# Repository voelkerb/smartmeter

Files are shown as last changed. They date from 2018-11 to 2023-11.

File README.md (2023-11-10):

# SmartMeter

The SmartMeter is a WiFi and Ethernet equipped electricity meter that to be installed in a home's fuse box. 
The development started with hardware [Version 1.0](/Schematic/Version_1). It consists of an ESP32 microcontroller and a dedicated electricity monitoring chip. As the main idea behind this project was to record voltage and current waveforms at higher frequencies, several drawbacks for this use case were fixed with Hardware [Version 2.0](/Schematic/Version_2). It features the same Microcontroller but with 8MB internal storage for data buffering, an RTC for precise time keeping while sampling, a faster USB serial connection with up to 12Mbaud and a 100Mbit ethernet interface.

If you are just interested in the consumption of a single appliance, see the [PowerMeter](https://github.com/voelkerb/powermeter) instead.

## Why to use?
It's open source, easy to use, easy to build and offers lots of flexibility. 

The hardware is...
* tested to work reliable with 230V.
* rather cheap (all components sum up to around 70€).

The firmware supports...
* existing 2.4GHz WPA2 networks or can create its own network.
* to receive commands via USB, TCP or MQTT.
* to store the configuration in the internal non volatile memory.
* to provide data at sampling rates from 1/5Hz all the way up to 32kHz.
* to calibrate the measurements.
* integration into most existing smart home systems e.g. HomeKit (via homebridge and MQTT).
* FFMpeg streaming. This allows to store high frequency data directly into files (e.g. MKV).

## How to build one?
You want to build your own SmartMeter? As the PCBs are provided in this repo, you can simply make your own.

Depending on your requirements, you might either build [Version 1.0](/Schematic/Version_1) or [Version 2.0](/Schematic/Version_2). 
* [Version 1.0](/Schematic/Version_1)
    * Benefits: 
        * The parts are cheaper (around 50€).
    * Drawbacks:
        * Cannot stream data of more than 8kHz.
        * No ethernet interface.
* [Version 2.0](/Schematic/Version_2)
    * Benefits: 
        * 8MB of internal storage allows to buffer data. If you stream high frequency data at e.g. 2kHz, this can hold up to 200s of data on network dropouts.
        * An RTC keeps track of time allowing you to synchronize sampling rates during high frequency sampling.
    * Drawbacks:
        * A little bit more expensive (parts around 70€).

Steps to build your own SmartMeter:
1. Make the PCB ([Version 1.0](/Schematic/Version_1) or [Version 2.0](/Schematic/Version_2)) with [SampleBoard](/Schematic/SampleBoard)). I recommend to use [JLC](https://jlcpcb.com) as it is super cheap and the quality is still decent.
2. Buy the parts listed under [BOM](/BOM).
3. Solder everything together. We used a small reflow oven, but it could also be done using a fine soldering iron. 
4. Buy a matching housing. We highly recommend to use [this one](https://www.voelkner.de/products/694730/Weltron-MR9-C-FA-RAL7035-ABS-Hutschienen-Gehaeuse-157.5-x-90-x-68-ABS-Lichtgrau-RAL-7035-1St..html) as the PCB was specially designed for it, the mounting holes match, and it is safe to use with 230V. It further can be installed inside fuse boxes at regular DIN rails. Also see the CAM milling files to generate cutouts for USB and ethernet and mounting plates for the sampler board (see [Housing](/Hosuing)). 
5. Install the SmartMeter at the DIN rail inside fuse box (that should be done by an electrician).

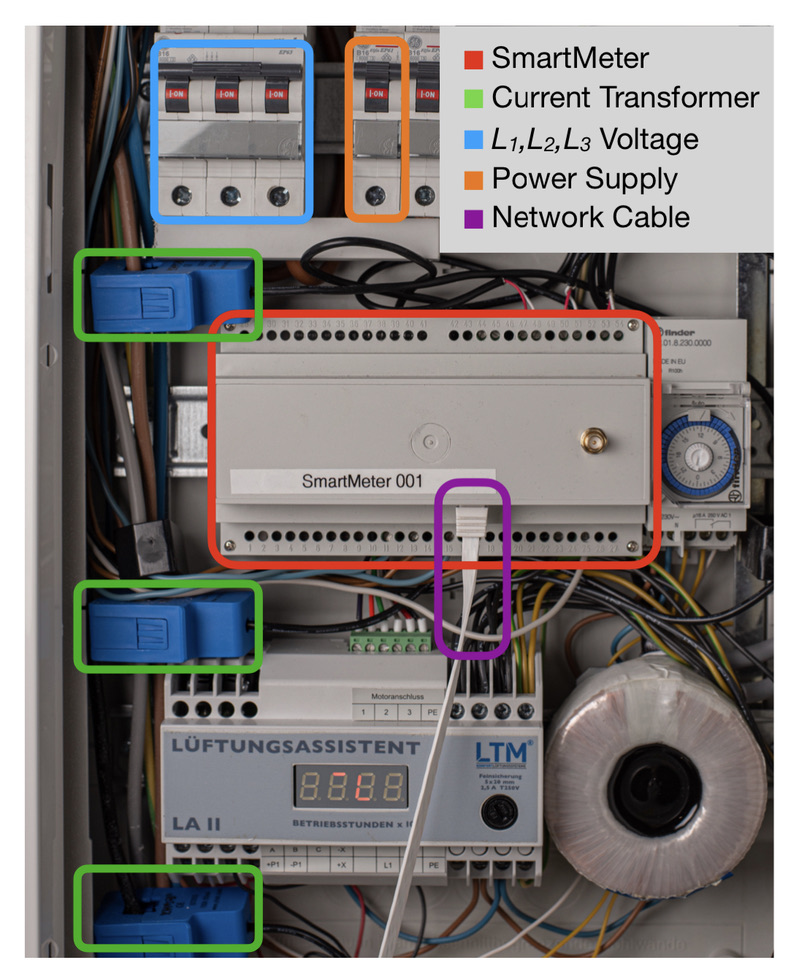
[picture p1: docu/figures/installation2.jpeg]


6. Wire the SmartMeter using the following diagram. 

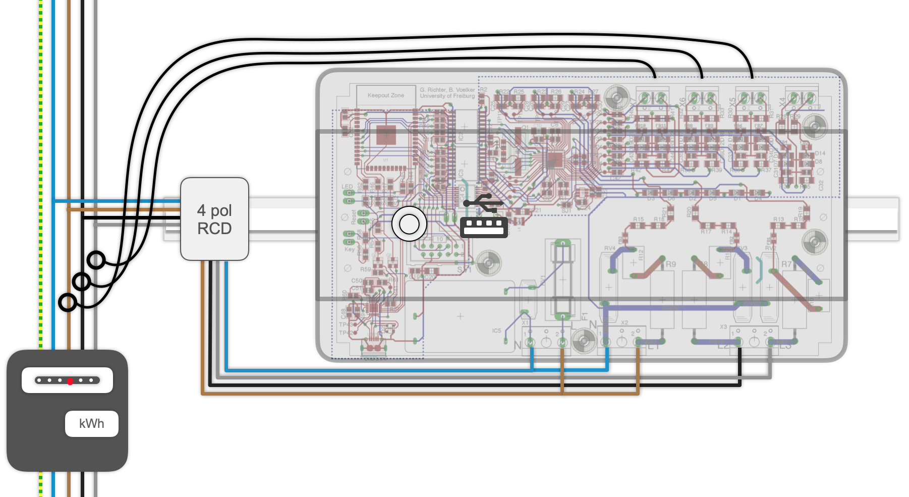
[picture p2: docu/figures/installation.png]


7. Upload the [firmware](/Firmware) according to the instructions for your version. 
8. Interface with the SmartMeter accordingly as stated [here](/docu/README_Firmware_Cmds.md) 

# Use cases
## Smart homes
There are plenty of use cases for a smart plug inside a smart home.
* Get the power consumption of your home using a voice assistant or your smartphone
* Include it in home automation software to switch appliances based on an automation. There are lots of possibilities here, e.g.: 
    * Trigger an alert if the consumption exceeds a limit.
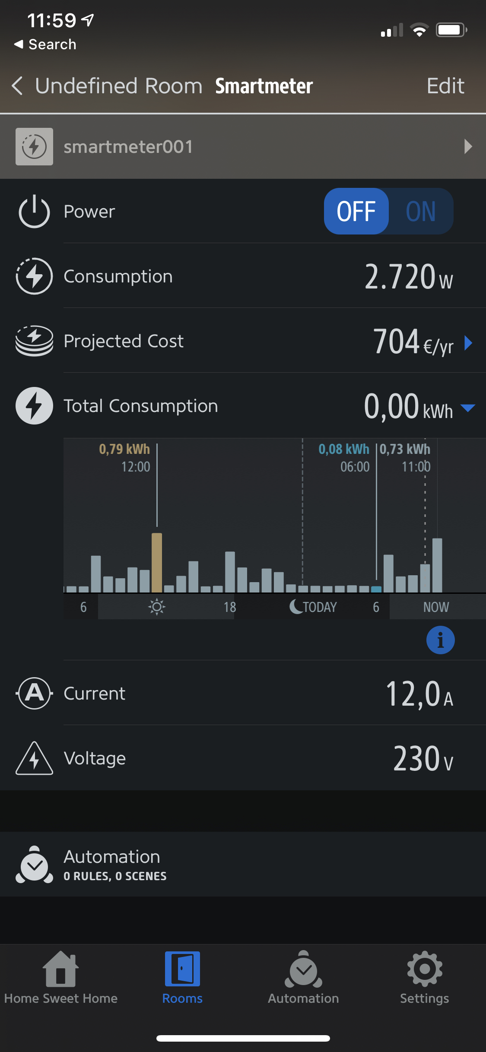
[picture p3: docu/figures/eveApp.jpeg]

* Implement your own Non-Intrusive Load Monitoring System to get the individual appliance power consumption without adding smart plugs to each and every appliance.
* Monitor the power consumption of your home over day.
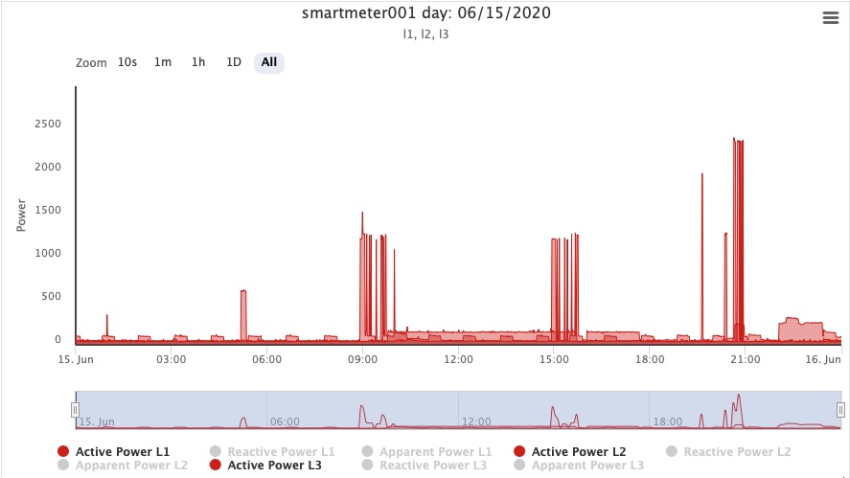
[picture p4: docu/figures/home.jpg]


## For research purpose
* Analyze high frequency voltage and current waveforms.
* Record high frequency electricity datasets (see e.g. the [FIRED](https://github.com/voelkerb/FIRED_dataset_helper) dataset which can be used for Non-Intrusive Load Monitoring).

# License:
## Firmware:
Copyright (c) 2019 Benjamin Völker. All rights reserved.
This work is licensed under the terms of the [CC 4.0 licence](https://creativecommons.org/licenses/by/4.0/).

## Hardware:
Copyright (c) 2019 Benjamin Völker. All rights reserved.
This work is licensed under the terms of the [TAPR Open Hardware License](https://web.tapr.org/TAPR_Open_Hardware_License_v1.0.txt).

# Reference

Please cite our publications if you compare to or use this system:
* Benjamin Völker, Philipp M. Scholl, and Bernd Becker. 2019. Semi-Automatic Generation and Labeling of Training Data for Non-intrusive Load Monitoring. In Proceedings of the Tenth ACM International Conference on Future Energy Systems (e-Energy '19). Association for Computing Machinery, New York, NY, USA, 17–23. DOI:https://doi.org/10.1145/3307772.3328295
 
* Benjamin Völker, Marc Pfeifer, Philipp M. Scholl, and Bernd Becker. 2020. FIRED: A Fully-labeled hIgh-fRequency Electricity Disaggregation Dataset. In Proceedings of the 7th ACM International Conference on Systems for Energy-Efficient Buildings, Cities, and Transportation (BuildSys '20). Association for Computing Machinery, New York, NY, USA, 294–297. DOI:https://doi.org/10.1145/3408308.3427623

* Völker, B.; Pfeifer, M.; Scholl, P.M.; Becker, B. A Framework to Generate and Label Datasets for Non-Intrusive Load Monitoring. Energies 2021, 14, 75. https://doi.org/10.3390/en14010075

Kudos also go to Gregor Richter for developing the first draft schematics prior to [Version 1.0](/Schematic/Version_1).

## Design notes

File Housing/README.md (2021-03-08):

[smartmeter]: (https://github.com/voelkerb/smartmeter)

# Rough PCB Model
You can use the [circuit board](housing/SmartMeter.SLDASM) design file to design custom enclosures for the PCBs.

We encourage you to use the off-the-shelf case which can be found at [here](https://www.voelkner.de/products/694730/Weltron-MR9-C-FA-RAL7035-ABS-Hutschienen-Gehaeuse-157.5-x-90-x-68-ABS-Lichtgrau-RAL-7035-1St..html) as you are working with 230V.
The PCBs were specially designed for this case and perfectly match into its mounting holes. The case offers a secure encapsulation, provides enough room and is rather inexpensive.

As the PCBs are designed in Eagle, the corresponding 3D models can also be imported directly in Fusion360.

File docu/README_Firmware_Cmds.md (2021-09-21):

[SmartMeter]: (https://github.com/voelkerb/SmartMeter)

# How to interface with a SmartMeter

## The Basics
The [SmartMeter] has to be connected to power. \
At first boot, the [SmartMeter] will open a WiFi-Network called "smartmeterX".\
It is not password protected, so you can simply connect to it. 
Open a TCP connection to IP ```smartmeterX.local``` (or ```192.168.4.1```) at port ```54321```.
This will show you basic information of the [SmartMeter] as a JSON encoded messages.
```bash
Info:{"cmd":"info","type":"SmartMeter","version":"2.2","compiled":"Mar_2_2021_09:57:58","sys_time":"03/02/2021 10:37:07.662","name":"smartmeterX","ip":"192.168.4.1","mqtt_server":"-","stream_server":"-","time_server":"time.google.com","sampling_rate":4000,"buffer_size":3670016,"psram":true,"rtc":false,"calV":1,"calI":1,"state":"idle","relay":1,"calibration":[1,1],"ssids":"[energywifi]","ssid":"-","rssi":-71,"bssid":"-"}
```
You will further notice that a lifeness log messages is sent each second.
We will further see how to use commands to interface with a SmartMeter.

**Each command sent to the [SmartMeter] over USB or a TCP channel requires JSON encoding and is answered by a JSON encoded answer message preceded by a the text "Info:". If an error occurred while processing the commmand, the error key is set true in the returned JSON.**

**Each command sent to the [PowerMeter] over USB or a TCP channel requires JSON encoding as ```{"cmd":<cmdName>,[optional]}``` and is answered by a JSON encoded answer message preceded by a the text "Info:". If an error occurred while processing the commmand, the error key is set true in the returned JSON.**

## Overview
| CMD | Description 
| --- |---|
| ["info"](#info) | Get basic information |
| ["getPower"](#getting-energy-data) | Get active, reactive and apparent power |
| ["getVoltage"](#getting-energy-data) | Get current RMS voltage level |
| ["getCurrent"](#getting-energy-data) | Get RMS current |
| ["getEnergy"](#getting-energy-data) | Get energy in Wh and time period |
| ["getPeriod"](#getting-energy-data) | Get current net frequency |
| ["getPhaseAngle"](#getting-energy-data) | Get phase angle between voltage and current  |
| ["mdns"](#name) | Set new mDNS and general [PowerMeter] name |
| ["addWifi"](#wifi) | Add WiFi AP |
| ["delWifi"](#wifi) | Remove WiFi AP |
| ["calibration"](#calibration) | Set calibration parameter |
| ["restart"](#restart) | Restart [PowerMeter] |
| ["dailyRestart"](#restart) | Schedule reset every day |
| ["factoryReset"](#reset) | Reset to standard values |
| ["basicReset"](#reset) | Reset everything but the name |
| ["resetEnergy"](#reset-energy) | Reset accumulated energy |
| ["sample"](#using-a-sampling-command) | Start receiving high frequency data |
| ["reqSamples"](#using-a-sampling-command) | Get certain amount of high frequency samples |
| ["cts"](#pause-streaming) | Allow/forbid to stream samples |
| ["stop"](#stop-streaming) | Stop receiving data |
| ["log"](#log-level) | Change log level |
| ["clearLog"](#log) | Clear logs |
| ["getLog"](#log) | Returns all warning and error log messages |
| ["mqttServer"](#mqtt) | Set MQTT server |
| ["streamServer"](#using-a-stream-server) | Set stream server |
| ["ntp"](#time-synchronization) | Trigger NTP sync |
| ["timeServer"](#time-synchronization) | Set time server for NTP |

## Info
```{"cmd":"info"}```\
The info command will print information about the [SmartMeter]. As this is the most often required command, it is automatically sent to each new connected TCP client. 

## Log Level
```{"cmd":"log","level":<logLevel>}```\
Choose between the following log levels: ```all, debug, info, warning, error```\
Each new connection is initialized with log level ```info```.
```bash
Info:{"error":false,"msg":"Log Level set to: warning"}
```

## Name
```{"cmd":"mdns","payload":{"name":"<newName>"}}```\
This command should be used to give the [SmartMeter] a new unique name.
It will be used to announce presence over MDNS and if no known network is found, an AP is opened using this name.

```bash
Info:[I]03/02 10:42:24: MDNS Name: smartmeterX
Info:{"error":false,"msg":"Set MDNS name to: smartmeterX","mdns_name":"smartmeterX"}
```

## Restart
```{"cmd":"restart"}```\
Restarts the [SmartMeter]. The TCP connection will be lost.

## Reset
```{"cmd":"factoryReset"}```\
Resets everything to defaults. The default values are:
- name: _smartmeterX_
- wifi aps: _energywifi_ -> (pwd: _silkykayak943_)
- timeserver: _time.google.com_
- streamserver: -
- mqtt broker: -
- _energy<LX><U/I>_ = 1.0
- _energy<LX>_ = 0
- _resetHour_ = _resetMinute_ = -1

If you want to reset everything except the name, use: ```{"cmd":"basicReset"}```

## Log
```{"cmd":"getLog"}```\
The [SmartMeter] has some decent logging capabilities. Despite logging over a connected TCP connection and Serial. _Warning_ and _Error_ messages are logged to internal flash memory.
The _getLog_ command will dump the all logs in the flash and contains two JSON response messages.
```bash
Info:{"cmd":"log","msg":"*** LOGFile *** [E]03/02 11:26:20: Cannot connect to MQTT Server -//n*** LOGFile *** "}
Info:{"error":false}
```
All newlines are replaces by "_//n_".\
To clear all log messages, use ```{"cmd":"clearLog"}```.

## Calibration
```{"cmd":"calibration","cal":[<calV_l1>,<calI_l1>,<calV_l2>,<calI_l2>,<calV_l3>,<calI_l3>]```\
Calibrate the [SmartMeter].
```<calV_LX>``` and ```<calI_LX>``` are floating point values with the default value 1.0.
Every measured voltage and current value is multiplied by the calibration factor. Power and Energy are multiplied by ```<calV_LX>```*```<calI_LX>```.

## Reset Energy
```{"cmd":"resetEnergy"}```\
Simply resets the accumulated energy stored in flash. 

## Time synchronization
```{"cmd":"ntp"}```\
Will perform an NTP time synchronization.
```
Info:[I]03/02 11:28:14: NTP synced with conf: 11
Info:{"msg":"Time synced","error":false,"current_time":"03/02/2021 11:27:40.182"}
```
To set a new NTP timeserver, use the command: ```{"cmd":"timeServer", "payload":{"server":"<serverAddress>"}}```. The _serverAddress_ can be also be its DNS name e.g. time.google.com
```bash
Info:[I]03/02 11:28:14: NTP synced with conf: 11
Info:{"error":false,"msg":"Set TimeServer address to: time.google.com","time_server":"time.google.com"}
```

## WiFi
Add wifi AP: ```{"cmd":"addWifi", "payload":{"ssid":"<ssidName>","pwd":"<pwdName>"}}```
```bash
Info:{"error":false,"ssid":"Test","pwd":"TestPwd","msg":"New Ap, SSID: Test, PW: TestPwd","ssids":"[energywifi, Test]"}
```
Remove a wifi AP: ```{"cmd":"delWifi", "payload":{"ssid":"<ssidName>"}}```
```bash
Info:{"error":false,"msg":"Removed SSID: Test","ssids":"[energywifi]"}
```

## MQTT
Once connected to an MQTT server, the SmartMeter will publish the current power consumption each 5 seconds and each state change of the relay. 
To set the MQTT server, use the command: ```{"cmd":"mqttServer", "payload":{"server":"<ServerAddress>"}}```
Currently, only the MQTT standard server port ```1883``` is supported. 
```bash
Info:[I]03/02 11:38:42: MQTT connected to 192.168.0.13
Info:[I]03/02 11:38:42: Subscribing to: SmartMeter/+
Info:[I]03/02 11:38:42: Subscribing to: SmartMeter/smartmeterX/+
Info:{"error":false,"msg":"Set MQTTServer address to: 192.168.0.13","mqtt_server":"192.168.0.13"}
```

NOTE: In sampling mode, MQTT is disabled for performance reason.

### Receiving MQTT messages
Each 5 seconds, information about the power consumption is sent.
It contains the sum of the _active power_ in _Watt_ and _active energy_ in _kWh_ of all grid lines, the mean of the _RMS voltage_ in _V_ of all grid lines, the sum of the _RMS current in _A_ of all grid lines and the current timestamp.
You can also enable 
```bash
powermeter/smartmeter001/state/sample {"power":1116.89,"current":4.82,"volt":236.56,"ts":"1614681575"}
```

### Sending MQTT messages
Mqtt can also be used to send any command. Special topics are used to switch the relay or to get basic electricity related measurements, but any of the available commands can be sent.
* Sample a single value using topic ```powermeter/<name>/sample``` and message one of ```v,i,p,q,s``` (_RMS voltage_,_RMS Current_, _active_, _reactive_, or _apparent power_ ). On no, or any other message, the _active power_ is sent.
  ```bash
  mosquitto_pub -h 192.168.0.13 -t 'powermeter/smartmeter001/sample' -m 'v'
  ````
  The response contains a JSON dictionary with the key _value_, _unit_ and _ts_, example:
  ```bash
  powermeter/smartmeter001/state/info {"value":"228.43,228.48,228.33","unit":"V","ts":"03/08/2021 11:42:34.848"}
  ```
  The individual values represent the values for the indivudal grid lines (L1, L2, L3)
* You can also send any command, which can be sent over a bare TCP connection using topic ```powermeter/<name>/cmd```
  ```bash
  mosquitto_pub -h 192.168.0.13 -t 'powermeter/smartmeter001/cmd' -m '{"cmd":"info"}'
  ````
* If you have multiple SmartMeters and want to send the message to all at the same time (e.g. to change some global settings such as the MQTT broker), you can simple ditch the specific SmartMeter name and all will answer. 
  ```bash
  powermeter/sample p
  powermeter/smartmeter001/state/sample {"value":"228.43,228.48,228.33","unit":"V","ts":"03/08/2021 11:42:34.848"}
  powermeter/SmartMeter002/state/sample {"value":"228.44,228.45,229.10","unit":"V","ts":"03/08/2021 11:42:34.947"}
  ...
  ```

## Getting Energy Data
To obtain one shot measurements, several commands exist for all kinds of electrical quantities.
All data is returned as a JSON dict with the command and the measurement's unit.

* ```{"cmd":"getPower"}```\
Returns active, reactive and apparent power.

* ```{"cmd":"getVoltage"}```\
Returns RMS voltage level.

* ```{"cmd":"getCurrent"}```\
Returns RMS current level.

* ```{"cmd":"getEnergy"}```\
  Returns energy since reset for all three supply legs. Includes time span.
  ```bash
  Info:{"error":false,"cmd":"getEnergy","energy":[10149.5684,5101.23238,4509.21022],"unit":"Wh","startTs":1632219770,"start":"09/20/2021 12:22:50.068","days":1}
  ```

* ```{"cmd":"getPeriod"}```\
Get current net frequency. Resolution is 8us according to datasheet.

* ```{"cmd":"getPhaseAngle"}```\
Returns phase angle between voltage and current.

## Getting High Frequency Data
Finally, to get some high frequency data out of the SmartMeters beyond whats possible using [mqtt](#mqtt), you have multiple possibilities. 

### Using FFmpeg
Using ffmpeg is by far the most simple way to store high frequency data. Thus, the sampling rate remains at 4kHz and only current and voltage measurements are streamed.
On your host computer, simply install [ffmpeg](https://ffmpeg.org) and run the following:
```bash
ffmpeg -nostdin -hide_banner -fflags +nobuffer+flush_packets -f f32le -ar 9000.0 -guess_layout_max 0 -ac 2.0 -flush_packets 1 -thread_queue_size 512 -analyzeduration 0 -i tcp://<SmartMeterIP>:54322 -c:a wavpack -frame_size 8000 -metadata:s:a:0 CHANNELS=2 -metadata:s:a:0 CHANNEL_TAGS="v_l1,i_l1,v_l2,i_l2,v_l3,i_l3" -metadata:s:a:0 title="<smartmeterName>" -map 0 -y output.mkv 
```
You can directly use the MDNS name for ```<smartmeterIP>```. Some of the settings in call such as the metadata are of course optional. 

### Using a stream server
At your future data sink (which simply might be your computer), host a TCP server at port ```54322```.
Find you IP address and set it as the target stream server for each SmartMeter using the command ```{"cmd":"streamServer", "payload":{"server":"<YourIp>"}}```.
The [SmartMeter] will check if the stream server is available each 30s and automatically connects to it.
For the data format, see [Data Format](#data-format).

### Using a sampling command
This is the most complicated command of the SmartMeter. It has multiple and potentially optional parameter which will be explained in the following. 
```bash
{"cmd":"sample", "payload":{"type":"<type>", "measures":"<measures>", "rate":<rate>, "prefix":<prefix>, "port":<port>,"time":<time>,"flowCtr":<flowCtr>,"slot":[<slot>,<slots>],"ntpConf":<ntpConf>}}
```
Example:
The response for the command ```{"cmd":"stop","payload":{"type":"TCP","rate":1}}``` is:
```bash
Info:{"error":false,"measures":"v,i","chunksize":8,"samplingrate":1,"conn_type":"TCP","measurements":2,"prefix":true,"flowCtr":false,"cmd":"sample","unit":"V,mA","startTs":"1614697441.119"}
```

Parameters:
* ```<type>``` + optional: ```<port>```: The Type of the data stream.
  * "Serial": sampled data is sent over USB Serial connection
  * "TCP": sampled data is sent over TCP connection (the one you opened to it). 
  * "UDP": sampled data is sent over a UDP connection. You need to specify the UDP Port with ```<port>```.
  * "MQTT": sampled data is sent over MQTT (broker must be set, see [MQTT](#mqtt)). 
  * "FFMPEG": connect with an ffmpeg call to the stream server on port ```54322```. No prefix is supported and no line ending, just the raw data. Can be used directly with ffmpeg streaming. Allows to change settings while using [ffmpeg streaming](#using-ffmpeg).

* ```<rate>```: The goal sampling rate of the data.
  * Integer value between 1 and 32000 (default: 8000)

* ```<measures>``` (optional):
  * "v,i" or "v,i,v,i,v,i": will return 3x _voltage_ and _current_ as "v_l1,i_l1,v_l2,i_l2,v_l3,i_l3"
  * "v,i_L1": will return _voltage_ and _current_ of L1
  * "v,i_L2": will return _voltage_ and _current_ of L2
  * "v,i_L3": will return _voltage_ and _current_ of L3
  * "p,q" or "p,p,p,q,q,q": will return 3x _active_ and _reactive power_ as "p_l1,p_l2,p_l3,q_l1,q_l2,q_l3"
  * "v,i_RMS" or "v,v,v,i,i,i_RMS": will return 3x _RMS voltage_ and _RMS current_
  * Default: "v,i"

* ```<prefix>``` (optional):
  * "true" or "false": if _true_, each chunk of measurement will be sent with the prefix ```"Data:"<chunk_length><packet_num><data>```
  * ```<chunk_length>```: 2 bytes stating the length the amount of bytes in ```<data>```, format: _```<H```_
  * ```<packet_num>```: running packet number as 4 bytes integer, format: _```<I```_
  * Default: _true_

* ```<ntpConf>``` (optional):
  * Integer, interpreted as milliseconds. The NTP request before starting the sampling needs to be confident within this threshold value. 
  * NOTE: NTP requests are send over UDP to the specified NTP server. The time it takes to get the answer needs to be considered as well for millisecond resolution. As the request has to be sent to the server and from the server back to the [SmartMeter], half of the time the request took is added to the received NTP time. The request is thus only confident up to the time it took to receive the response, as in the worst case - if a response took 10ms - it could be 0ms for sending to the server and 10ms for getting the response. This would mean, the time is off the actual time about 5ms - which is our confidence level. As most sampling is stored relative (start time + sampling rate), getting the start time as exact as possible is crucial. 
  * Default: no NTP request is sent

* ```<flowCtr>``` (optional):
  * "true" or "false": if _true_, the sink has to request _x_ amount of samples with the ```reqSamples``` command or actively enable sending with a [cts](#pause-streaming) command.
  * Default: _false_
  * Request ```<numSamples>``` using the command: ```{"cmd":"reqSamples","samples":<numSamples>}```
    * ```<numSamples>```: long, must be between 10 and 2000
    * NOTE: In order for the command to work, the [SmartMeter] must be sampling and during the sampling command ```flowCtr``` must have been set to _true_!

* ```<time>``` (optional):
  * Unix timestamp at which sampling should be started. The timestamp must be in the future more than 500ms but is not allowed to be further in time then 20s. 
  * NOTE: This can be used to start sampling with multiple devices at an exact point in time. Sampling further starts at a positive voltage zero crossing. Therewith, SmartMeters at the same phase are synchronized within 1/f<sub>L</sub> with f<sub>L</sub> being the grid line frequency.  
  * Default: Sampling is started immediately 

* ```[<slot>,<slots>]``` (optional):
  * ```<slot>``` integer, the slot number in which data is sent
  * ```<slots>``` integer, the total number of slots
  * The idea is that only one device sends data at the same time in a network with multiple device ```d_i```. Each device will only send data if the following condition is true: ```now.seconds%slots == slot```
  * Example: 3 devices _d<sub>i</sub>_ with configs: _d<sub>0</sub> = [0,3]_, _d<sub>1</sub> = [1,3]_, _d<sub>2</sub> = [2,3]_. All devices send data each 3 seconds. e.g. _d<sub>0</sub>_ at second _0,3,6,..._ 
  * NOTE: This only works, if all data sampled can be send out in this second. If you e.g. have 10 devices, one device has to send 10s of data every 10s within just 1s. If the SmartMeter is not able to sent all data within this second, buffer overflows will occur. However, it avoids wifi/tcp collisions caused by multiple SmartMeters.
  * Default: _false_

### Pause streaming
You can use flow control during sampling with the command: ```{"cmd":"cts","value":<value>}```
* ```<value>``` can be _true_ or _false_. _True_ to let device stream data, _false_ to pause.
* NOTE: does not necessarily have to be paired with sampling in which ```flowCtr``` was set to _true_.

### Stop streaming 
```{"cmd":"stop"}```\
Send this command to stop sampling or streaming. As a response, you get information about the sampling process.
```bash
Info:{"msg":"Received stop command","sample_duration":16157,"samples":16,"sent_samples":16,"start_ts":"1614697441.119","stop_ts":"1614697457.276","ip":"192.168.0.138","avg_rate":0.955618,"cmd":"stop"}
```

## Misc
### Availability
You can send ```?``` without a JSON encoding to test if the device is still reachable. It will return ```Info: Setup done``` and will stop sampling! (Just for backward compatibility)

### Keepalive
As a keepalive command, you can send ```!```. This simply gets ignored but might prevent the TCP connection from being closed automatically if nothing is sent.

## Data Format
The data is returned encoded as 32 Bit MSB first float values.
If not explicitly disabled using ```"prefix":"false"```, data is preceded by a prefix.\
```"Data:"<chunk_length><packet_num><data>```
  * ```<chunk_length>```: 2 bytes describing the length of this data chunk, format: _```<H```_
  * ```<packet_num>```: running packet number as 4 bytes integer, format: _```<I```_
If disable or the stream type is set to FFMPEG, just the ```<data>``` is returned.

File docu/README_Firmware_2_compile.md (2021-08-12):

[smartmeter]: (https://github.com/voelkerb/smartmeter)

# How to compile Firmware Version 2

## Preprocessor Settings

Before you want to compile the code, make sure the preprocessor settings are as you want them to be.
Take a look at [constDefine.h](https://github.com/voelkerb/PowerMeter/blob/master/Firmware/Version_2/constDefine.h).
The PowerMeter supports multiple addons such as LoRa or an additional sensor board. Depending on your configuration, the preprocessor settings must be set correctly. 

### Standard Settings:
You can set some standard WiFi configurations which will also be kept on a configuration reset. Simply add you WiFi credentials to a file named ```privateConfig.h``` under _src/config/_  
```c++
#define NUM_STANDARD_WIFIS 2

const char * MY_STANDARD_WIFIS[] = {
     /*SSID*/ "mySecretAP1", /*PWD*/ "mySecret1",
     /*SSID*/ "mySecretAP2", /*PWD*/ "mySecret2",
};
```

### General Settings:

* ```SENT_LIFENESS_TO_CLIENTS```: Uncomment to send lifeness messages with the current system time each second to connected TCP clients or over serial.
* ```REPORT_ENERGY_ON_LIFENESS```: Uncomment to send energy info as lifeness messages.
* ```REPORT_INDIVIDUAL_GRID_LINE_VALUES```: Uncomment to include the individual leg consumption on Lifeness and MQTT messages.
* ```LIFENESS_UPDATE_INTERVAL```: Interval for sending lifeness messages.
* ```SEND_INFO_ON_CLIENT_CONNECT```: Uncomment to send system info JSON dictionary automatically on TCP client connect.
* ```USE_SERIAL```: Comment to disable serial, uncomment if you want to use serial.
* ```SERIAL_SPEED```: Baudrate of any serial connection. The serial connectors are accessible via the extension header.
* ```SERIAL_LOGGER```: Uncomment if you want log messages to be sent via serial.
* ```LOG_PREFIX_SERIAL```: Prefix for logs over serial connection.
* ```CMD_OVER_SERIAL```: Uncomment if you want commands to be processed via serial.
* ```PS_BUF_SIZE```: Amount of PSRAM for data buffering. Arduino does only support up to 3.5MB.
* ```DEFAULT_SR```: Default samplingrate.
* ```LOCATION_TIME_OFFSET```: Location time offset from UTC. 
* ```MDNS_UPDATE_INTERVAL```: Interval for MDNS updates.
* ```TCP_UPDATE_INTERVAL```: Interval for adding TCP clients.
* ```RTC_UPDATE_INTERVAL```: Interval for updating the RTC's time.
* ```ENERGY_UPDATE_INTERVAL```: Interval energy is stored to flash. If no energy is reported, this is also the interval it is updated. Keep it reasonable (<60s) to prevent register overflow. 
* ```STREAM_SERVER_UPDATE_INTERVAL```: Interval for checking if an external TCP server is ready to receive data.
* ```MQTT_UPDATE_INTERVAL```: Interval to send energy info over MQTT.
* ```LOG_PREFIX```: Prefix for logs via TCP connection.
* ```DATA_PREFIX```: Prefix for data via TCP connection.

### Connection Settings:

* ```STANDARD_UDP_PORT```: Standard port for UDP connections.
* ```STANDARD_TCP_SAMPLE_PORT```: Standard port for TCP connections.
* ```STANDARD_TCP_STREAM_PORT```: Standard port for TCP streaming e.g. via ffmpeg.
* ```MAX_CLIENTS```: Allow at max this many TCP clients.
* ```MAX_SEND_SIZE```: Maximum chunk size for data. Chunksize is set dynamically depending on the samplingrate.  

### NTP Sampling Correction

* ```NTP_CORRECT_SAMPLINGRATE```: If NTP synchronizations should be used to correct the sampling rate by means of repeating or leaving out samples.
* ```NTP_CONFIDENCE_FOR_CORRECTION```: Required confidence for NTP sampling correction in milliseconds.
* ```CORRECT_SAMPLING_THRESHOLD```: Drift in seconds when sampling correction should be applied.
* ```MAX_CORRECT_SAMPLES```: Maximum number of samples to correct for one sync.

## Compile from source using Arduino or PlatformIO

* In order to upload the firmware, you must install the latest version of the Arduino ESP32 environment. See [official instructions](https://github.com/espressif/arduino-esp32/blob/master/docs/arduino-ide/boards_manager.md):
  * Enter _https://raw.githubusercontent.com/espressif/arduino-esp32/gh-pages/package_esp32_index.json_ into _Arduino > Settings > Additional Board Manager URLs_ field.
  * Open Boards Manager from _Tools > Board_ menu and install _esp32 platform_
* Select _ESP32 Dev kit_ with _240MHz_ and _PSRAM enabled_ from _Tools > Board_ 

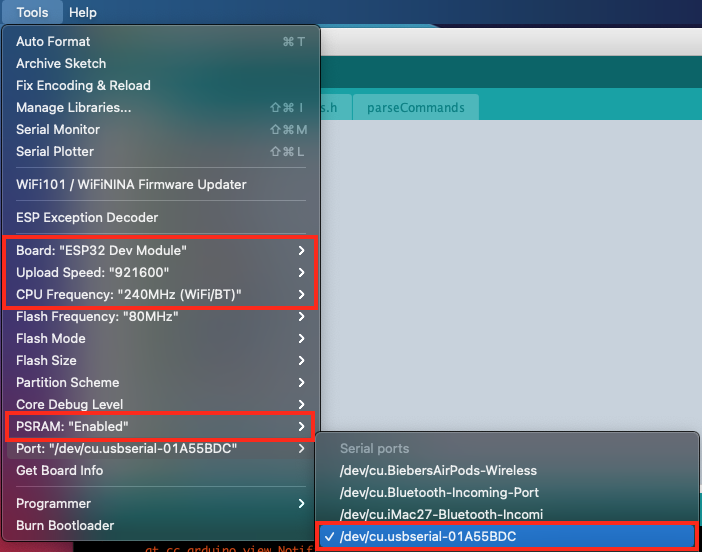
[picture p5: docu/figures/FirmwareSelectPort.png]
    
    
* Open the latest firmware "Version_X_X".
* Press _Compile_

## Upload using USB interface

* Connect the [smartmeter] (SampleBoard) to USB
* Select no more than 2Mbauds
* Press _Compile and Upload_

## Upload using Arduino-OTA

* Select the [smartmeter] you want to upload to from the available network ports
* If the corresponding [smartmeter] is not shown, make sure you are in the same network or try to reset the [smartmeter].

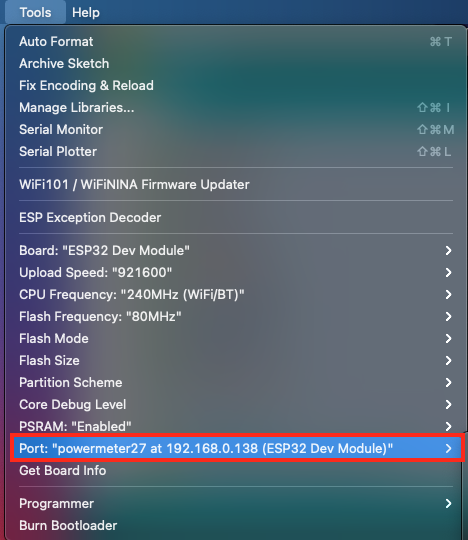
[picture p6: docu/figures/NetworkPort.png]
    

* Upload using password "energy"

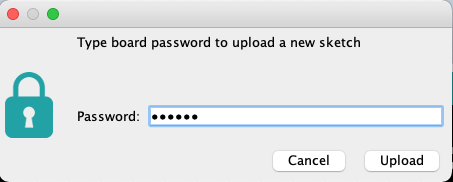
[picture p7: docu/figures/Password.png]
    

## Upload using custom Uploader

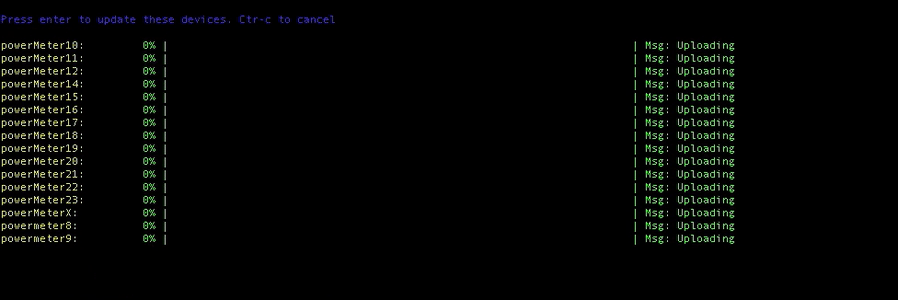
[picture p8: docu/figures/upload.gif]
  

* Compile the firmware
* Copy the path of the compiled binary _elf_ or _bin_ (the _bin_ will be used either way)

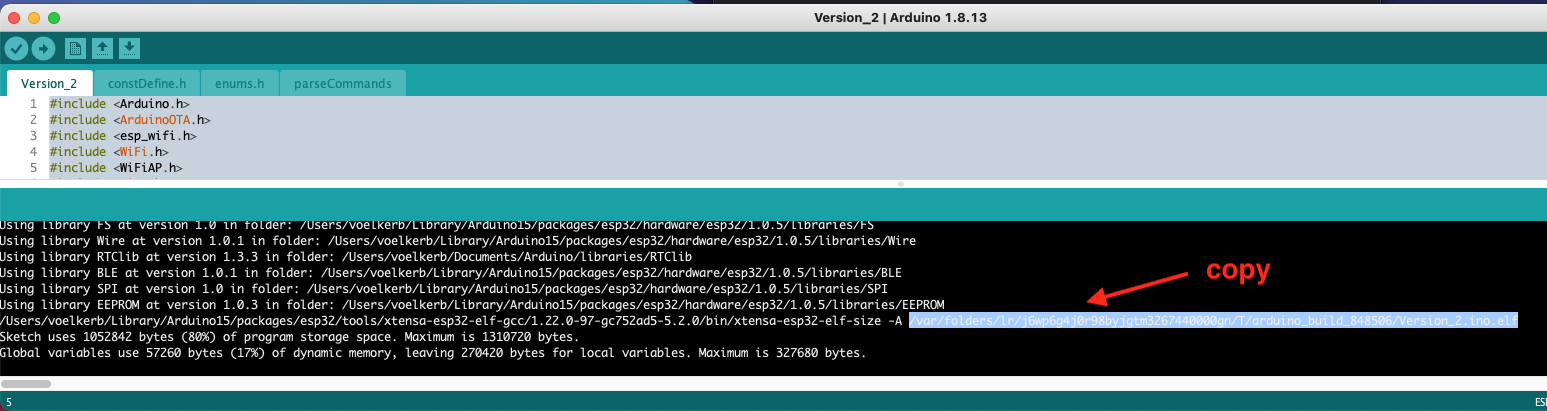
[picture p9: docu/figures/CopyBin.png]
    

* Use the upload script
  ```bash
  python3 upload.py smartmeter <pathToElfOrBin> 
  ```
  Select one or mulitple [smartmeter] from the provided list
  ```
  Available Devices:
  #  smartmeter:              Device:                  IP:                      
  0  smartmeter001            smartmeter001            192.168.0.145      
  Press ENTER to continue with all devices.
  Deselect specific devices e.g.: -2,-4,-7
  Select specific devices e.g.: 1,3,5,6
  Search again a/A
  Press r/R to reset
  e/E to cancel Or press CTR-C to exit program
  ```
  Press enter and watch the magic

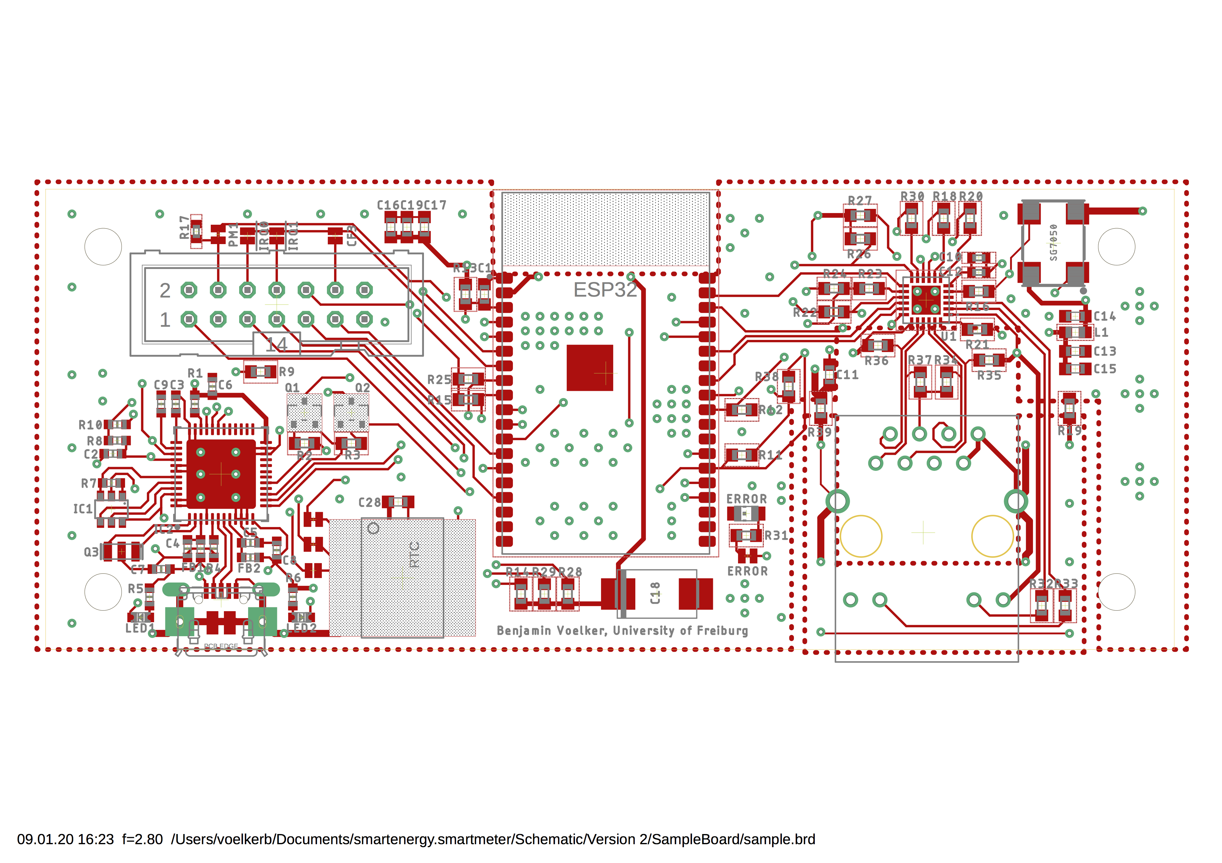
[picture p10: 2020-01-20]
Schematic/SampleBoard/sample.png

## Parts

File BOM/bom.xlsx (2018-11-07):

Description | Schematic Reference | Line Item | Manufacturer | Qty | Remaining parts | Possible boards | Parts to order for | 10 | boards
1u | C1, C22 | VJ0805Y105KXQTW1BC | Vishay | 2 | 100 | 50 | 0
4.7u | C2, C4, C6, C48, C50 | GRM219R61A475KE34D | Murata | 5 | 95 | 19 | 0
0.1u | C3, C5, C7, C11, C12, C13, C14, C15, C16, C17, C18, C19, C23, C24, C47, C49, C51, C52 | C0805C104K3RACTU | KEMET | 18 | 45 | 2 | 144
16p | C8, C9 | 251R15S160JV4E | Johanson | 2 | 4 | 2 | 16
10u | C10 | GRM319R6YA106KA12D | Murata | 1 | 7 | 7 | 3
47u | C20 | T55A476M6R3C0070 | Vishay | 1 | 3 | 3 | 7
6.8u | C21 | T55A685M010C0300 | Vishay | 1 | 2 | 2 | 8
22n | C25, C26, C27, C28, C29, C30, C31, C32, C33, C34, C35, C36, C37, C38, C39, C40, C41, C42, C43, C44, C45, C46 | C2012C0G1H223J125AA | TDK | 22 | 32 | 1 | 198
DIODE | D1, D2, D3, D4, D5, D6, D7, D8, D9, D10, D11, D12, D13, D14, D15, D16, D17, D18, D19, D20, D21, D22 | LL4148 | ON Semiconductor | 22 | 34 | 1 | 198
SP05 Series - 30pF 30kV Unidirectional TVS Array | D23 | SP0503BAHTG | Littelfuse | 1 | 7 | 7 | 3
Fuse | F1-1 | 65600001409 | Littelfuse | 1 | 0 | 0 | 10
Fuse Holder Accessories | F1-2 | 65900000009 | Littelfuse | 1 | 0 | 0 | 10
Ferritperlen | FB1, FB2, FB3, FB4, FB5, FB6, FB7, FB8, FB9, FB10, FB11 | BLM21BD152SN1D | Murata | 11 | 64 | 5 | 55
Strom- und Leistungswächter | IC1 | ADE9000ACPZ | Analog Devices | 1 | 3 | 3 | 7
Digital insulators | IC2, IC3 | ADUM3401CRWZ | Analog Devices | 2 | 4 | 2 | 16
Digital insulator | IC4 | ADUM3150ARSZ | Analog Devices | 1 | 2 | 2 | 8
MEAN WELL AC/DC Power Modules 2W | IC5 | IRM-02-3.3 | Mean Well | 1 | 0 | 0 | 10
Murata Power Solutions, MEF1 Series | IC6 | MEF1S0303SP3C | Murata Power Solutions | 1 | 0 | 0 | 10
 | IC7 | ADR3412ARJZ-R7 | Analog Devices | 1 | 2 | 2 | 8
Single-Chip USB to UART Bridge | IC8 | CP2102N-A01-GQFN24 | Silicon Labs | 1 | 2 | 2 | 8
303010149 | L1 | CBC2518T331M | Taiyo Yuden | 1 | 10 | 10 | 0
CRYSTAL | Q1 | ABLS2-24.576MHZ-D4YF-T | Abracon | 1 | 12 | 12 | 0
Bipolartransistors | Q2, Q3 | MMSS8050-L-TP | MCC | 2 | 98 | 49 | 0
10k | R1, R2, R3, R4, R5, R6, R61 | RC0805FR-0710KL | Yageo | 7 | 83 | 11 | 0
3k3 (large) | R7, R8, R9 | WS5M3301J | Bourns | 3 | 10 | 3 | 21
 | R10, R11, R12 | PTCCL10H010SBE | Vishay | 3 | 0 | 0 | 30
 | R13, R14, R15, R16, R17, R18, R19, R20, R21 | TNPV1206330KBEEN | Vishay | 9 | 0 | 0 | 90
 | R22, R23, R24, R25, R26, R27, R34, R35, R36, R37, R38, R39, R42, R43 | ERA8ARB102V | Panasonic | 14 | 10 | 0 | 140
 | R28, R29, R30, R31, R32, R33, R40, R41 | RP73D2B7R87BTG | TE Connectivity | 8 | 1 | 0 | 80
 | R44, R45, R46, R47, R48, R49, R50, R51, R52, R53, R56, R58, R62 | RC0805FR-07470RL | Yageo | 13 | 63 | 4 | 78
 | R54, R55, R57, R59 | CR0805-JW-123ELF | Bourns | 4 | 96 | 24 | 0
 | R60 | CRCW08051K00FKEA | Vishay | 1 | 99 | 99 | 0
VARISTOR TDK StandarD series B722 | RV1, RV2, RV3, RV4 | B72210S0321K101 | EPCOS | 4 | 12 | 3 | 28
ESP | U1 | ESP-WROOM-32 | Espressif Systems | 1 | 1 | 1 | 9
USB port | USB1 | 10118193-0001LF | FCI | 1 | 7 | 7 | 3

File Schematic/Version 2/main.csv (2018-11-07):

Qty | Value | Device | Package | Parts | Description | MF | MPN | OC_CONRAD | OC_FARNELL | OC_MOUSER | OC_NEWARK | TP_SIGNAL_NAME | VALUE
1 |  | B72210S0321K101 | TDK_E7.5_A2.4_W12.0_TH5.4_H15.0_D0.8 | RV1 | VARISTOR TDK StandarD series B722 |  |  |  |  | 871-B72210S321K101
2 |  | W237-113 | W237-113 | X2, X3 | WAGO SCREW CLAMP |  |  | EAN: 2050002355880 | unknown |  | unknown
1 | 24.576MHz | CRYSTALHC49UP | HC49UP | Q1 | CRYSTAL |  |  |  | unknown | 815-ABLS2-24.5-D4YFT | unknown
1 | 0.2A | FUSESH22,5A | SH22,5A | F1 | Fuse |  |  |  | unknown | 576-65600001409 & 576-65900000009 | unknown
18 | 100n | C-EUC0805 | C0805 | C3, C5, C7, C11, C12, C13, C14, C15, C16, C17, C18, C19, C23, C24, C47, C49, C51, C52 | CAPACITOR, European symbol |  |  |  |  | 80-C0805C104K3R
7 | 10k | R-EU_R0805 | R0805 | R1, R2, R3, R4, R5, R6, R61 | RESISTOR, European symbol |  |  |  |  | 603-RC0805FR-0710KL
1 | 10u | C-EUC1206K | C1206K | C10 | CAPACITOR, European symbol |  |  |  |  | 81-GRM319R6YA106KA2D
4 | 12k | R-EU_R0805 | R0805 | R54, R55, R57, R59 | RESISTOR, European symbol |  |  |  |  | 652-CR0805-JW-123ELF
2 | 16P | C-EUC0805K | C0805K | C8, C9 | CAPACITOR, European symbol |  |  |  |  | 609-251R15S160JV4E
1 | 1k | R-EU_R0805 | R0805 | R60 | RESISTOR, European symbol |  |  |  |  | 71-CRCW0805-1.0K-E3
14 | 1k | R-EU_R1206 | R1206 | R22, R23, R24, R25, R26, R27, R34, R35, R36, R37, R38, R39, R42, R43 | RESISTOR, European symbol |  |  |  |  | 667-ERA-8ARB102V
11 | 1k5 | SMD-FERRITE-BEAD-30R-3A(0805) | L0805 | FB1, FB2, FB3, FB4, FB5, FB6, FB7, FB8, FB9, FB10, FB11 | 303030023 |  | MH2029-300Y |  |  | 81-BLM21BD152SN1D |  |  | 30R 3A
2 | 1u | C-EUC0805 | C0805 | C1, C22 | CAPACITOR, European symbol |  |  |  |  | 77-VJ0805Y105KXQTBC
16 | 22n | C-EUC0805 | C0805 | C31, C32, C33, C34, C35, C36, C37, C38, C39, C40, C41, C42, C43, C44, C45, C46 | CAPACITOR, European symbol |  |  |  |  | 810-C2012C0G1H223J
6 | 22n | C-EUC0805 | C0805 | C25, C26, C27, C28, C29, C30 | CAPACITOR, European symbol |  |  |  |  | C2012C0G1H223J125AA
1 | 230V IN | W237-113 | W237-113 | X1 | WAGO SCREW CLAMP |  |  | EAN: 2050002355880 | unknown |  | unknown
3 | 300VAC | B72220S0301K101 | TDK_E10.0_A2.4_W21.5_TH5.6_H25.5_D1.0 | RV2, RV3, RV4 | VARISTOR TDK StandarD series B722 |  |  |  |  | B72220S0301K101
9 | 330k | R-EU_R1206 | R1206 | R13, R14, R15, R16, R17, R18, R19, R20, R21 | RESISTOR, European symbol |  |  |  |  | 71-TNPV1206330KBEEN
1 | 330uH 0.1A | SMD-INDUCTOR-4.7UH-20%-1.1A(1008) | L1008 | L1 | 303010149 |  | CIG22L4R7MNE |  |  | 963-CBC2518T331M |  |  | 4.7uh 1.1A
3 | 3k3 5W HSR | RAC05 | AC05 | R7, R8, R9 | Power Resitor |  |  |  | unknown | 652-WS5M3301J | unknown
5 | 4.7u | C-EUC0805 | C0805 | C2, C4, C6, C48, C50 | CAPACITOR, European symbol |  |  |  |  | 81-GRM21R61A475KE34D
3 | 400 | PTCCL10H010SBE | PTCCL10H010SBE | R10, R11, R12 | Vishay PTC |  |  |  |  | 594-2381-661-93113
13 | 470 | R-EU_R0805 | R0805 | R44, R45, R46, R47, R48, R49, R50, R51, R52, R53, R56, R58, R62 | RESISTOR, European symbol |  |  |  |  | 603-RC0805FR-07470RL
1 | 47uF | C-EUC3216 | C3216 | C20 | CAPACITOR, European symbol |  |  |  |  | 74-T55A476M6R3C0070
1 | 6.8uF | C-EUC3216 | C3216 | C21 | CAPACITOR, European symbol |  |  |  |  | 74-T55A685M010C0300
8 | 7.87 | R-EU_R1206 | R1206 | R28, R29, R30, R31, R32, R33, R40, R41 | RESISTOR, European symbol |  |  |  |  | 279-RP73D2B7R87BTG
1 | ADE9000 | ADE9000 | QFN40 | IC1 |  |  |  |  |  | 584-ADE9000ACPZ
1 | ADR3412 | ADR3412 | SOT-23-6 | IC7 |  |  |  |  |  | 584-ADR3412ARJZ-R7
1 | ADUM3150ARSZ | ADUM3150 | SSOP20 | IC4 |  |  |  |  |  | 584-ADUM3150ARSZ
2 | ADUM3401CRWZ | ADUM3401 | SO16W | IC2, IC3 |  |  |  |  |  | 584-ADUM3401CRWZ
1 | CP2102N-QFN24 | CP2102N-QFN24 | QFN24 | IC8 | Single-Chip USB to UART Bridge |  |  |  |  | 634-CP2102NA01GQFN24
1 | ESP-WROOM-03 | ESP-WROOM-03 | ESP-WROOM-03 | U1
1 | EXT SPI | ML10 | ML10 | SV1 | HARTING |  |  |  | unknown |  | unknown
1 | HSPI_CS | SJ | SJ | SJ2 | SMD solder JUMPER
2 | HSPI_DCLK | SJ | SJ | SJ3, SJ4 | SMD solder JUMPER
1 | IRM-02-3.3 | IRM-02-3.3 | MW_IRM-02 | IC5 | MEAN WELL AC/DC Power Modules 2W |  |  |  |  | 709-IRM02-3.3
1 | ISENS_A | AK500/2 | AK500/2 | X6 | CONNECTOR |  |  | EAN: 2050002823952 | unknown |  | unknown
1 | ISENS_B | AK500/2 | AK500/2 | X5 | CONNECTOR |  |  | EAN: 2050002823952 | unknown |  | unknown
1 | ISENS_C | AK500/2 | AK500/2 | X4 | CONNECTOR |  |  | EAN: 2050002823952 | unknown |  | unknown
1 | ISENS_N | AK500/2 | AK500/2 | X7 | CONNECTOR |  |  | EAN: 2050002823952 | unknown |  | unknown
22 | LL4148 | DIODE-SOD80C | SOD80C | D1, D2, D3, D4, D5, D6, D7, D8, D9, D10, D11, D12, D13, D14, D15, D16, D17, D18, D19, D20, D21, D22 | DIODE |  |  |  |  | 512-LL4148
1 | MURATA-PS-MEF1SXXXXSP3C | MURATA-PS-MEF1SXXXXSP3C | SIP-7PIN-1257 | IC6 | Murata Power Solutions, MEF1 Series |  |  |  |  | 580-MEF1S0303SP3C
1 | REF_ON | SJ | SJ | SJ1 | SMD solder JUMPER
2 | S8050 | SMD-TRANSISTORS-NPN-25V-500MW-S8050(SOT-23) | SOT-23 | Q2, Q3 | 305010017 |  | S8050 |  |  | 833-MMSS8050-L-TP |  |  | S8050
1 | SP0503BAHTG | SP0503BAHTG | SOT143-4-R | D23 | SP05 Series - 30pF 30kV Unidirectional TVS Array |  |  |  |  | 576-SP0503BAHTG
22 | TPB1,27 | TPB1,27 | B1,27 | TP7, TP8, TP9, TP10, TP11, TP12, TP13, TP14, TP15, TP16, TP17, TP18, TP19, TP23, TP24, TP28, TP29, TP33, TP34, TP41, TP42, TP43 | Test pad
1 | TPPAD1-13Y | TPPAD1-13Y | P1-13Y | TP44 | Test pad |  |  |  |  |  |  | LED+
1 | TPPAD1-13Y | TPPAD1-13Y | P1-13Y | TP45 | Test pad |  |  |  |  |  |  | LED-
1 | TPPAD1-13Y | TPPAD1-13Y | P1-13Y | TP39 | Test pad |  |  |  |  |  |  | Reset+
1 | TPPAD1-13Y | TPPAD1-13Y | P1-13Y | TP46 | Test pad |  |  |  |  |  |  | Reset-
1 | TPPAD1-13Y | TPPAD1-13Y | P1-13Y | TP38 | Test pad |  |  |  |  |  |  | Taster+
1 | TPPAD1-13Y | TPPAD1-13Y | P1-13Y | TP40 | Test pad |  |  |  |  |  |  | Taster-
1 | ZX62-B-5PA | MICRO-USB-SMD(ZX62-B-5PA) | MICRO-USB5+6P-SMD-0.65-AB | USB1 | 320010005 |  | ZX62-B-5PA |  |  | 649-10118193-0001LF |  |  | ZX62-B-5PA

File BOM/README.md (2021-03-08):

[powermeter]: (https://github.com/voelkerb/powermeter)

# BOM for Sampler Board

| SchematicReference | Qty/Board | Description | OctopartURL |
|---|---|---|---|
| C18 | 1 | 100u | |
| C2,C4-6 | 4 | 10uF | https://octopart.com/grm188r60j106ke47d-murata-18896854 |
| C10,C19 | 2 | 1u | https://octopart.com/grm188r61c105ma12d-murata-51454478 |
| C3,C-9,C11,C13,C14,C17,C28 | 9 | 0.1uF | https://octopart.com/gcm188l81h104ka57d-murata-12613726 |
| C15 | 1 | 22nF | https://octopart.com/grm188r72a223kac4d-murata-196903 |
| C1 | 1 | 1nF | https://octopart.com/grm1885c1h102ja01d-murata-196169 |
| C12 | 1 | 470p | https://octopart.com/grm1885c1h471ja01d-murata-196161 |
| C16 | 1 | 150p | https://octopart.com/grm1885c1h151ja01j-murata-6807839 |
| ERROR,LED2 | 2 | RED | https://octopart.com/ltst-c191krkt-lite-on-549908 |
| LED1 | 1 | green | https://octopart.com/ltst-c191kgkt-lite-on-549907 |
| 32 ESP | 1 | ESP32-WROVER-I | https://octopart.com/esp32-wrover-ib+%288mb%29-espressif+systems-94789167 |
| FB1, FB2 | 2 | Ferrite | https://octopart.com/blm18he152sn1d-murata-12637265 |
| IC1 | 1 | 93LC56B | https://octopart.com/93lc56bt-i%2Fot-microchip-132000 |
| IC2 | 1 | FT232HQ | https://octopart.com/ft232hq-tray-ftdi-20308060 |
| L1 | 1 | which? | https://octopart.com/blm18kg601sn1d-murata-12276433 |
| Q1,Q2 | 2 | S8050 | https://octopart.com/mmss8050-l-tp-mcc-21709877 |
| Q3 | 1 | CSTCR12MHz | https://octopart.com/cstne12m0gh5c000r0-murata-91406922 |
| R19,R39 | 2 | 0 | https://octopart.com/crcw06030000z0ebc-vishay-87883024 |
| R18,R20,R27,R30 | 4 | 10 | https://octopart.com/crcw060310r0fkeac-vishay-12144377 |
| R16,R23,R24,R26 | 4 | 33 | https://octopart.com/crcw060333r0fkeac-vishay-23798409 |
| R34-37 | 4 | 49.9 | https://octopart.com/crcw060349r9fkeac-vishay-20809567 |
| R31-33 | 3 | 332 | https://octopart.com/crcw0603332rfkeac-vishay-22248066 |
| R5,R6 | 2 | 1K | https://octopart.com/crcw06031k00fkeac-vishay-12144082 |
| R7 | 1 | 2.2K | https://octopart.com/crcw06032k20fkeac-vishay-12144428 |
| R8,R12,R15,R22,R25,R38 | 6 | 4.7K | https://octopart.com/crcw06034k70fkeac-vishay-12144098 |
| NC: R9,R11 | 2 | 5k | https://octopart.com/pnm0603e5001bst1-vishay-64731392 |
| R14,R17,R28,R29 | 4 | 10k | https://octopart.com/crcw060310k0fkeac-vishay-12144376 |
| R1-4,R10,R13 | 5 | 12K | https://octopart.com/crcw060312k0fkeac-vishay-12144378 |
| R21 | 1 | 12.1k | https://octopart.com/crcw060312k1fkeac-vishay-22248021 |
| RTC | 1 | DS3231 | https://octopart.com/ds3231s%23t%26r-maxim+integrated-46653426 |
| SG7050 | 1 | OSCILLATORSMD-7X5-4PAD | https://octopart.com/sg7050can+50.000000m-tjga3-epson-56784031 |
| SV1 | 1 | EXTSPI | https://www.reichelt.de/wannenstecker-14-polig-gerade-wsl-14g-p22819.html?&trstct=pos_0 |
| U$2 | 1 | HR911105A | https://www.ebay.de/itm/RJ45-Ethernet-Buchse-Netzwerk-8P8C-mit-Ubertrager-LED-HR911105A-ahnl-MagJack/282258087489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 |
| U1 | 1 | LAN8720A-CP | https://octopart.com/lan8720a-cp-abc-microchip-75448787 |
| X1 | 1 | microUSB | https://octopart.com/kmmx-bsmt35s-b30tr-kycon-25884288 |
| Sum | 76 | |

# BOM for DAQ board
| SchematicReference | Qty/Board | MPN | Description | OctopartURL |
|---|---|---|---|---|
| C1,C22 | 2 | VJ0805Y105KXQTW1BC | 1u | https://octopart.com/vj0805y105kxqtw1bc-vishay-46567275 |
| C2,C4,C6,C48,C50 | 5 | GRM219R61A475KE34D | 4.7u | https://octopart.com/grm219r61a475ke34d-murata-196958 |
| C3,C5,C7,C11-19,C23,C24,C47,C49,C51,C52 | 18 | C0805C104K3RACTU | 0.1u | https://octopart.com/c0805c104k3ractu-kemet-136827 |
| C8,C9 | 2 | 251R15S160JV4E | 16p | https://octopart.com/251r15s160jv4e-johanson-19159877 |
| C10 | 1 | GRM319R6YA106KA12D | 10u | https://octopart.com/grm319r6ya106ka12d-murata-38899069 |
| C20 | 1 | T55A476M6R3C0070 | 47u | https://octopart.com/t55a476m6r3c0070-vishay-70975894 |
| C21 | 1 | T55A685M010C0300 | 6.8u | https://octopart.com/t55a685m010c0300-vishay-71512079 |
| C25-46 | 22 | C2012C0G1H223J125AA | 22n | https://octopart.com/c2012c0g1h223j125aa-tdk-25947692 |
| D1-22 | 22 | LL4148 | DIODE | https://octopart.com/ll4148-on+semiconductor-84329682 |
| D23 | 1 | SP0503BAHTG | SP05Series-30pF30kVUnidirectionalTVSArray | https://octopart.com/sp0503bahtg-littelfuse-347743 |
| F1-1 | 1 | 65600001409 | Fuse | https://octopart.com/65600001409-littelfuse-39645663 |
| F1-2 | 1 | 65900000009 | FuseHolderAccessories | https://octopart.com/65900000009-littelfuse-13025247 |
| FB1-11 | 11 | BLM21BD152SN1D | Ferritperlen | https://octopart.com/blm21bd152sn1d-murata-368348 |
| IC1 | 1 | ADE9000ACPZ | Strom-undLeistungswächter | https://octopart.com/ade9000acpz-analog+devices-76582370 |
| IC2,IC3 | 2 | ADUM3401CRWZ | Digitalinsulators | https://octopart.com/adum3401crwz-analog+devices-446287 |
| IC4 | 1 | ADUM3150ARSZ | Digitalinsulator | https://octopart.com/adum3150arsz-analog+devices-47285109 |
| IC5 | 1 | IRM-02-3.3 | MEANWELLAC/DCPowerModules2W | https://octopart.com/irm-02-3.3-mean+well-74649647 |
| IC6 | 1 | MEF1S0303SP3C | MurataPowerSolutions,MEF1Series | https://octopart.com/mef1s0303sp3c-murata+power+solutions-49448057 |
| IC7 | 1 | ADR3412ARJZ-R7 | | https://octopart.com/adr3412arjz-r7-analog+devices-18669028 |
| IC8 | 1 | CP2102N-A01-GQFN24 | Single-ChipUSBtoUARTBridge | https://octopart.com/cp2102n-a01-gqfn24-silicon+labs-74636023 |
| L1 | 1 | CBC2518T331M | 303010149 | https://octopart.com/cbc2518t331m-taiyo+yuden-389526 |
| Q1 | 1 | ABLS2-24.576MHZ-D4YF-T | CRYSTAL | https://octopart.com/abls2-24.576mhz-d4yf-t-abracon-9563651 |
| Q2,Q3 | 2 | MMSS8050-L-TP | Bipolartransistors | https://octopart.com/mmss8050-l-tp-mcc-21709877 |
| R1-6,R61 | 7 | RC0805FR-0710KL | 10k | https://octopart.com/rc0805fr-0710kl-yageo-40301103 |
| R7-9 | 3 | WS5M3301J | 3k3(large) | https://octopart.com/ws5m3301j-bourns-56800888 |
| R10-12 | 3 | PTCCL10H010SBE | ptc | https://octopart.com/ptccl10h010sbe-vishay-41962949 |
| R13-21 | 9 | TNPV1206330KBEEN | 330k | https://octopart.com/tnpv1206330kbeen-vishay-58041926 |
| R22-27,R34-36,R37-39,R42,R43 | 14 | ERA8ARB102V | 1k | https://octopart.com/era-8arb102v-panasonic-55639537 |
| R28-33,R40,R41 | 8 | RP73D2B7R87BTG | 7,87 | https://octopart.com/rp73d2b7r87btg-te+connectivity-21411969 |
| R44-53,R56,R58,R62 | 13 | RC0805FR-07470RL | 470 | https://octopart.com/rc0805fr-07470rl-yageo-40315650 |
| R54,R55,R57,R59 | 4 | CR0805-JW-123ELF | 12k | https://octopart.com/cr0805-jw-123elf-bourns-6075154 |
| R60 | 1 | CRCW08051K00FKEA | 1k | https://octopart.com/crcw08051k00fkea-vishay-39435920 |
| RV1 | 1 | B72210S0321K101 | VARISTORTDKStandarDseriesB722 | https://octopart.com/b72220s301k101-epcos-55400425 |
| RV2-4 | 3 | EPCOS B72220S301K101 | EPCOS B72220S301K101 | https://octopart.com/b72220s301k101-epcos-55400425#PriceAndStock |
| U1 | 1 | ESP-WROOM-32 | ESP | https://octopart.com/esp-wroom-32-olimex-77083894 |
| | 1 | | 14PinHeader | |
| USB1 | 1 | 10118193-0001LF | USBport | https://octopart.com/10118193-0001lf-fci-21265435 |
| Screw terminals 3er | 3 | MKDS 1,5/3 | Conrad ArtNr.: 000743384 | |
| Screw terminals 2er | 4 | MKDS 1,5/2 | Conrad ArtNr.: 000743370 | |
| Sum | 169 | | | |

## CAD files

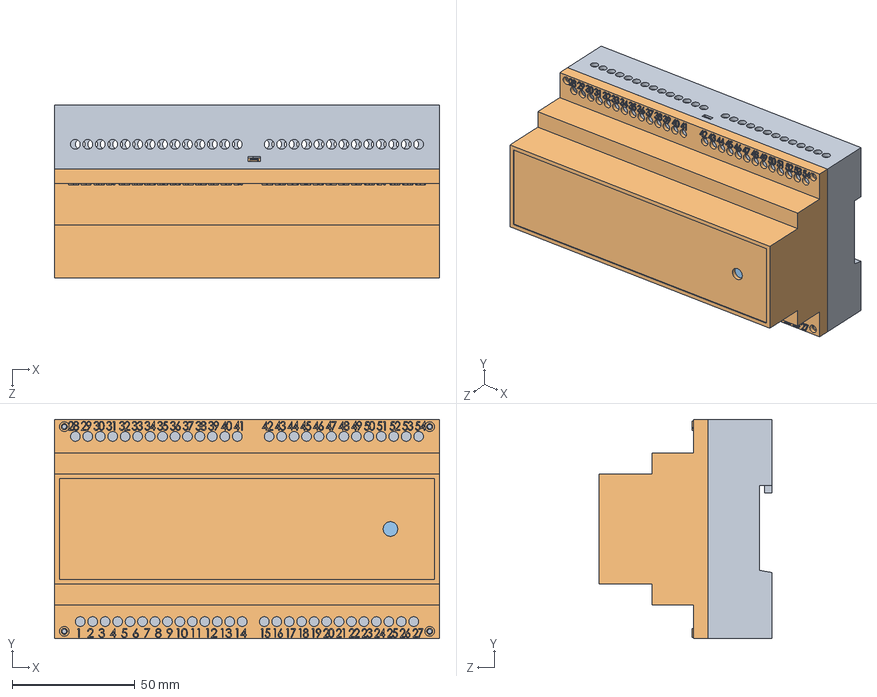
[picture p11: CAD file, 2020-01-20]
Housing/housing/SmartMeter.SLDASM
157.0 x 89.5 x 70.5 mm
lower
upper
MiddleDinPlate
sampleboard

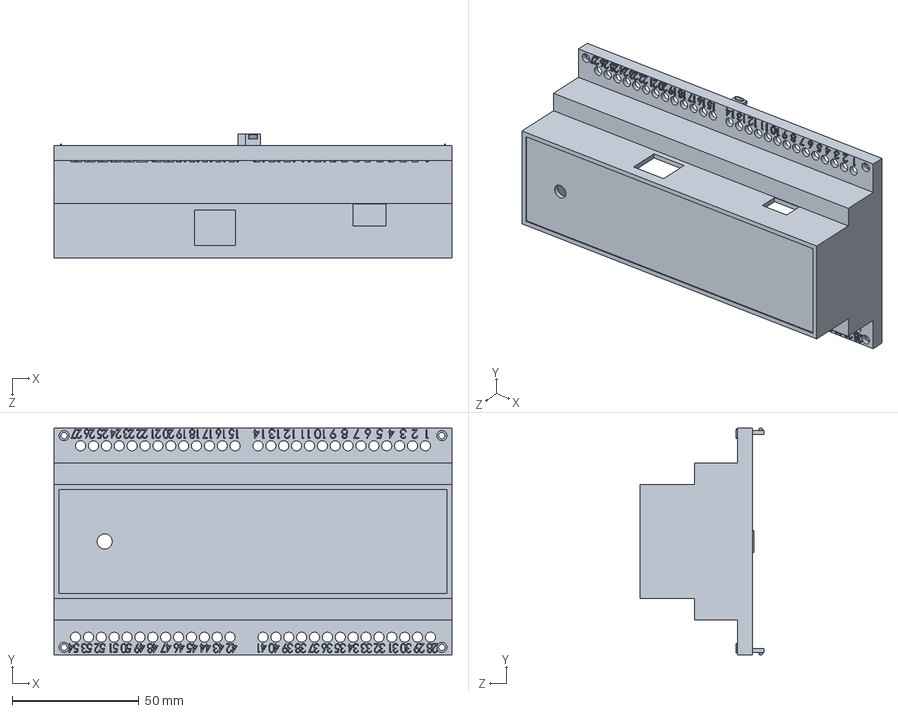
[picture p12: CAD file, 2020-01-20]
Housing/housing/DinHousing_upper.SLDPRT
157.0 x 89.5 x 49.0 mm

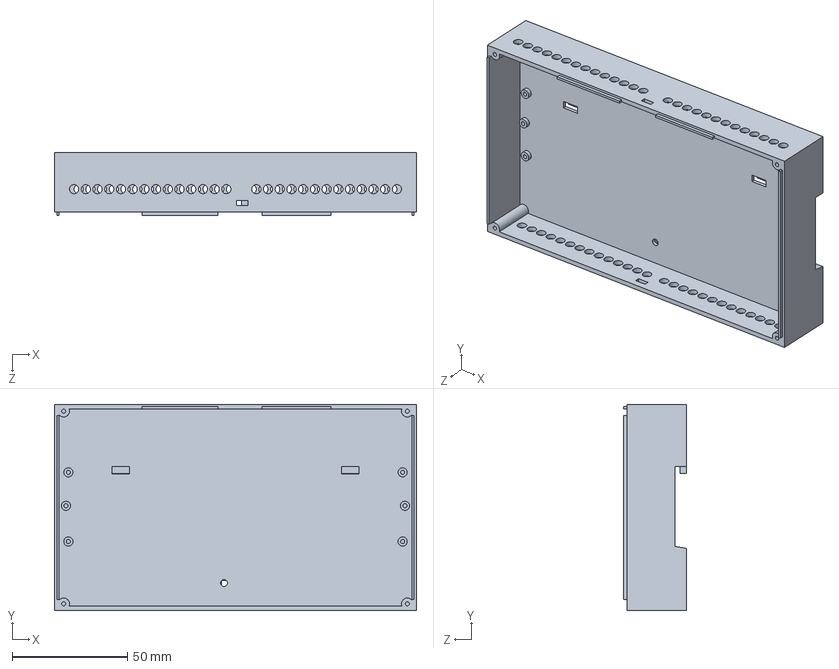
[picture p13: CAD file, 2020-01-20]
Housing/housing/DinHousing_lower.SLDPRT
157.0 x 89.5 x 27.5 mm

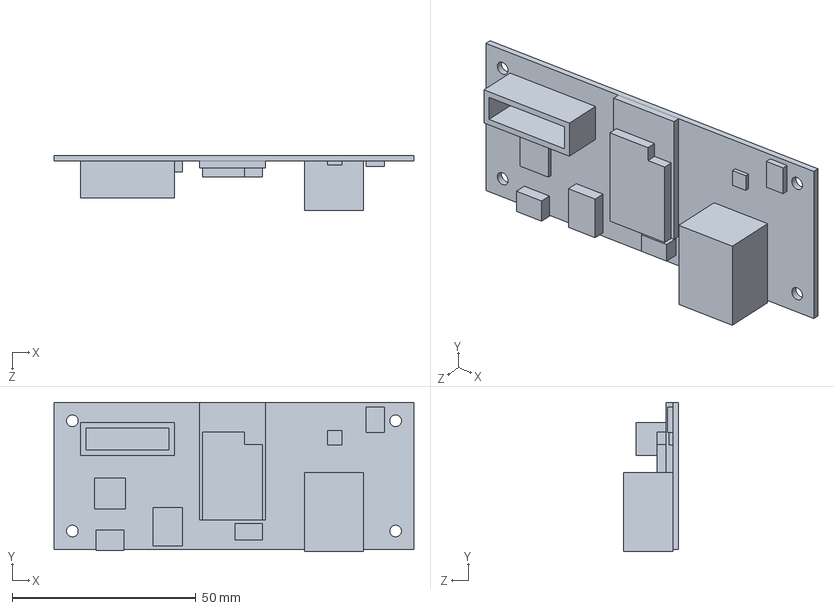
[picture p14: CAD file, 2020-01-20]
Housing/housing/Sampleboard.SLDPRT
98.0 x 40.6 x 15.1 mm

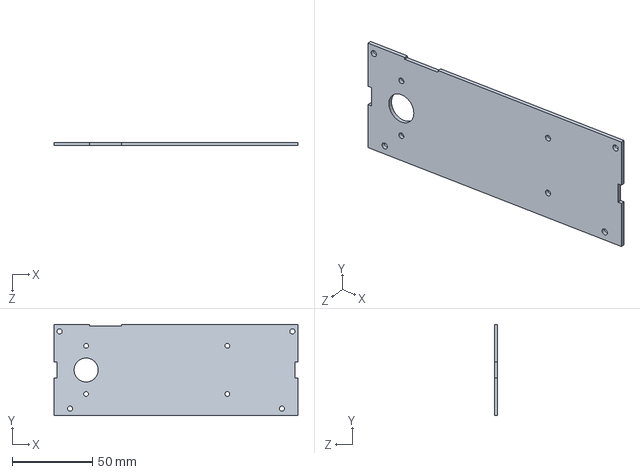
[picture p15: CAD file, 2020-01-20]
Housing/housing/Separator.SLDPRT
152.0 x 57.0 x 2.00 mm

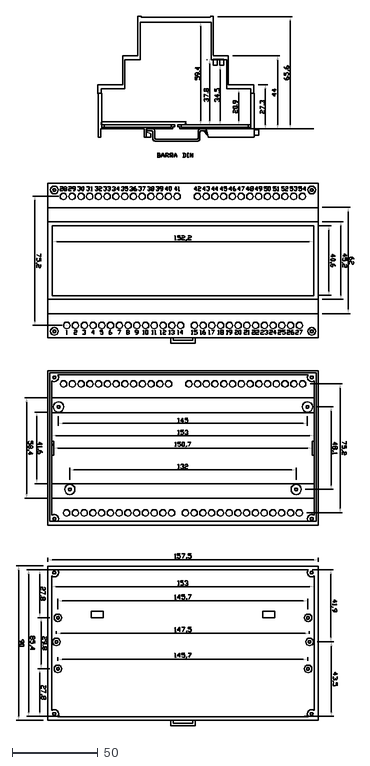
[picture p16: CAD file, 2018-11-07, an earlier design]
Housing/housing/old/MR9_C.dxf
196.5 x 413.3

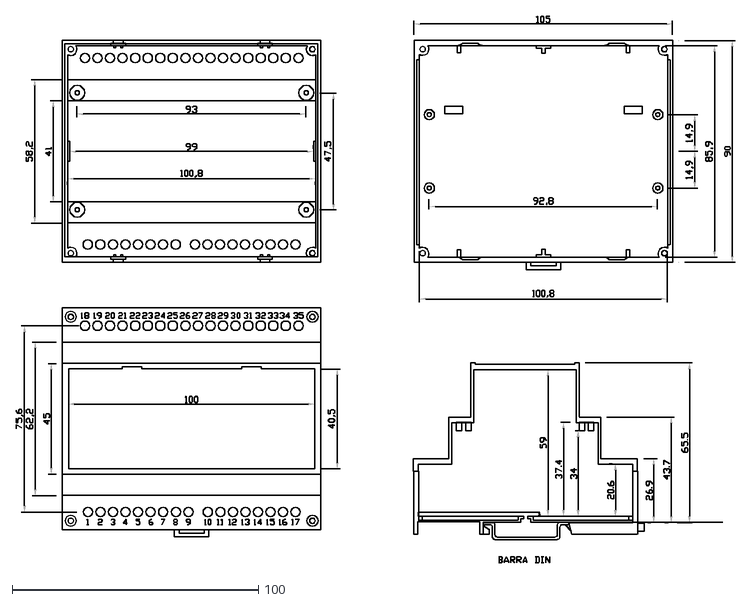
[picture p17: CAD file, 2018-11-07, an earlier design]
Housing/housing/old/MR6_C.dxf
291.9 x 221.8

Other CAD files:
Housing/housing/old/MR9_C_DXF-R12.dxf
Housing/housing/old/MR6_C_DXF-R12.dxf

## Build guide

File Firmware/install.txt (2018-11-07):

Arduino makefile folder is from:
https://github.com/thunderace/Esp8266-Arduino-Makefile

% ------ UNIX install instructions: ---------- %

- Install CPAN and YAML for perl:
sudo perl -MCPAN -e shell
o conf init
sudo perl -MCPAN -e 'install Bundle::CPAN'
sudo cpan YAML

- Install Python2 and pyserial for Python2
brew install python@2
pip install pyserial

% ----- Windows install instructions: -------- %
TODO

% ----- Usage -------------------------------- %
Go into folder ESP32_NILM and call ...
- make           to build program file
- make upload    to build and upload file
- make clean     to remove all binaries
- make reset     to reset the ESP

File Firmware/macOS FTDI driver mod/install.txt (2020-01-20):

Disable csrutil
- restart into recovery mode: cmd + r while booting
- open terminal
-- crsutil disable
- restart

Mount system directory as read write
- sudo mount -uw

Copy kext to Extension folder
- sudo cp -R <source/FTDIUSBSerialDriver.kext> /System/Library/Extensions/FTDIUSBSerialDriver.kext/

Load modified kernel extension
- sudo kextload /System/Library/Extensions/FTDIUSBSerialDriver.kext/

Remember that you have different baud rate mappings now:
300  ->  4M
600  ->  8M
1200 -> 12M

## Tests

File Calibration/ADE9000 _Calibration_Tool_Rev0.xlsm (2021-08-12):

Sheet: Configuration Guide
Set PGA gain (xGAIN) Register | Default Gain =1
Set SELFREQ to 50 or 60Hz in ACCMODE register | Default =0 i.e. 50Hz
Set VLEVEL for fundamental reactive power
If using integrator, enable integrator in CONFIG0 register. Set DICOEFF to 0xFFFFE000 if integrator is enabled | Integrator is disabled by default. DICOEFF=0 by default
Change High pass filter(HPF_CRN) in CONFIG2 register frequency if required | Default corner frequency is 0.625Hz (HPF_CRN=6)
Enter input parameters in Step 1 and Step 2
Set CFDEN, Configure CFMODE and COMPMODE. Set xTHR = 0x100000 | Default xTHR=0
Perform Voltage and Current gain calibration(Step 3) if Accurate RMS readings are desired.Program xIRMS and xVRMS register
Perform Voltage and Current offset calibration(Step 3) if Accurate RMS readings are desired at low dynamic range.Program xIRMSOS and xVRMSOS register
Perform phase calibration at the nominal inputs and lagging angle of 60degrees. Program xPHCAL register
Perform gain calibration at the nominal inputs 0 or 60 degrees phase. Program xPGAIN register
Perform gain offset calibration at the nominal voltage and low current at 0degrees phase. Program xWATTOS , xVAROS and xFVAROS register

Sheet: Calibration_Tool
Step 1: Input Conditions |  | Inputs
 |  | Outputs
Select Channel Being Calibrated | Channel A
Enter Line Frequency(Hz) | 50.0
Select Current Sensor | Current Transformer
Select Voltage Sensor | Resistor divider
Enter Nominal RMS Input Voltage(Vrms) | 230
Enter Nominal RMS Input Current(Arms) | 1
Enter Meter Constant(impulses/kWHr) | 1
Enter Energy Accumulation Time(sec) | 1
Enter Voltage PGA_GAIN | 2
Enter Current PGA_GAIN | 4
Step 2: Seting up CF pulses
Enter CT Turns ratio | 2000
Enter Total CT Burden Resistor(Ohm) | 15.74
Current Transfer Function(V/A) | 0.00787
Enter Top Leg (R1) of Divider Resistor (KOhm) | 994.7
Enter Bottom Leg (R2)of Divider Resistor (kOhm) | 1
Voltage Transfer Function(V/V) | 0.00100431857
Expected CF at Nominal Conditions(Hz) | 6.388888889e-05
Program xTHR to Recommended Value( xTHR=0x00100000) | 100000 | Write this value to xTHR registers
Nominal Voltage percentage of full scale | 65.33%
Nominal Current percentage of full scale | 4.45%
CFxDEN Register(hex) | 448CB04 | Write this value to CFxDEN register
Voltage Conversion Constant(uVrms/Code) | 6.679680021
Current Conversion Constant(uArms/Code) | 0.4262088111
Power Conversion Constant(mWatt/Code) | 0.3821096117
Energy Conversion Constant ( uWxHr/xxTTHR_HI Code) | 0.1086889562
Step 3:Voltage and Current Gain Calibration
Select Calibration technique | Calibrate using Register values
Enter Measured xIRMS register value(hex)
Enter Measured xVRMS register value(hex)
Expected xIRMS register value(hex) | 23CD1C
Expected xVRMS register value(hex) | 20D6713
AIGAIN Register(hex) | #DIV/0! | Write this value to xIGAIN register
AVGAIN Register(hex) | #DIV/0! | Write this value to xVGAIN register
Enter Measured xIRMS register value after calibration(hex)
Enter Measured xVRMS register value after calibration(hex)
Current Error after Compensation | -100.00%
Voltage Error after Compensation | -100.00%
Step 3.1: RMS offset calibration
Enter Offset Calibration Current(Arms) |  | Use a Non-Zero Current
Enter Offset Calibration Voltage(Vrms) |  | Use a Non-Zero Voltage
Enter Measured xIRMS register value(hex)
Enter Measured xVRMS register value(hex)
Enter Measured xIFRMS register value(hex)
Enter Measured xVFRMS register value(hex)
AIRMSOS Register(hex) | 0
AVRMSOS Register(hex) | 0
AIFRMSOS Register(hex) | 0
AVFRMSOS Register(hex) | 0
Step 4: Phase calibration | Done at Lagging PF=0.5 such that Active and Reactive Energies are Positive
Select Calibration technique | Calibrate using Register values
Enter Calibrating Angle between V and I(°)(positive angle for lagging PF) | 60
Expected Active Energy Register(xWATTHR_HI hex) at calibrating angle | 47C12
Expected Reactive Energy(xVARHR_HI hex) at calibrating angle | 7C485
Enter measured Active Energy register xWATTHR_HI (hex) at calibrating angle
Enter measured Reactive Energy register xVARHR_HI (hex) at calibrating angle
Desired Phase Error Compensation(°) | #DIV/0!
APHCAL0 Register(hex) | #DIV/0! | Write this value to xPHCAL register
Step 5: Power Gain Calibration | Done at PF=1 or lagging PF = 0.5
Select Calibration technique | Calibrate using Register values
Enter Angle between V and I(°) | 0
Enter measured Active Energy register xWATTHR_HI (hex)
Enter measured Rective Energy register xVARHR_HI (hex)(Optional)
Expected Active Energy register xWATTHR_HI (hex) | 8F825
Expected Rective Energy register xVARHR_HI (hex) | 0
APGAIN Register(hex) | #DIV/0! | Write this value to xPGAIN register
Enter measured Active Energy register xWATTHRHI (hex) after xPGAIN Calibration
Active Energy Error after xPGAIN Calibration | -100.00%
Step 5.1: Power offset calibration | PF=1/0 for active/reactive respectively. Nominal voltage
Select Calibration technique | Calibrate using Register values
Enter Accumulation Time for Offset calibration(sec)
Enter Calibration Current(Arms)
Enter measured Active Energy register xWATTHR_HI (hex)
Enter measured Reactive Energy register xVARHR_HI (hex)
Enter measured Fundamental Active Energy register xFWATTHR_HI (hex)
Enter measured Fundamental Reactive Energy register xFVARHR_HI (hex)
AWATTOS Register(hex) | #DIV/0!
AVAROS Register(hex) | #DIV/0!
AFWATTOS Register(hex) | #DIV/0!
AFVAROS Register(hex) | #DIV/0!
Summary Table
Register Name |  | Address(Hex)
CF1DEN | 448CB04 | 0x494
CF2DEN | 448CB04 | 0x495
CF3DEN | 448CB04 | 0x496
CF4DEN | 448CB04 | 0x497
AIGAIN | #DIV/0! | 0x000
AVGAIN | #DIV/0! | 0x00B
APHCAL | #DIV/0! | 0x006
APGAIN | #DIV/0! | 0x00E
AIRMSOS | 0 | 0x00C
AVRMSOS | 0 | 0x00D
AWATTOS | #DIV/0! | 0x00F
AVAROS | #DIV/0! | 0x010
AIFRMSOS | 0 | 0x013
AVFRMSOS | 0 | 0x014
AFWATTOS | #DIV/0! | 0x011
AFVAROS | #DIV/0! | 0x012
BIGAIN |  | 0x020
BVGAIN |  | 0x02B
BPHCAL |  | 0x026
BPGAIN |  | 0x02E
BIRMSOS |  | 0x02C
BVRMSOS |  | 0x2D
BWATTOS |  | 0x2F
BVAROS |  | 0x030
BIFRMSOS |  | 0x033
BVFRMSOS |  | 0x034
BFWATTOS |  | 0x031
BFVAROS |  | 0x032
CIGAIN |  | 0x040
CVGAIN |  | 0x04B
CPHCAL |  | 0x046
CPGAIN |  | 0x04E
CIRMSOS |  | 0x04C
CVRMSOS |  | 0x04D
CWATTOS |  | 0x04F
CVAROS |  | 0x050
CIFRMSOS |  | 0x053
CVFRMSOS |  | 0x054
CFWATTOS |  | 0x051
CFVAROS |  | 0x052
NIGAIN |  | 0x06D
NPHCAL |  | 0x06E
NIRMSOS |  | 0x06B

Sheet: Constants and config
**Donot Modify sheet**
Input configuration | Current Sensor | Voltage Sensor | Fline | PGA_GAIN | Channel | Calibration method | RMS Calibration Methods | Phase calibration methods | Energy Calibration Methods
Single ended | Current Transformer | Resistor divider | 50 | 1 | Channel A | Calibrate using CF | Calibrate using Register values | Calibrate using CF | Calibrate using CF
Differential | Rogowski | Voltage Transformer | 60 | 2 | Channel B | Calibrate using Registers | Calibrate using meter Voltage&Current output values | Calibrate using Register values | Calibrate using Register values
 | Other | Other |  | 4 | Channel C | Calibrate using Error |  | Calibrate using Energy Error | Calibrate using Energy Error
 |  |  |  |  | Neutral |  |  | Calibrate using Impulses/kWHr | Calibrate using Impulses/kWHr
Full Scale Values
RMS | 52702092
WATT | 20694066
Fline | 50.0
fDSP | 8000
Omega(rad) | #VALUE!
channel A

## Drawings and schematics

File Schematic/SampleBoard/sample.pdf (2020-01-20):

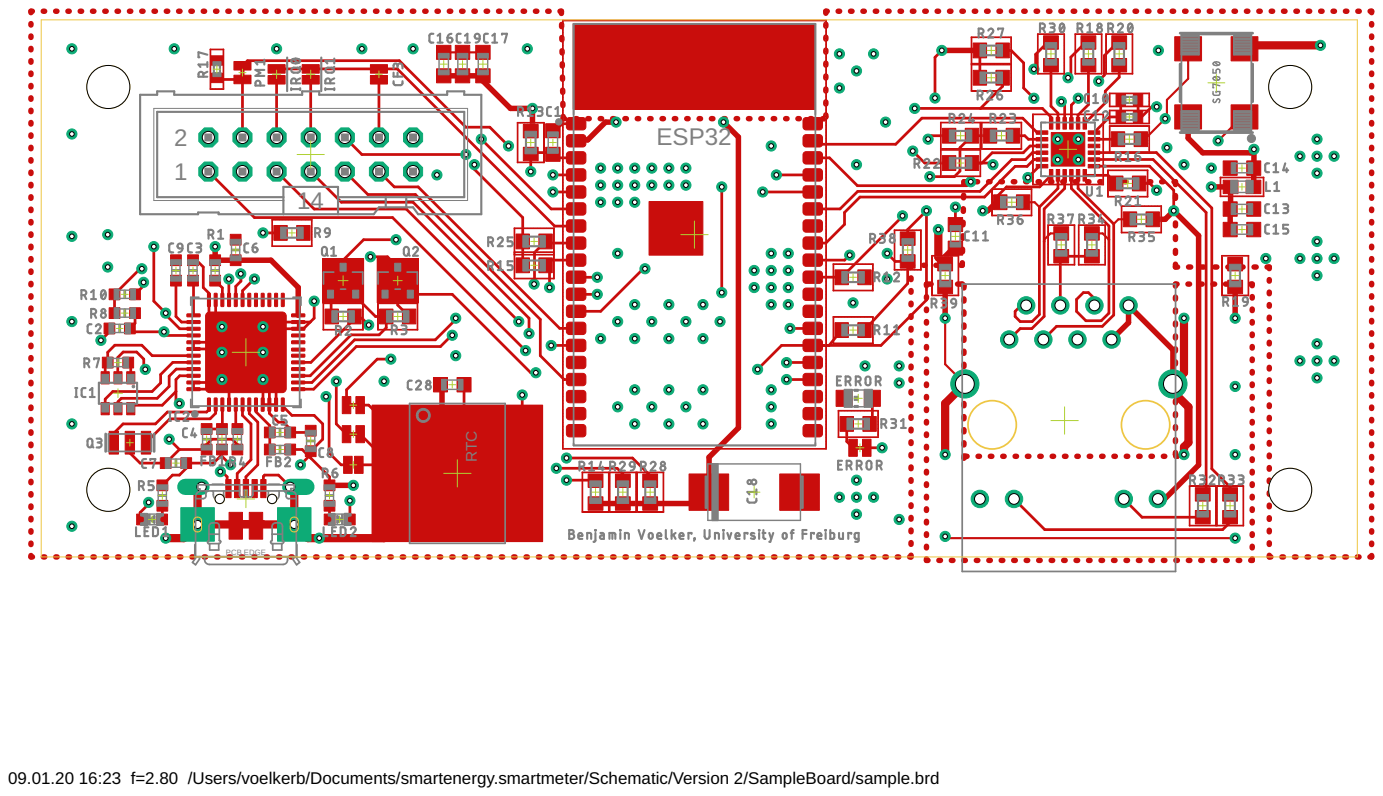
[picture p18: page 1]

09.01.20 16:23 f=2.80 /Users/voelkerb/Documents/smartenergy.smartmeter/Schematic/Version 2/SampleBoard/sample.brd

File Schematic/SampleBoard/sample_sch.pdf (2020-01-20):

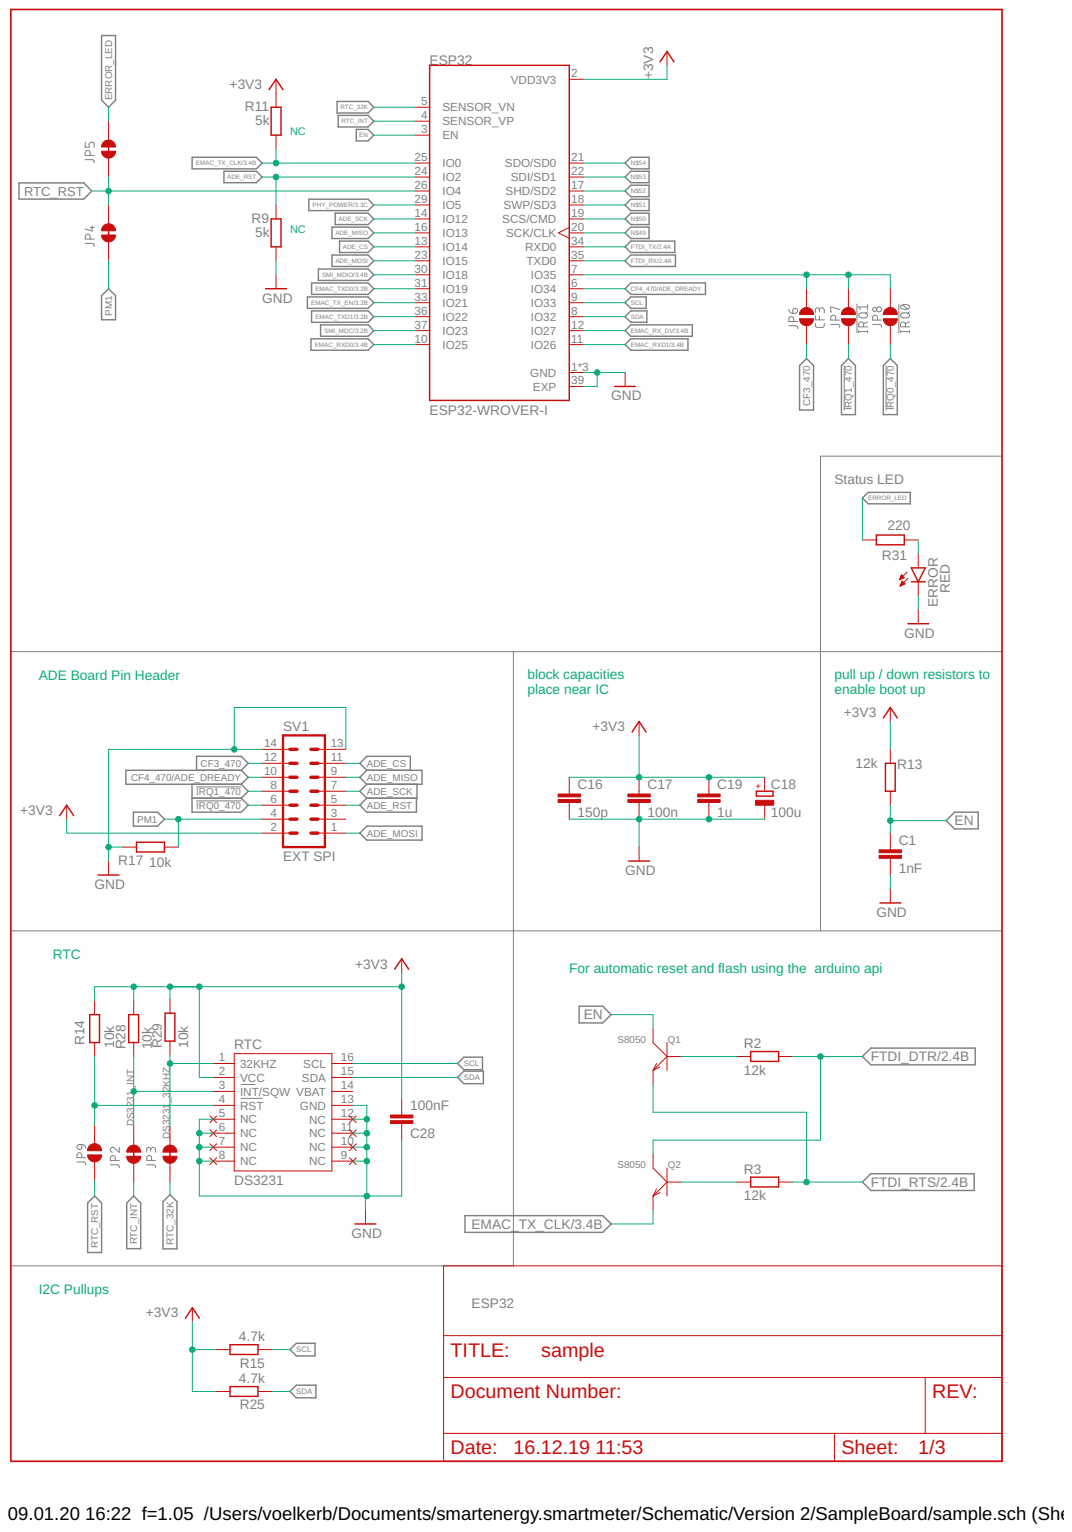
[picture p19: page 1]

ADE Board Pin Header

block capacities place near IC

+ pull up / down resistors to

For automatic reset and flash using the arduino api

Document Number: | REV:

Date: 16.12.19 11:53 | Sheet: 1/3

09.01.20 16:22 f=1.05 /Users/voelkerb/Documents/smartenergy.smartmeter/Schematic/Version 2/SampleBoard/sample.sch (Sheet: 1/3)

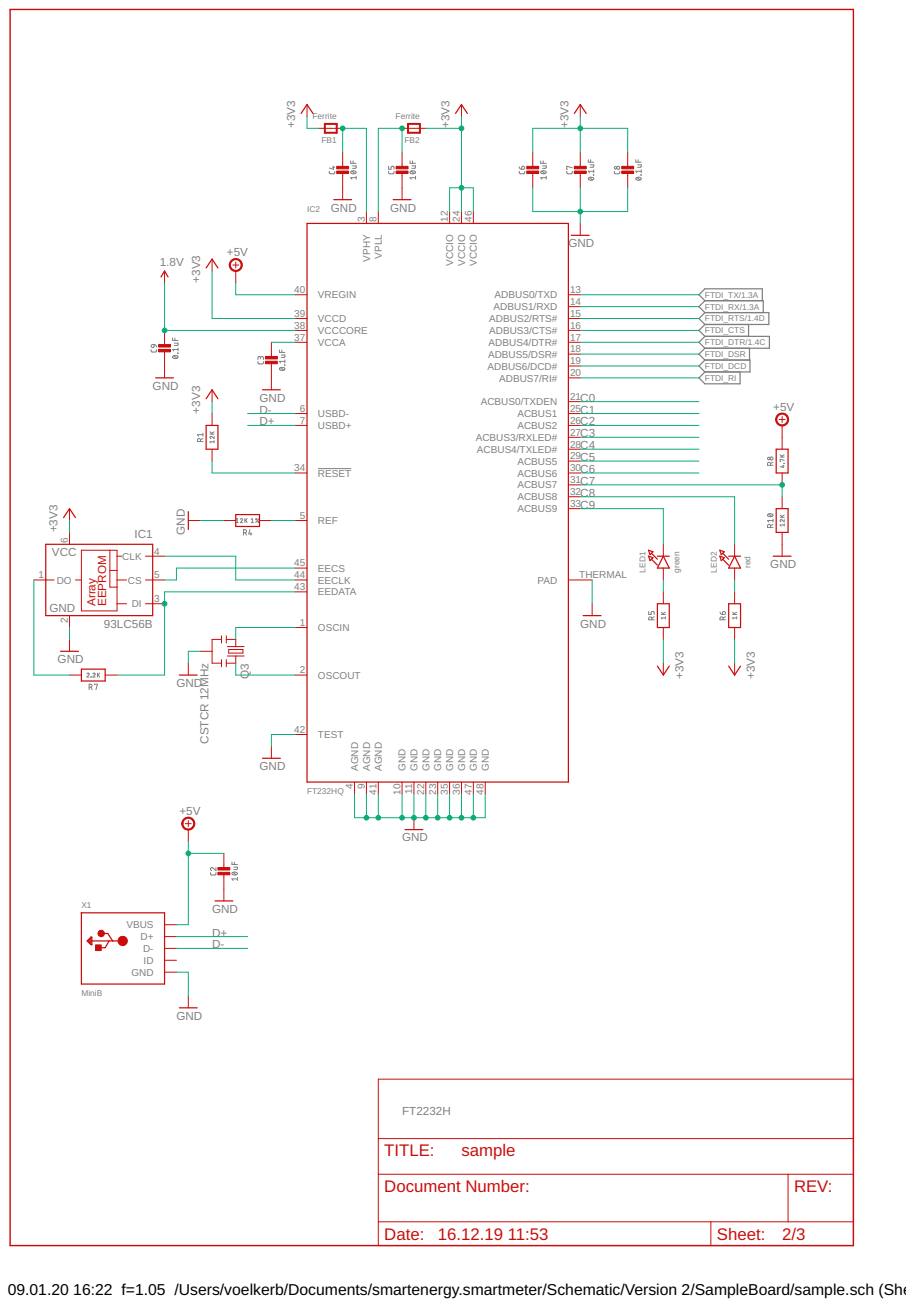
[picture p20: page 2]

09.01.20 16:22 f=1.05 /Users/voelkerb/Documents/smartenergy.smartmeter/Schematic/Version 2/SampleBoard/sample.sch (Sheet: 2/3)

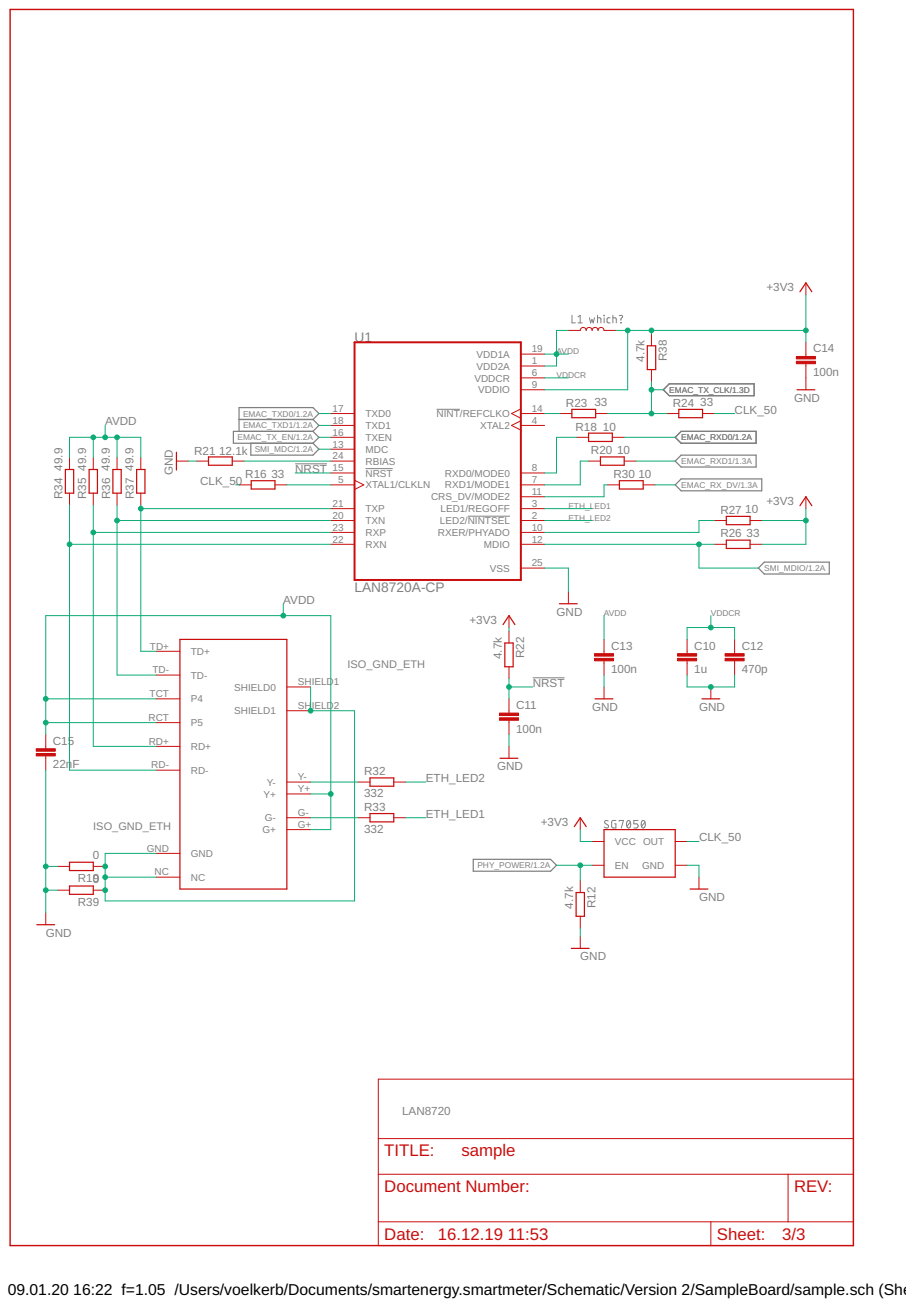
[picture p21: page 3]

09.01.20 16:22 f=1.05 /Users/voelkerb/Documents/smartenergy.smartmeter/Schematic/Version 2/SampleBoard/sample.sch (Sheet: 3/3)

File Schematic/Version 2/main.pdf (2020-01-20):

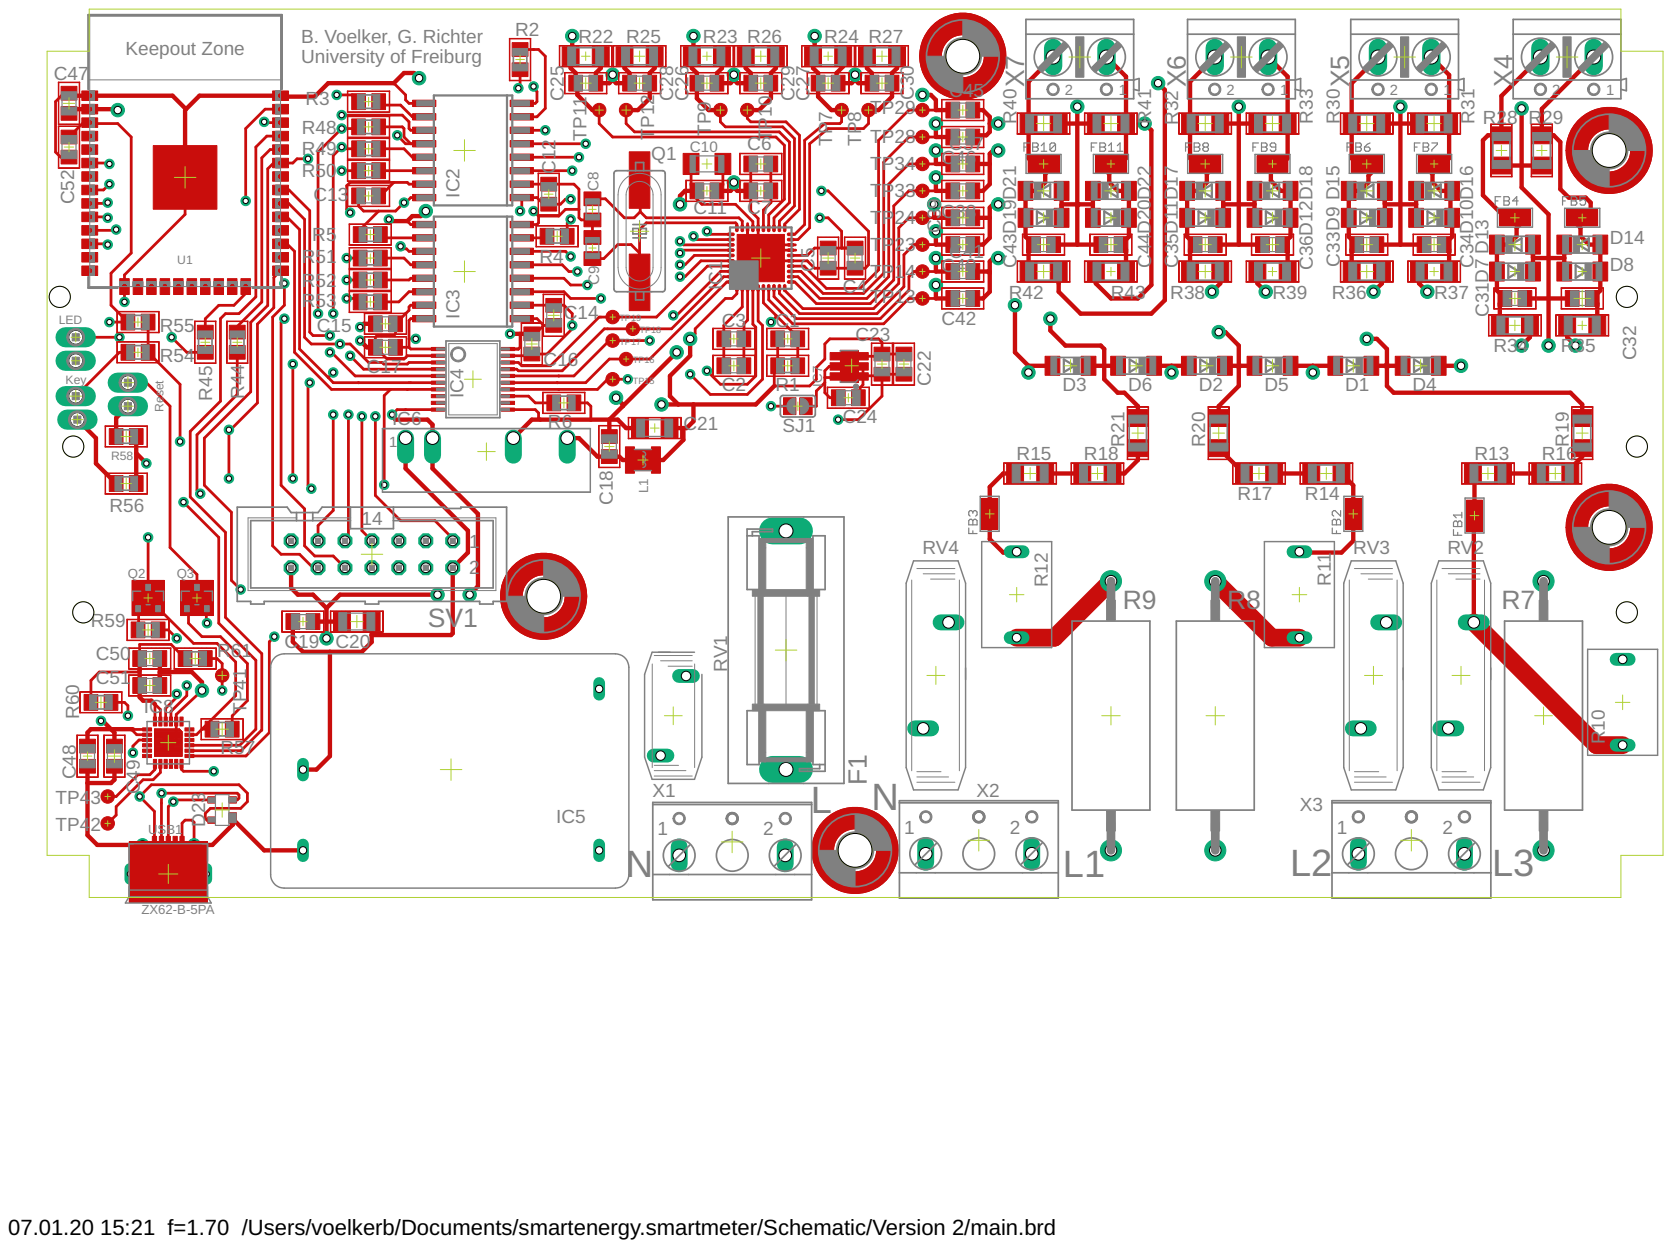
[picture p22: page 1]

07.01.20 15:21 f=1.70 /Users/voelkerb/Documents/smartenergy.smartmeter/Schematic/Version 2/main.brd

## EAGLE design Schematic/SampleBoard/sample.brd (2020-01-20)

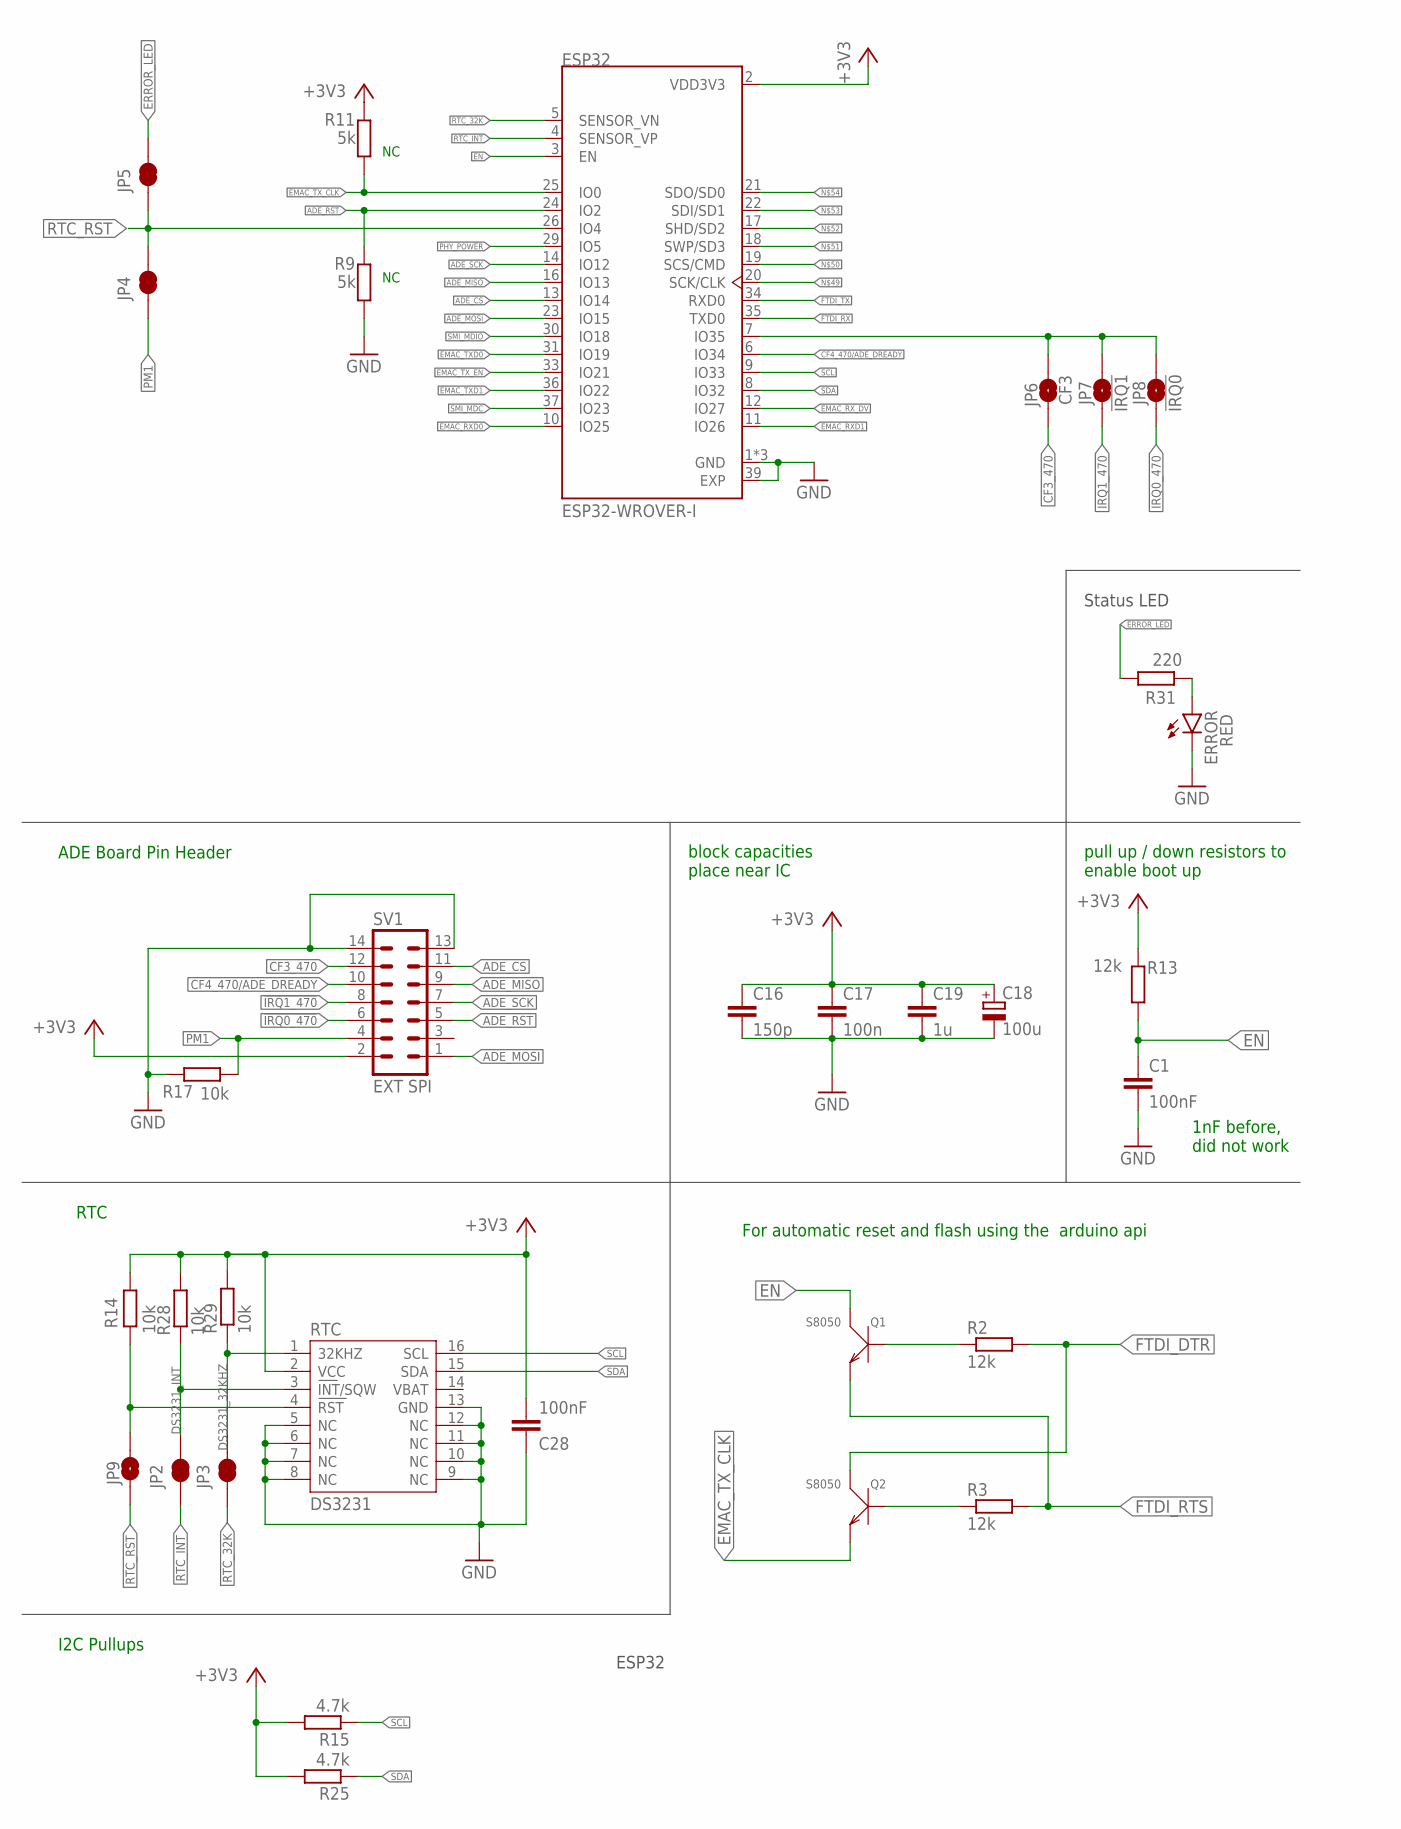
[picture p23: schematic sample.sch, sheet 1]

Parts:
C1, C28: 100nF; C0603K
C16: 150p; C0603K
C17: 100n; C0603K
C18: 100u; D/7343-31W
C19: 1u; C0603K
ERROR: RED; CHIP-LED0805
ESP32: ESP32-WROVER-I; XCVR_ESP32-WROVER-I
JP2: INT; SMT-JUMPER_2_NC_TRACE_NO-SILK
JP3: 32K; SMT-JUMPER_2_NC_TRACE_NO-SILK
JP4: PM1; SMT-JUMPER_2_NC_TRACE_NO-SILK
JP5: ERROR; SMT-JUMPER_2_NC_TRACE_NO-SILK
JP6: CF3; SMT-JUMPER_2_NO_NO-SILK
JP7: !IRQ1; SMT-JUMPER_2_NO_NO-SILK
JP8: !IRQ0; SMT-JUMPER_2_NO_NO-SILK
JP9: RST; SMT-JUMPER_2_NO_NO-SILK
Q1, Q2: S8050; SOT-23
R2, R3, R13: 12k; R0603
R9, R11: 5k; R0603
R14, R28, R29: 10k; R0603
R15, R25: 4.7k; R0603
R17: 10k; R0402
R31: 220; R0603
RTC: DS3231
SV1: EXT SPI; ML14

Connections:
!IRQ0_470: JP8.2, SV1.6
!IRQ1_470: JP7.2, SV1.8
+3V3: C16.1, C17.1, C18.+, C19.1, C28.2, ESP32.2 (VDD3V3), R11.1, R13.1, R14.1, R15.2, R25.2, R28.2, R29.2, RTC.2 (VCC), SV1.2; also elsewhere on the board
ADE_CS: ESP32.13 (IO14), SV1.11
ADE_MISO: ESP32.16 (IO13), SV1.9
ADE_MOSI: ESP32.23 (IO15), SV1.1
ADE_RST: ESP32.24 (IO2), R9.2, SV1.5
ADE_SCK: ESP32.14 (IO12), SV1.7
CF3_470: JP6.1, SV1.12
CF4_470/ADE_DREADY: ESP32.6 (IO34), SV1.10
DS3231_32KHZ: JP3.2, R29.1, RTC.1 (32KHZ)
DS3231_INT: JP2.2, R28.1, RTC.3 (INT/SQW)
DS3231_RST: JP9.2, R14.2, RTC.4 (RST)
EMAC_RXD0: ESP32.10 (IO25); also elsewhere on the board
EMAC_RXD1: ESP32.11 (IO26); also elsewhere on the board
EMAC_RX_DV: ESP32.12 (IO27); also elsewhere on the board
EMAC_TXD0: ESP32.31 (IO19); also elsewhere on the board
EMAC_TXD1: ESP32.36 (IO22); also elsewhere on the board
EMAC_TX_CLK: ESP32.25 (IO0), Q2.2 (E), R11.2; also elsewhere on the board
EMAC_TX_EN: ESP32.33 (IO21); also elsewhere on the board
EN: C1.1, ESP32.3 (EN), Q1.3 (C), R13.2
ERROR_LED: JP5.2, R31.1
FTDI_DTR: Q2.3 (C), R2.2; also elsewhere on the board
FTDI_RTS: Q1.2 (E), R3.2; also elsewhere on the board
FTDI_RX: ESP32.35 (TXD0); also elsewhere on the board
FTDI_TX: ESP32.34 (RXD0); also elsewhere on the board
GND: C1.2, C16.2, C17.2, C18.-, C19.2, C28.1, ERROR.C, ESP32.1 (GND), ESP32.15 (GND), ESP32.38 (GND), ESP32.39 (EXP), R9.1, R17.2, RTC.5 (NC), RTC.6 (NC), RTC.7 (NC), RTC.8 (NC), RTC.9 (NC), RTC.10 (NC), RTC.11 (NC), RTC.12 (NC), RTC.13 (GND), SV1.13, SV1.14; also elsewhere on the board
unnamed: Q1.1 (B), R2.1
unnamed: Q2.1 (B), R3.1
unnamed: ERROR.A, R31.2
unnamed: ESP32.7 (IO35), JP6.2, JP7.1, JP8.1
PHY_POWER: ESP32.29 (IO5); also elsewhere on the board
PM1: JP4.1, R17.1, SV1.4
RTC_32K: ESP32.5 (SENSOR_VN), JP3.1
RTC_INT: ESP32.4 (SENSOR_VP), JP2.1
RTC_RST: ESP32.26 (IO4), JP4.2, JP5.1, JP9.1
SCL: ESP32.9 (IO33), R15.1, RTC.16 (SCL)
SDA: ESP32.8 (IO32), R25.1, RTC.15 (SDA)
SMI_MDC: ESP32.37 (IO23); also elsewhere on the board
SMI_MDIO: ESP32.30 (IO18); also elsewhere on the board

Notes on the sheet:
pull up / down resistors to enable boot up
For automatic reset and flash using the arduino api
ESP32
block capacities place near IC
RTC
I2C Pullups
Status LED
ADE Board Pin Header
1nF before, did not work

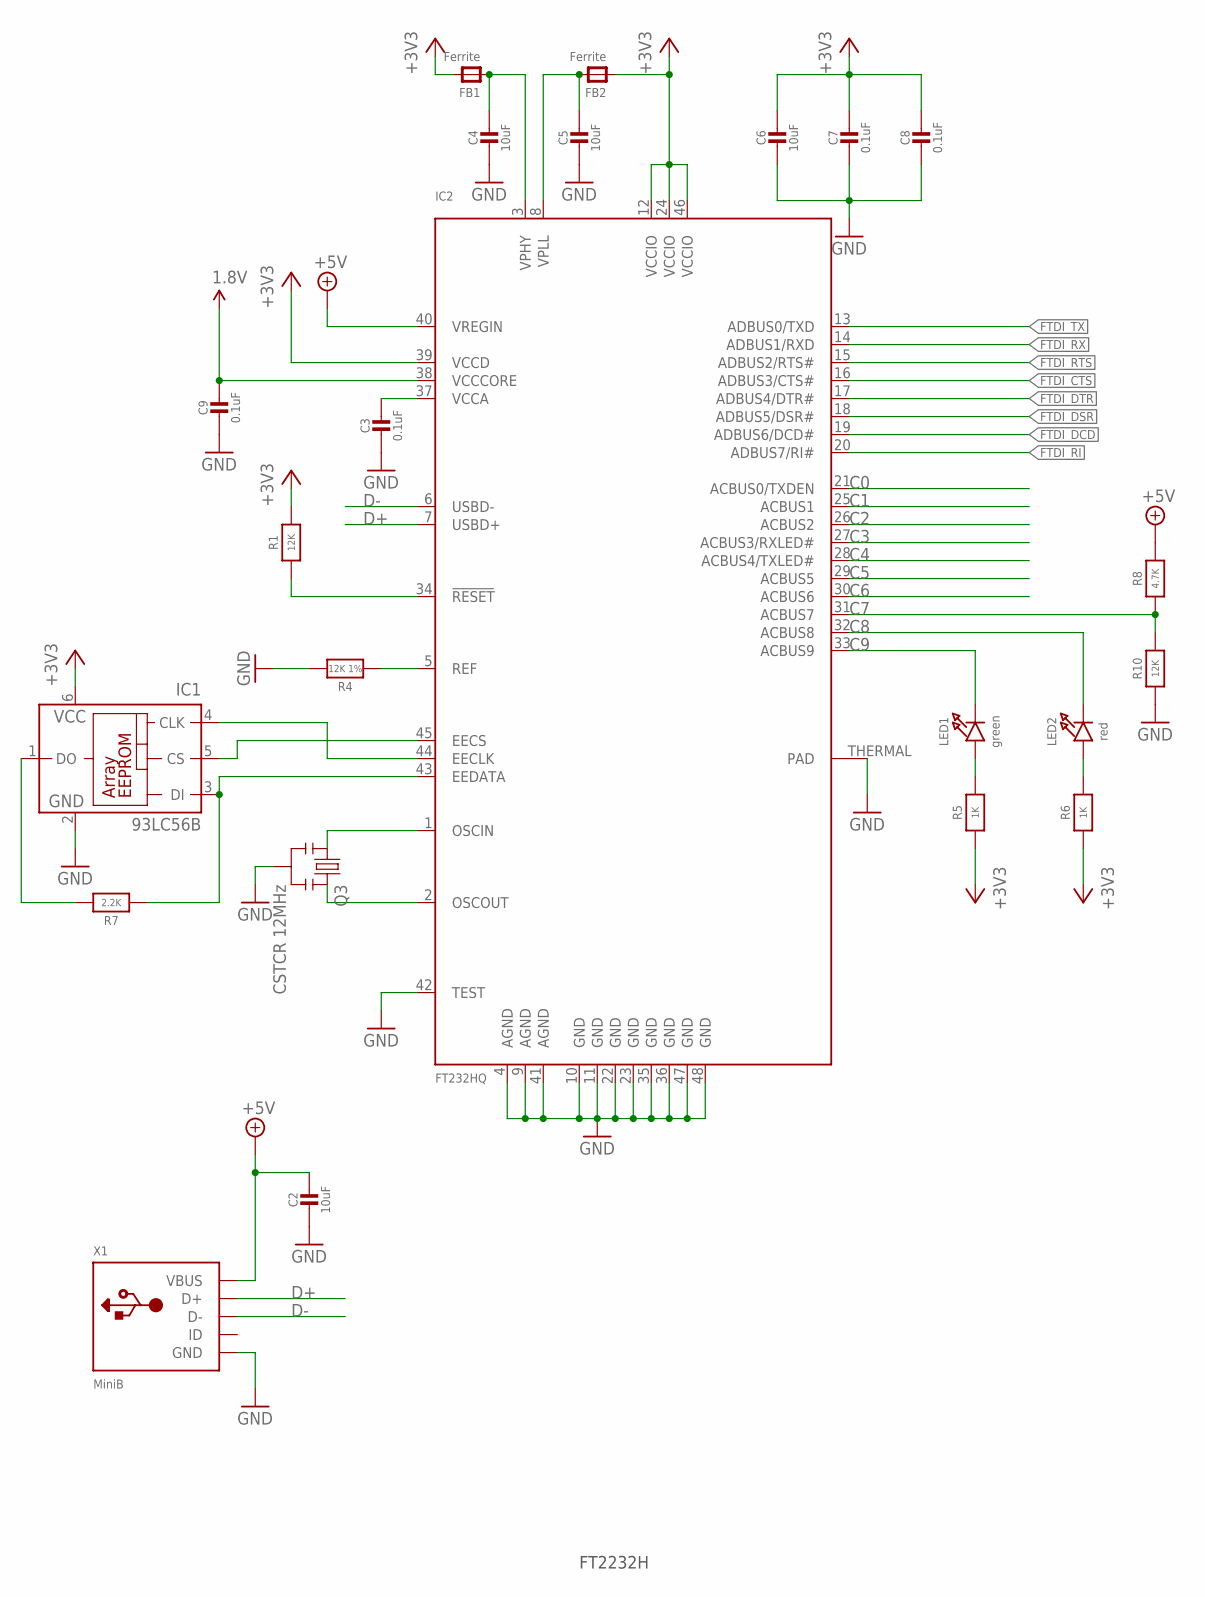
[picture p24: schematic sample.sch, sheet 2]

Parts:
C2, C4, C5, C6: 10uF; _0603MP
C3, C7, C8, C9: 0.1uF; _0603MP
FB1, FB2: Ferrite; _0603MP
IC1: 93LC56B; SOT23-6
IC2: FT232HQ; QFN48_8MM
LED1: green; CHIPLED_0603_NOOUTLINE
LED2: red; CHIPLED_0603_NOOUTLINE
Q3: CSTCR 12MHz; RESONATOR-SMD
R1, R10: 12K; _0603MP
R4: 12K 1%; _0603MP
R5, R6: 1K; _0603MP
R7: 2.2K; _0603MP
R8: 4.7K; _0603MP
X1: MiniB; 4UCONN_20329

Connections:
1.8V: C9.1, IC2.38 (VCCCORE)
+3V3: C6.1, C7.1, C8.1, FB1.2, FB2.1, IC1.6 (VCC), IC2.12 (VCCIO), IC2.24 (VCCIO), IC2.39 (VCCD), IC2.46 (VCCIO), R1.2, R5.1, R6.1; also elsewhere on the board
+5V: C2.1, IC2.40 (VREGIN), R8.2, X1.VBUS
C0: IC2.21 (ACBUS0/TXDEN)
C1: IC2.25 (ACBUS1)
C2: IC2.26 (ACBUS2)
C3: IC2.27 (ACBUS3/RXLED#)
C4: IC2.28 (ACBUS4/TXLED#)
C5: IC2.29 (ACBUS5)
C6: IC2.30 (ACBUS6)
C7: IC2.31 (ACBUS7), R8.1, R10.2
C8: IC2.32 (ACBUS8), LED2.C
C9: IC2.33 (ACBUS9), LED1.C
D+: IC2.7 (USBD+), X1.D+
D-: IC2.6 (USBD-), X1.D-
FTDI_CTS: IC2.16 (ADBUS3/CTS#)
FTDI_DCD: IC2.19 (ADBUS6/DCD#)
FTDI_DSR: IC2.18 (ADBUS5/DSR#)
FTDI_DTR: IC2.17 (ADBUS4/DTR#); also elsewhere on the board
FTDI_RI: IC2.20 (ADBUS7/RI#)
FTDI_RTS: IC2.15 (ADBUS2/RTS#); also elsewhere on the board
FTDI_RX: IC2.14 (ADBUS1/RXD); also elsewhere on the board
FTDI_TX: IC2.13 (ADBUS0/TXD); also elsewhere on the board
GND: C2.2, C3.2, C4.2, C5.2, C6.2, C7.2, C8.2, C9.2, IC1.2 (GND), IC2.4 (AGND), IC2.9 (AGND), IC2.10 (GND), IC2.11 (GND), IC2.22 (GND), IC2.23 (GND), IC2.35 (GND), IC2.36 (GND), IC2.41 (AGND), IC2.42 (TEST), IC2.47 (GND), IC2.48 (GND), IC2.THERMAL (PAD), Q3.2, R4.2, R10.1, X1.BASE@1 (GND), X1.BASE@2 (GND), X1.GND, X1.SPRT@1 (GND), X1.SPRT@2 (GND), X1.SPRT@3 (GND), X1.SPRT@4 (GND); also elsewhere on the board
unnamed: IC2.1 (OSCIN), Q3.1
unnamed: IC2.2 (OSCOUT), Q3.3
unnamed: IC2.5 (REF), R4.1
unnamed: LED2.A, R6.2
unnamed: IC2.34 (!RESET), R1.1
unnamed: LED1.A, R5.2
unnamed: IC1.3 (DI), IC2.43 (EEDATA), R7.1
unnamed: IC1.5 (CS), IC2.45 (EECS)
unnamed: IC1.4 (CLK), IC2.44 (EECLK)
unnamed: IC1.1 (DO), R7.2
VCCA: C3.1, IC2.37 (VCCA)
VPHY: C4.1, FB1.1, IC2.3 (VPHY)
VPLL: C5.1, FB2.2, IC2.8 (VPLL)

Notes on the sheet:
FT2232H

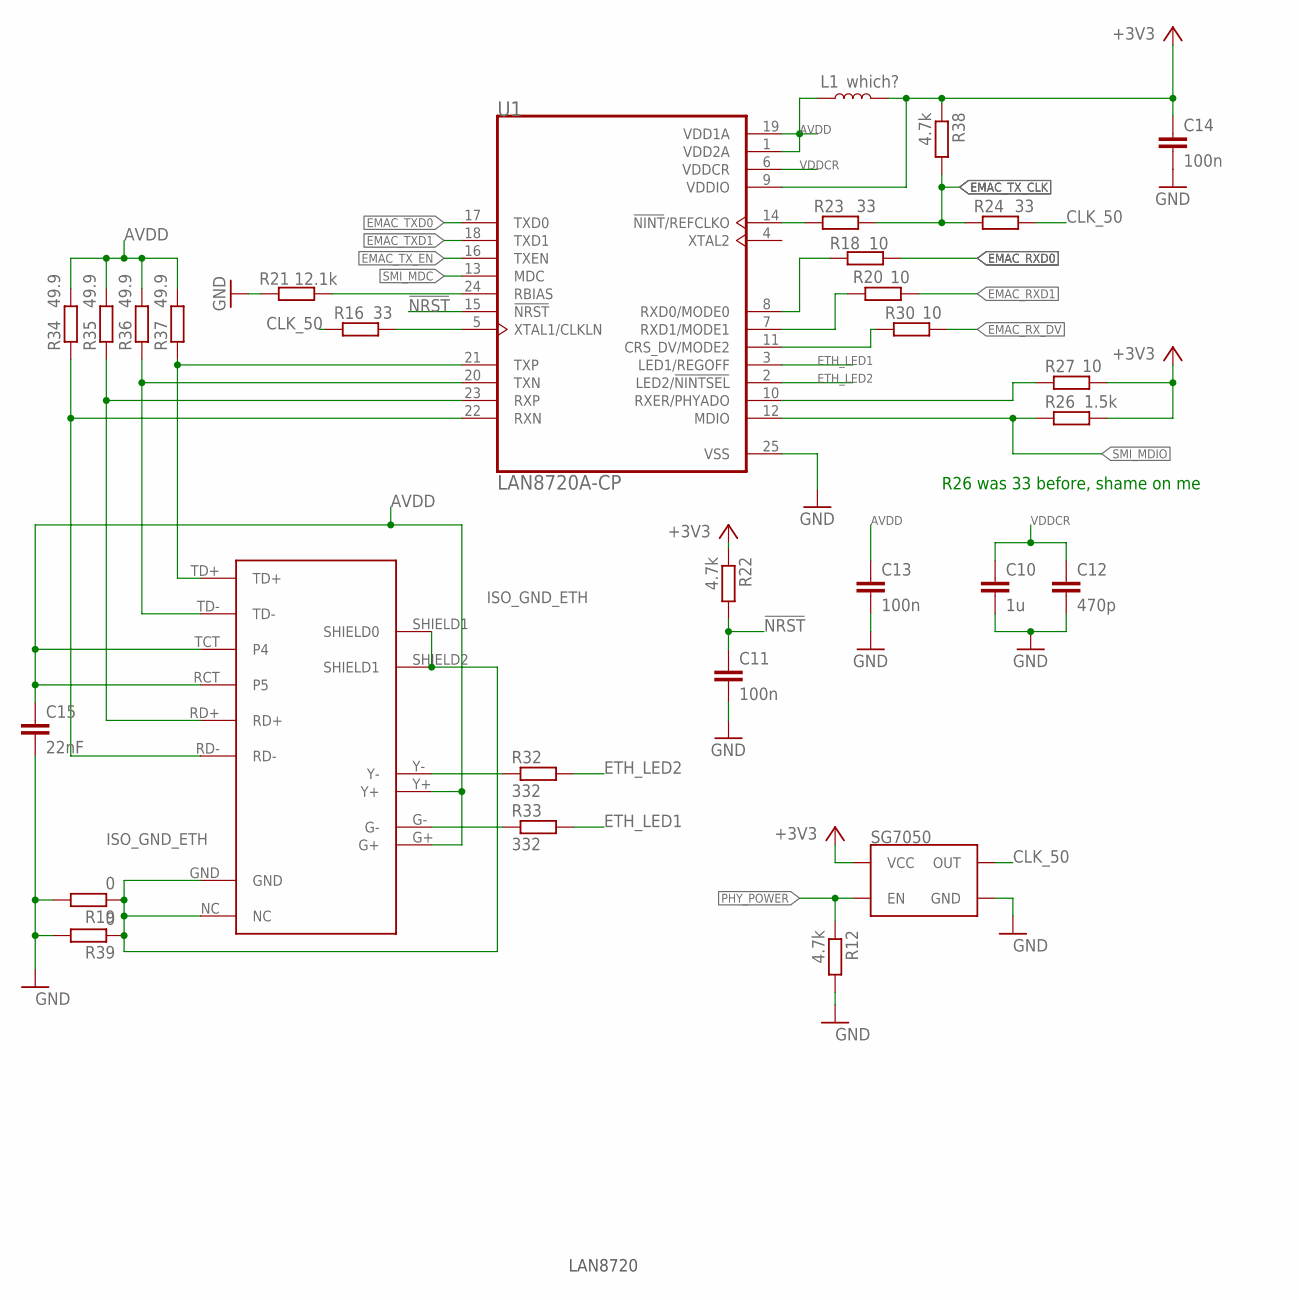
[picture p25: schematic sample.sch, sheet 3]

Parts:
C10: 1u; C0402
C11, C13, C14: 100n; C0603K
C12: 470p; C0402
C15: 22nF; C0603K
L1: which?; 0603
R12, R22, R38: 4.7k; R0603
R16, R23, R24: 33; R0603
R18, R20, R27, R30: 10; R0603
R19, R39: 0; R0603
R21: 12.1k; R0603
R26: 1.5k; R0603
R32, R33: 332; R0603
R34, R35, R36, R37: 49.9; R0603
SG7050: OSCILLATORSMD-7X5-4PAD; OSCILLATOR-SMD-7X5-4PAD
U1: LAN8720A-CP; QFN50P400X400X100-25N
U$2: HR911105A; RJ45

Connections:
!NRST: C11.1, R22.2, U1.15 (!NRST)
+3V3: C14.1, L1.2, R22.1, R26.2, R27.2, R38.1, SG7050.4 (VCC), U1.9 (VDDIO); also elsewhere on the board
AVDD: C13.1, C15.1, L1.1, R34.2, R35.2, R36.2, R37.2, U1.1 (VDD2A), U1.19 (VDD1A), U$2.G+, U$2.RCT (P5), U$2.TCT (P4), U$2.Y+
CLK_50: R16.1, R24.2, SG7050.3 (OUT)
EMAC_RXD0: R18.1; also elsewhere on the board
EMAC_RXD1: R20.1; also elsewhere on the board
EMAC_RX_DV: R30.2; also elsewhere on the board
EMAC_TXD0: U1.17 (TXD0); also elsewhere on the board
EMAC_TXD1: U1.18 (TXD1); also elsewhere on the board
EMAC_TX_CLK: R23.2, R24.1, R38.2; also elsewhere on the board
EMAC_TX_EN: U1.16 (TXEN); also elsewhere on the board
ETH_LED1: R33.2, U1.3 (LED1/REGOFF)
ETH_LED2: R32.2, U1.2 (LED2/!NINTSEL!)
GND: C10.2, C11.2, C12.2, C13.2, C14.2, C15.2, R12.2, R19.2, R21.2, R39.2, SG7050.2 (GND), U1.25 (VSS); also elsewhere on the board
ISO_GND_ETH: R19.1, R39.1, U$2.GND, U$2.NC, U$2.SHIELD1 (SHIELD0), U$2.SHIELD2 (SHIELD1)
unnamed: R20.2, U1.7 (RXD1/MODE1)
unnamed: R18.2, U1.8 (RXD0/MODE0)
unnamed: R21.1, U1.24 (RBIAS)
unnamed: R32.1, U$2.Y-
unnamed: R16.2, U1.5 (XTAL1/CLKLN)
unnamed: R27.1, U1.10 (RXER/PHYADO)
unnamed: R23.1, U1.14 (!NINT!/REFCLKO)
unnamed: R30.1, U1.11 (CRS_DV/MODE2)
unnamed: R33.1, U$2.G-
PHY_POWER: R12.1, SG7050.1 (EN); also elsewhere on the board
RD_N: R34.1, U1.22 (RXN), U$2.RD-
RD_P: R35.1, U1.23 (RXP), U$2.RD+
SMI_MDC: U1.13 (MDC); also elsewhere on the board
SMI_MDIO: R26.1, U1.12 (MDIO); also elsewhere on the board
TD_N: R36.1, U1.20 (TXN), U$2.TD-
TD_P: R37.1, U1.21 (TXP), U$2.TD+
VDDCR: C10.1, C12.1, U1.6 (VDDCR)

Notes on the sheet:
LAN8720
R26 was 33 before, shame on me

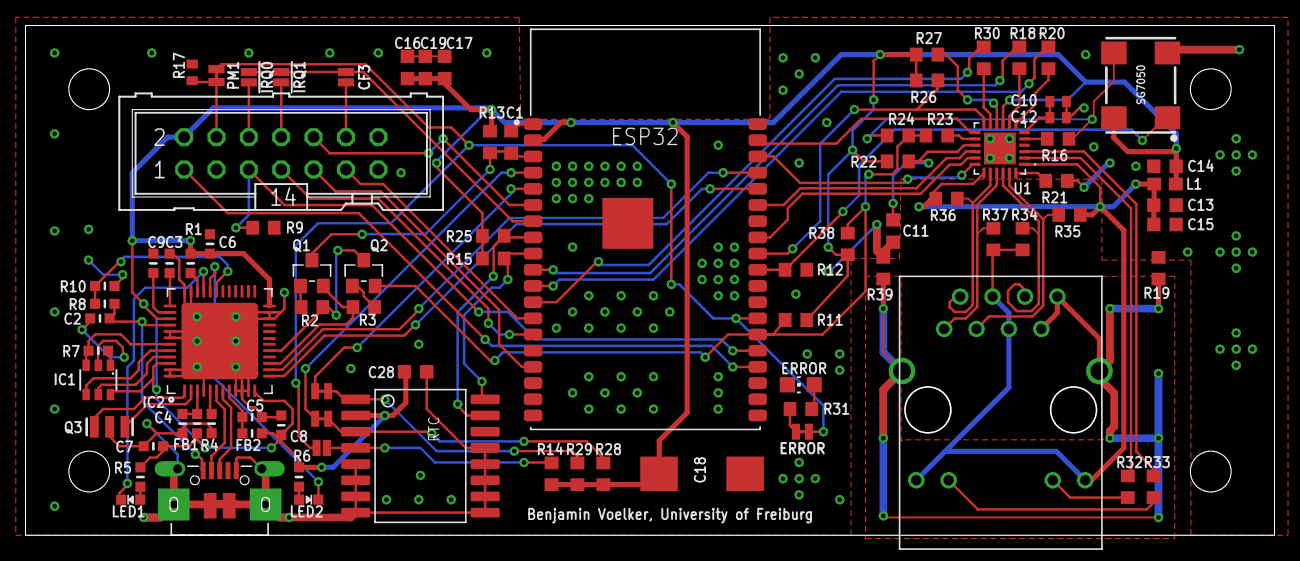
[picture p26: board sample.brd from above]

Board: 2 copper layers, 98.0 x 40.0 mm, 85 parts (0 on the bottom side), 80 nets.

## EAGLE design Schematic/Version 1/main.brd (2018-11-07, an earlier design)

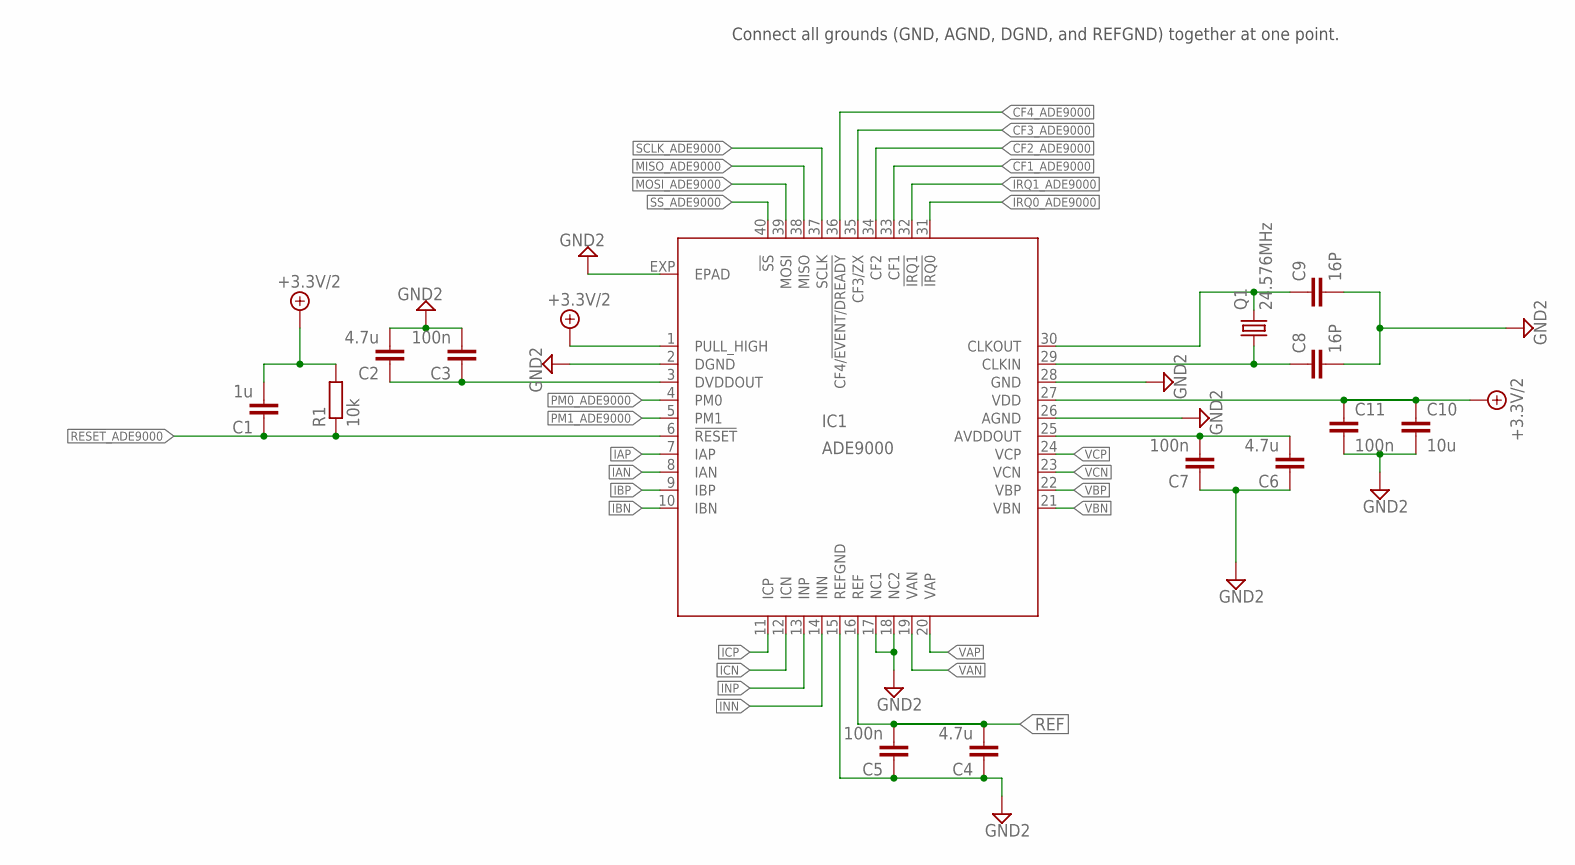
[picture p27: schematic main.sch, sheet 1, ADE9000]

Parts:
C1: 1u; C0805
C2, C4, C6: 4.7u; C0805
C3, C5, C7, C11: 100n; C0805
C8, C9: 16P; C0805K
C10: 10u; C1206K
IC1: ADE9000; QFN40
Q1: 24.576MHz; HC49UP
R1: 10k; R0805

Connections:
!IRQ0!_ADE9000: IC1.31 (!IRQ0); also elsewhere on the board
!IRQ1!_ADE9000: IC1.32 (!IRQ1); also elsewhere on the board
!RESET!_ADE9000: C1.1, IC1.6 (!RESET), R1.1; also elsewhere on the board
+3.3V/2: C1.2, C10.1, C11.1, IC1.1 (PULL_HIGH), IC1.27 (VDD), R1.2; also elsewhere on the board
CF1_ADE9000: IC1.33 (CF1); also elsewhere on the board
CF2_ADE9000: IC1.34 (CF2); also elsewhere on the board
CF3_ADE9000: IC1.35 (CF3/ZX); also elsewhere on the board
CF4_ADE9000: IC1.36 (CF4/!EVENT/DREADY); also elsewhere on the board
GND2: C2.2, C3.2, C4.1, C5.1, C6.1, C7.1, C8.2, C9.2, C10.2, C11.2, IC1.2 (DGND), IC1.15 (REFGND), IC1.17 (NC1), IC1.18 (NC2), IC1.26 (AGND), IC1.28 (GND), IC1.EXP (EPAD); also elsewhere on the board
IAN: IC1.8 (IAN); also elsewhere on the board
IAP: IC1.7 (IAP); also elsewhere on the board
IBN: IC1.10 (IBN); also elsewhere on the board
IBP: IC1.9 (IBP); also elsewhere on the board
ICN: IC1.12 (ICN); also elsewhere on the board
ICP: IC1.11 (ICP); also elsewhere on the board
INN: IC1.14 (INN); also elsewhere on the board
INP: IC1.13 (INP); also elsewhere on the board
MISO_ADE9000: IC1.38 (MISO); also elsewhere on the board
MOSI_ADE9000: IC1.39 (MOSI); also elsewhere on the board
unnamed: C2.1, C3.1, IC1.3 (DVDDOUT)
unnamed: C6.2, C7.2, IC1.25 (AVDDOUT)
unnamed: C8.1, IC1.29 (CLKIN), Q1.1
unnamed: C9.1, IC1.30 (CLKOUT), Q1.2
PM0_ADE9000: IC1.4 (PM0); also elsewhere on the board
PM1_ADE9000: IC1.5 (PM1); also elsewhere on the board
REF: C4.2, C5.2, IC1.16 (REF); also elsewhere on the board
SCLK_ADE9000: IC1.37 (SCLK); also elsewhere on the board
SS_ADE9000: IC1.40 (!SS); also elsewhere on the board
VAN: IC1.19 (VAN); also elsewhere on the board
VAP: IC1.20 (VAP); also elsewhere on the board
VBN: IC1.21 (VBN); also elsewhere on the board
VBP: IC1.22 (VBP); also elsewhere on the board
VCN: IC1.23 (VCN); also elsewhere on the board
VCP: IC1.24 (VCP); also elsewhere on the board

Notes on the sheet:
Connect all grounds (GND, AGND, DGND, and REFGND) together at one point.

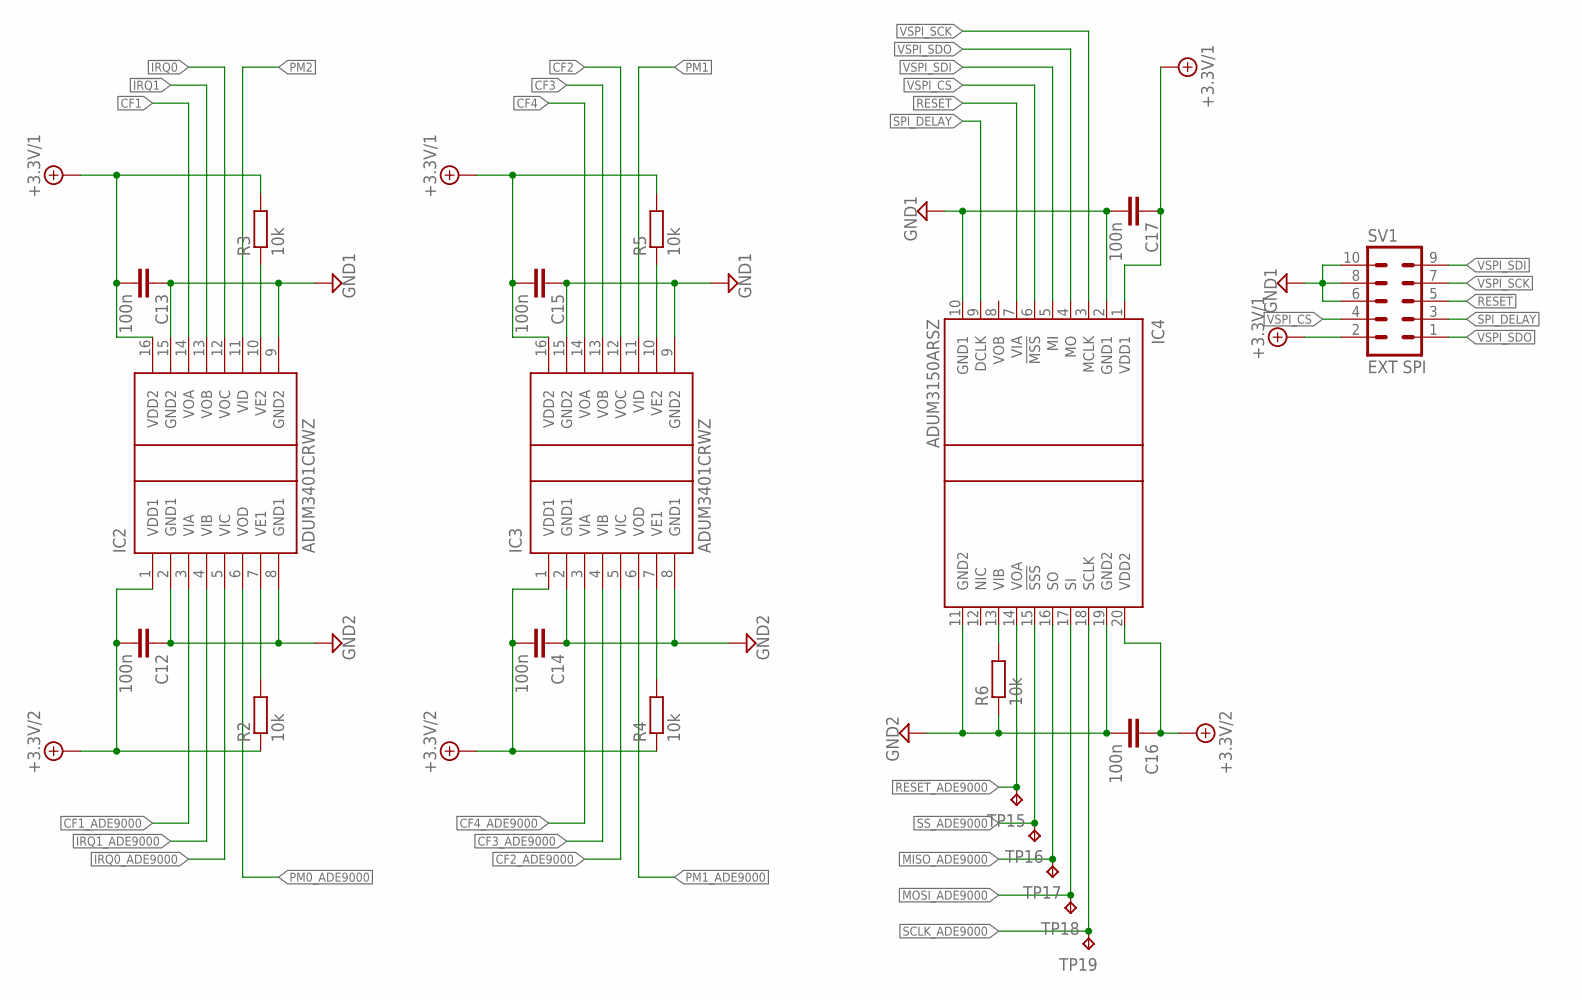
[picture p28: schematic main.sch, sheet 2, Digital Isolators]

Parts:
C12, C13, C14, C15, C16, C17: 100n; C0805
IC2, IC3: ADUM3401CRWZ; SO16W
IC4: ADUM3150ARSZ; SSOP20
R2, R3, R4, R5, R6: 10k; R0805
SV1: EXT SPI; ML10
TP15, TP16, TP17, TP18, TP19: TPB1,27; B1,27

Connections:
!IRQ0: IC2.12 (VOC); also elsewhere on the board
!IRQ0!_ADE9000: IC2.5 (VIC); also elsewhere on the board
!IRQ1: IC2.13 (VOB); also elsewhere on the board
!IRQ1!_ADE9000: IC2.4 (VIB); also elsewhere on the board
!RESET: IC4.7 (VIA), SV1.5; also elsewhere on the board
!RESET!_ADE9000: IC4.14 (VOA), TP15.TP; also elsewhere on the board
+3.3V/1: C13.2, C15.2, C17.1, IC2.16 (VDD2), IC3.16 (VDD2), IC4.1 (VDD1), R3.2, R5.2, SV1.2; also elsewhere on the board
+3.3V/2: C12.2, C14.2, C16.1, IC2.1 (VDD1), IC3.1 (VDD1), IC4.20 (VDD2), R2.1, R4.1; also elsewhere on the board
CF1: IC2.14 (VOA); also elsewhere on the board
CF1_ADE9000: IC2.3 (VIA); also elsewhere on the board
CF2: IC3.12 (VOC); also elsewhere on the board
CF2_ADE9000: IC3.5 (VIC); also elsewhere on the board
CF3: IC3.13 (VOB); also elsewhere on the board
CF3_ADE9000: IC3.4 (VIB); also elsewhere on the board
CF4: IC3.14 (VOA); also elsewhere on the board
CF4_ADE9000: IC3.3 (VIA); also elsewhere on the board
GND1: C13.1, C15.1, C17.2, IC2.9 (GND2), IC2.15 (GND2), IC3.9 (GND2), IC3.15 (GND2), IC4.2 (GND1), IC4.10 (GND1), SV1.6, SV1.8, SV1.10; also elsewhere on the board
GND2: C12.1, C14.1, C16.2, IC2.2 (GND1), IC2.8 (GND1), IC3.2 (GND1), IC3.8 (GND1), IC4.11 (GND2), IC4.19 (GND2), R6.1; also elsewhere on the board
MISO_ADE9000: IC4.16 (SO), TP17.TP; also elsewhere on the board
MOSI_ADE9000: IC4.17 (SI), TP18.TP; also elsewhere on the board
unnamed: IC2.10 (VE2), R3.1
unnamed: IC4.13 (VIB), R6.2
unnamed: IC3.7 (VE1), R4.2
unnamed: IC3.10 (VE2), R5.1
unnamed: IC2.7 (VE1), R2.2
PM0_ADE9000: IC2.6 (VOD); also elsewhere on the board
PM1: IC3.11 (VID); also elsewhere on the board
PM1_ADE9000: IC3.6 (VOD); also elsewhere on the board
PM2: IC2.11 (VID); also elsewhere on the board
SCLK_ADE9000: IC4.18 (SCLK), TP19.TP; also elsewhere on the board
SPI_DELAY: IC4.9 (DCLK), SV1.3; also elsewhere on the board
SS_ADE9000: IC4.15 (!SSS), TP16.TP; also elsewhere on the board
VSPI_CS: IC4.6 (!MSS), SV1.4; also elsewhere on the board
VSPI_SCK: IC4.3 (MCLK), SV1.7; also elsewhere on the board
VSPI_SDI: IC4.5 (MI), SV1.9; also elsewhere on the board
VSPI_SDO: IC4.4 (MO), SV1.1; also elsewhere on the board

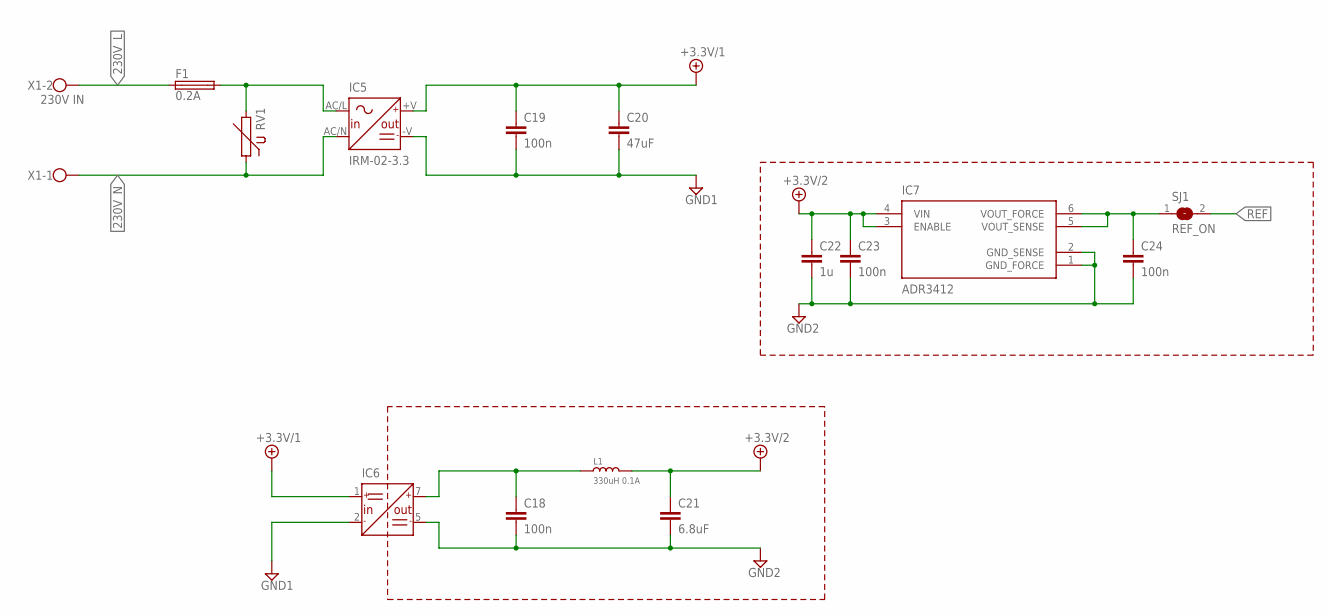
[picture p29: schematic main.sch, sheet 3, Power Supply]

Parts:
C18, C19, C23, C24: 100n; C0805
C20: 47uF; C3216
C21: 6.8uF; C3216
C22: 1u; C0805
F1: 0.2A; SH22,5A
IC5: IRM-02-3.3; MW_IRM-02
IC6: MURATA-PS-MEF1SXXXXSP3C; SIP-7PIN-1257
IC7: ADR3412; SOT-23-6
L1: 330uH 0.1A; L1008
RV1: B72210S0321K101; TDK_E7.5_A2.4_W12.0_TH5.4_H15.0_D0.8
SJ1: REF_ON; SJ
X1: 230V IN; W237-113

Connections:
230V_L: F1.1, X1.2
230V_N: IC5.AC/N (N), RV1.1, X1.1
+3.3V/1: C19.1, C20.1, IC5.+V (+V_OUT), IC6.1 (+V_IN); also elsewhere on the board
+3.3V/2: C21.1, C22.1, C23.1, IC7.3 (ENABLE), IC7.4 (VIN), L1.2; also elsewhere on the board
GND1: C19.2, C20.2, IC5.-V (-V_OUT), IC6.2 (-V_IN); also elsewhere on the board
GND2: C18.2, C21.2, C22.2, C23.2, C24.2, IC6.5 (-V_OUT), IC7.1 (GND_FORCE), IC7.2 (GND_SENSE); also elsewhere on the board
unnamed: C18.1, IC6.7 (+V_OUT), L1.1
unnamed: F1.2, IC5.AC/L (L), RV1.2
unnamed: C24.1, IC7.5 (VOUT_SENSE), IC7.6 (VOUT_FORCE), SJ1.1
REF: SJ1.2; also elsewhere on the board

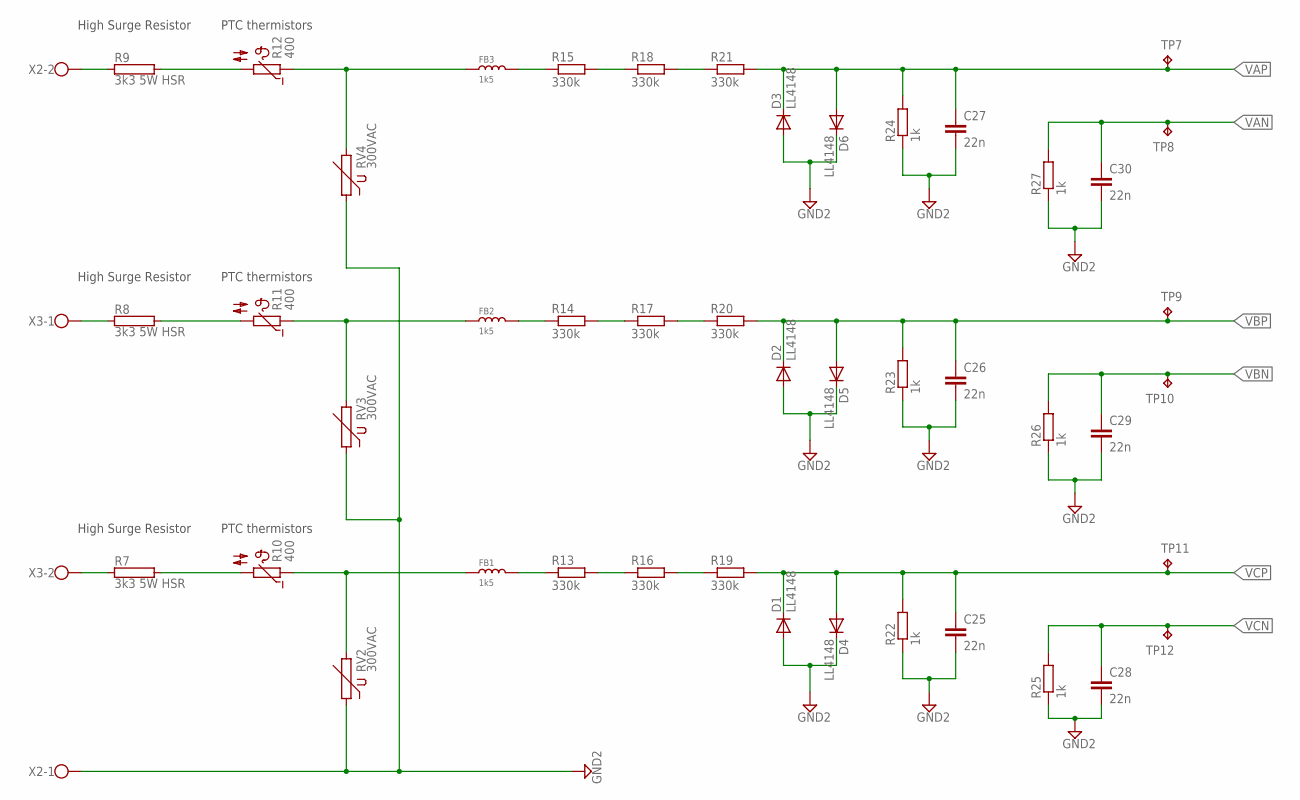
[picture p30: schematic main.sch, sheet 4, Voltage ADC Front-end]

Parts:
C25, C26, C27, C28, C29, C30: 22n; C0805
D1, D2, D3, D4, D5, D6: LL4148; SOD80C
FB1, FB2, FB3: 1k5; L0805
R7, R8, R9: 3k3 5W HSR; AC05
R10, R11, R12: 400; PTCCL10H010SBE
R13, R14, R15, R16, R17, R18, R19, R20, R21: 330k; R1206
R22, R23, R24, R25, R26, R27: 1k; R1206
RV2, RV3, RV4: 300VAC; TDK_E10.0_A2.4_W21.5_TH5.6_H25.5_D1.0
TP7, TP8, TP9, TP10, TP11, TP12: TPB1,27; B1,27
X2, X3: W237-113

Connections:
GND2: C25.2, C26.2, C27.2, C28.2, C29.2, C30.2, D1.A, D2.A, D3.A, D4.C, D5.C, D6.C, R22.1, R23.1, R24.1, R25.1, R26.1, R27.1, RV2.1, RV3.1, RV4.1, X2.1; also elsewhere on the board
unnamed: R9.2, R12.2
unnamed: FB3.1, R12.1, RV4.2
unnamed: FB3.2, R15.1
unnamed: R8.2, R11.2
unnamed: FB2.1, R11.1, RV3.2
unnamed: R7.1, X3.2
unnamed: R15.2, R18.1
unnamed: FB2.2, R14.1
unnamed: R14.2, R17.1
unnamed: R17.2, R20.1
unnamed: R18.2, R21.1
unnamed: R7.2, R10.2
unnamed: FB1.1, R10.1, RV2.2
unnamed: R8.1, X3.1
unnamed: FB1.2, R13.1
unnamed: R13.2, R16.1
unnamed: R16.2, R19.1
unnamed: R9.1, X2.2
VAN: C30.1, R27.2, TP8.TP; also elsewhere on the board
VAP: C27.1, D3.C, D6.A, R21.2, R24.2, TP7.TP; also elsewhere on the board
VBN: C29.1, R26.2, TP10.TP; also elsewhere on the board
VBP: C26.1, D2.C, D5.A, R20.2, R23.2, TP9.TP; also elsewhere on the board
VCN: C28.1, R25.2, TP12.TP; also elsewhere on the board
VCP: C25.1, D1.C, D4.A, R19.2, R22.2, TP11.TP; also elsewhere on the board

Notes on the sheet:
High Surge Resistor
PTC thermistors

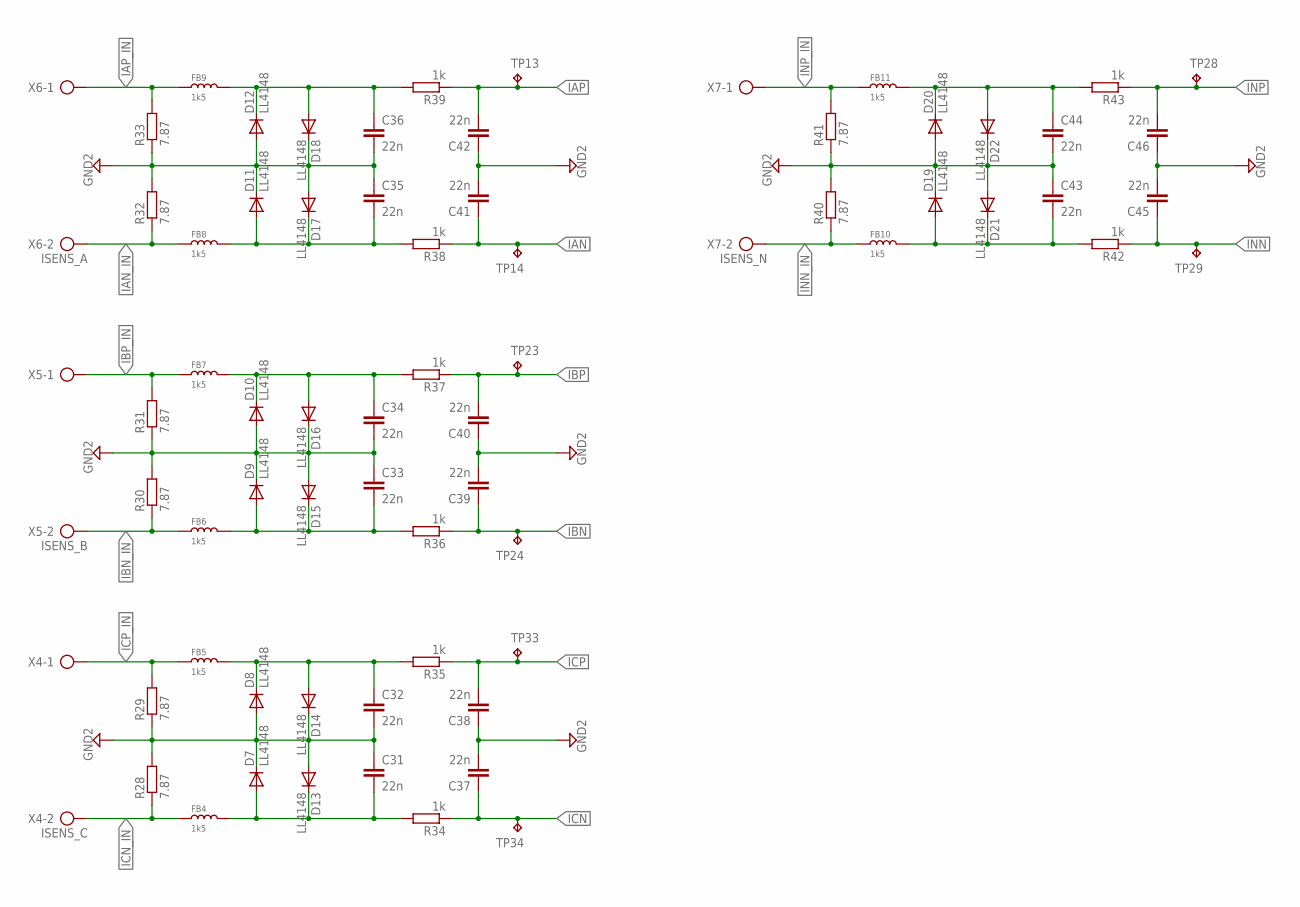
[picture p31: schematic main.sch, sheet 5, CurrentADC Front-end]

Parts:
C31, C32, C33, C34, C35, C36, C37, C38, C39, C40, C41, C42, C43, C44, C45, C46: 22n; C0805
D7, D8, D9, D10, D11, D12, D13, D14, D15, D16, D17, D18, D19, D20, D21, D22: LL4148; SOD80C
FB4, FB5, FB6, FB7, FB8, FB9, FB10, FB11: 1k5; L0805
R28, R29, R30, R31, R32, R33, R40, R41: 7.87; R1206
R34, R35, R36, R37, R38, R39, R42, R43: 1k; R1206
TP13, TP14, TP23, TP24, TP28, TP29, TP33, TP34: TPB1,27; B1,27
X4: ISENS_C; AK500/2
X5: ISENS_B; AK500/2
X6: ISENS_A; AK500/2
X7: ISENS_N; AK500/2

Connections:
GND2: C31.1, C32.2, C33.1, C34.2, C35.1, C36.2, C37.2, C38.1, C39.2, C40.1, C41.2, C42.1, C43.1, C44.2, C45.2, C46.1, D7.C, D8.A, D9.C, D10.A, D11.C, D12.A, D13.A, D14.C, D15.A, D16.C, D17.A, D18.C, D19.C, D20.A, D21.A, D22.C, R28.2, R29.1, R30.2, R31.1, R32.2, R33.1, R40.2, R41.1; also elsewhere on the board
IAN: C41.1, R38.1, TP14.TP; also elsewhere on the board
IAN_IN: FB8.1, R32.1, X6.2
IAP: C42.2, R39.1, TP13.TP; also elsewhere on the board
IAP_IN: FB9.1, R33.2, X6.1
IBN: C39.1, R36.1, TP24.TP; also elsewhere on the board
IBN_IN: FB6.1, R30.1, X5.2
IBP: C40.2, R37.1, TP23.TP; also elsewhere on the board
IBP_IN: FB7.1, R31.2, X5.1
ICN: C37.1, R34.1, TP34.TP; also elsewhere on the board
ICN_IN: FB4.1, R28.1, X4.2
ICP: C38.2, R35.1, TP33.TP; also elsewhere on the board
ICP_IN: FB5.1, R29.2, X4.1
INN: C45.1, R42.1, TP29.TP; also elsewhere on the board
INN_IN: FB10.1, R40.1, X7.2
INP: C46.2, R43.1, TP28.TP; also elsewhere on the board
INP_IN: FB11.1, R41.2, X7.1
unnamed: C33.2, D9.A, D15.C, FB6.2, R36.2
unnamed: C43.2, D19.A, D21.C, FB10.2, R42.2
unnamed: C31.2, D7.A, D13.C, FB4.2, R34.2
unnamed: C35.2, D11.A, D17.C, FB8.2, R38.2
VBN1: C36.1, D12.C, D18.A, FB9.2, R39.2
VBN2: C34.1, D10.C, D16.A, FB7.2, R37.2
VBN3: C44.1, D20.C, D22.A, FB11.2, R43.2
VBN4: C32.1, D8.C, D14.A, FB5.2, R35.2

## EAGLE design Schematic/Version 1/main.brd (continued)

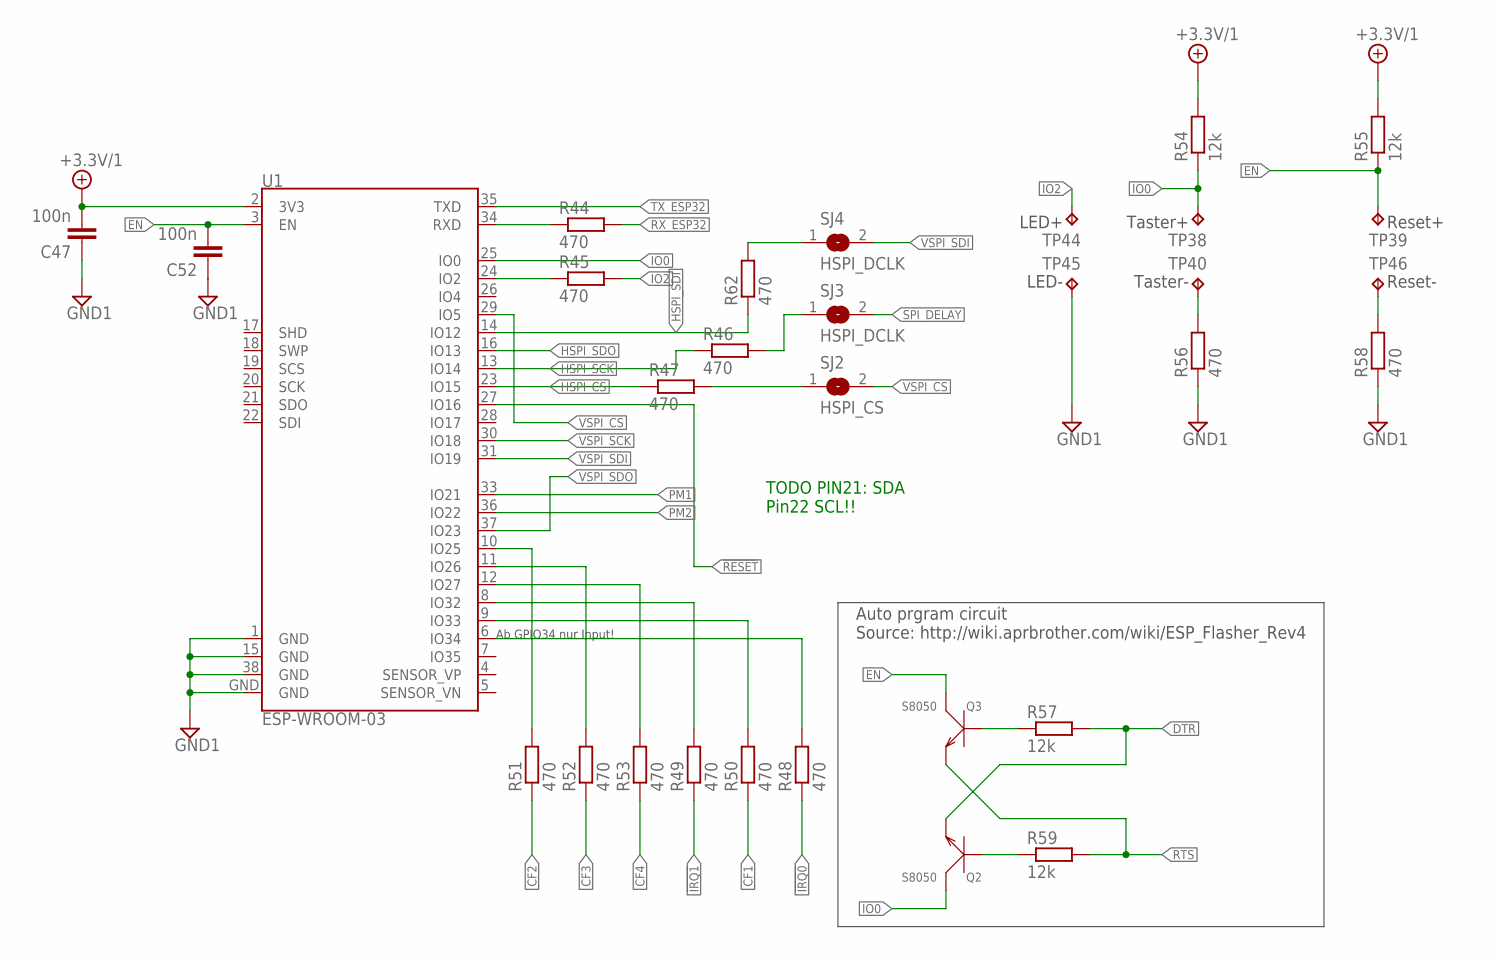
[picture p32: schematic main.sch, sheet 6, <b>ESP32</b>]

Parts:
C47, C52: 100n; C0805
Q2, Q3: S8050; SOT-23
R44, R45, R46, R47, R48, R49, R50, R51, R52, R53, R56, R58, R62: 470; R0805
R54, R55, R57, R59: 12k; R0805
SJ2: HSPI_CS; SJ
SJ3, SJ4: HSPI_DCLK; SJ
TP38, TP39, TP40, TP44, TP45, TP46: TPPAD1-13Y; P1-13Y
U1: ESP-WROOM-03

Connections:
!IRQ0: R48.1; also elsewhere on the board
!IRQ1: R49.1; also elsewhere on the board
!RESET: U1.27 (IO16); also elsewhere on the board
+3.3V/1: C47.2, R54.2, R55.2, U1.2 (3V3); also elsewhere on the board
CF1: R50.1; also elsewhere on the board
CF2: R51.1; also elsewhere on the board
CF3: R52.1; also elsewhere on the board
CF4: R53.1; also elsewhere on the board
DTR: Q2.2 (E), R57.2; also elsewhere on the board
EN: C52.2, Q3.3 (C), R55.1, TP39.TP, U1.3 (EN)
GND1: C47.1, C52.1, R56.1, R58.1, TP45.TP, U1.1 (GND), U1.15 (GND), U1.38 (GND), U1.GND; also elsewhere on the board
HSPI_CS: R47.1, U1.23 (IO15)
HSPI_SCK: R46.1, U1.13 (IO14)
HSPI_SDI: R62.1, U1.14 (IO12)
HSPI_SDO: U1.16 (IO13)
IO0: Q2.3 (C), R54.1, TP38.TP, U1.25 (IO0)
IO2: R45.2, TP44.TP
unnamed: R62.2, SJ4.1
unnamed: R44.1, U1.34 (RXD)
unnamed: R45.1, U1.24 (IO2)
unnamed: Q3.1 (B), R57.1
unnamed: Q2.1 (B), R59.1
unnamed: R56.2, TP40.TP
unnamed: R58.2, TP46.TP
unnamed: R46.2, SJ3.1
unnamed: R47.2, SJ2.1
unnamed: R48.2, U1.6 (IO34)
unnamed: R49.2, U1.8 (IO32)
unnamed: R50.2, U1.9 (IO33)
unnamed: R51.2, U1.10 (IO25)
unnamed: R52.2, U1.11 (IO26)
unnamed: R53.2, U1.12 (IO27)
PM1: U1.33 (IO21); also elsewhere on the board
PM2: U1.36 (IO22); also elsewhere on the board
RTS: Q3.2 (E), R59.2; also elsewhere on the board
RX_ESP32: R44.2; also elsewhere on the board
SPI_DELAY: SJ3.2; also elsewhere on the board
TX_ESP32: U1.35 (TXD); also elsewhere on the board
VSPI_CS: SJ2.2, U1.29 (IO5); also elsewhere on the board
VSPI_SCK: U1.30 (IO18); also elsewhere on the board
VSPI_SDI: SJ4.2, U1.31 (IO19); also elsewhere on the board
VSPI_SDO: U1.37 (IO23); also elsewhere on the board

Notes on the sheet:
Ab GPIO34 nur Input!
TODO PIN21: SDA Pin22 SCL!!
Auto prgram circuit Source: http://wiki.aprbrother.com/wiki/ESP_Flasher_Rev4

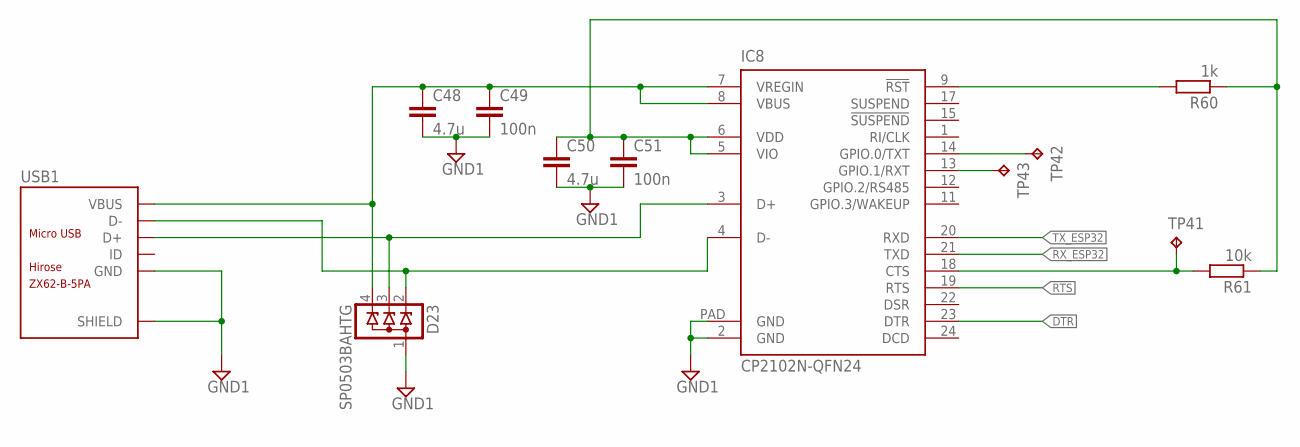
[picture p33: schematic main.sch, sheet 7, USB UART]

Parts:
C48, C50: 4.7u; C0805
C49, C51: 100n; C0805
D23: SP0503BAHTG; SOT143-4-R
IC8: CP2102N-QFN24; QFN24
R60: 1k; R0805
R61: 10k; R0805
TP41, TP42, TP43: TPB1,27; B1,27
USB1: ZX62-B-5PA; MICRO-USB5+6P-SMD-0.65-AB

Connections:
CP2102_3.3V: C50.1, C51.1, IC8.5 (VIO), IC8.6 (VDD), R60.1, R61.1
DTR: IC8.23 (DTR); also elsewhere on the board
GND1: C48.2, C49.2, C50.2, C51.2, D23.1, IC8.2 (GND), IC8.PAD (GND), USB1.5 (GND), USB1.P1 (SHIELD), USB1.P2 (SHIELD), USB1.P3 (SHIELD), USB1.P4 (SHIELD), USB1.P5 (SHIELD), USB1.P6 (SHIELD); also elsewhere on the board
unnamed: IC8.18 (CTS), R61.2, TP41.TP
unnamed: IC8.9 (!RST), R60.2
unnamed: IC8.14 (GPIO.0/TXT), TP42.TP
unnamed: IC8.13 (GPIO.1/RXT), TP43.TP
RTS: IC8.19 (RTS); also elsewhere on the board
RX_ESP32: IC8.21 (TXD); also elsewhere on the board
TX_ESP32: IC8.20 (RXD); also elsewhere on the board
USB_D+: D23.3, IC8.3 (D+), USB1.3 (D+)
USB_D-: D23.2, IC8.4 (D-), USB1.2 (D-)
VBUS: C48.1, C49.1, D23.4, IC8.7 (VREGIN), IC8.8 (VBUS), USB1.1 (VBUS)

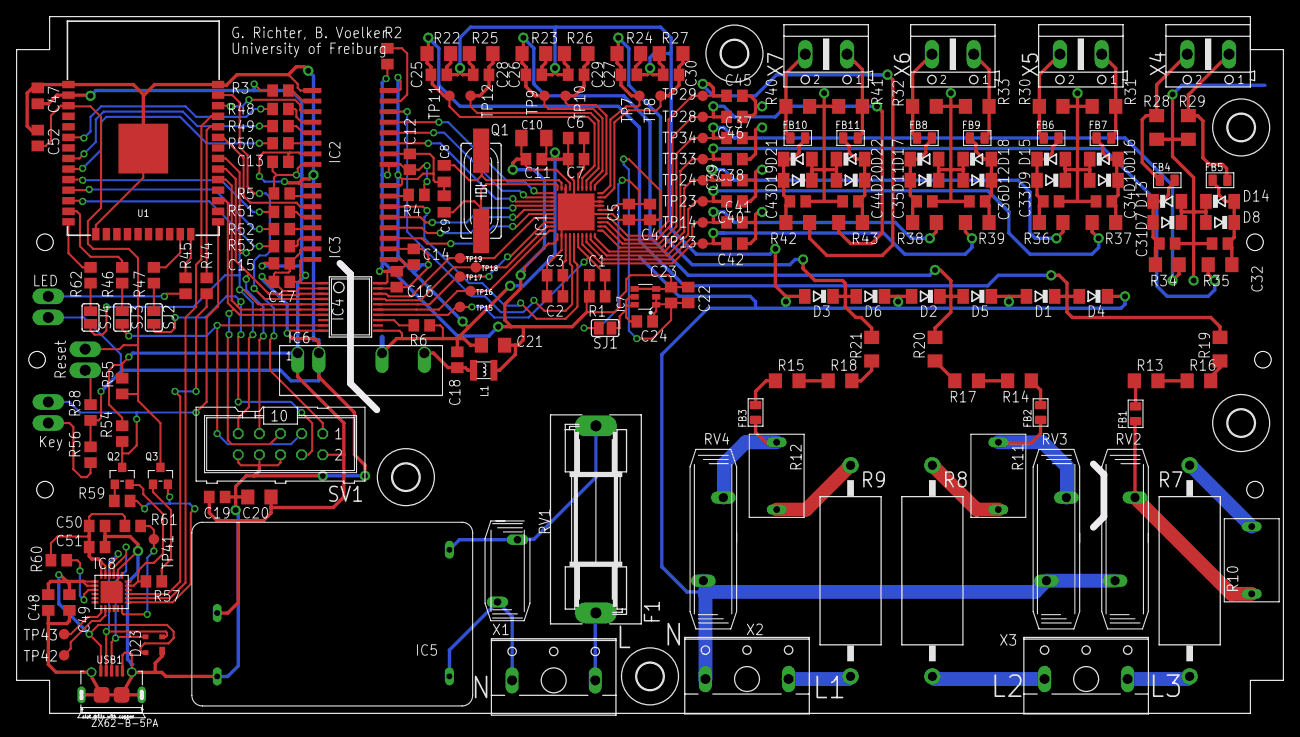
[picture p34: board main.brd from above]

Board: 2 copper layers, 152.4 x 83.8 mm, 212 parts (0 on the bottom side), 127 nets.

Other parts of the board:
U$1, U$2, U$3, U$4, U$5: 3,2

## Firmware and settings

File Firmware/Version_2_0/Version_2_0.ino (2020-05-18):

#include <Arduino.h>
#include <ArduinoOTA.h>
#include <esp_wifi.h>
#include <WiFi.h>
#include <WiFiAP.h>
#include <time.h>
#include <ArduinoJson.h>
#include <TimeLib.h>
#include <ESPmDNS.h>
#include <esp_int_wdt.h>
#include <esp_task_wdt.h>
#include <esp_sleep.h>
#include <esp_bt.h>
#include <esp32-hal-cpu.h>
#include <rom/rtc.h>

#include "constDefine.h"
#include "enums.h"
#include "src/ADE9000/ADE9000.h"
#include "src/config/config.h"
#include "src/ringbuffer/ringbuffer.h"
#include "src/network/network.h"
#include "src/rtc/rtc.h"
#include "src/time/timeHandling.h"
#include "src/logger/logger.h"
#include "src/mqtt/mqtt.h"

void IRAM_ATTR isr_adc_ready();
void IRAM_ATTR sqwvTriggered(void* instance);
void ntpSynced();

// Serial logger
StreamLogger serialLog((Stream*)&Serial, &timeStr, &LOG_PREFIX_SERIAL[0], ALL);
// SPIFFS logger
SPIFFSLogger spiffsLog(false, &LOG_FILE[0], &timeStr, &LOG_PREFIX_SERIAL[0], WARNING);

// MultiLogger logger(&streamLog, &timeStr);
// Create singleton here
MultiLogger& logger = MultiLogger::getInstance();

Configuration config;

Rtc rtc(RTC_INT, SDA, SCL);
TimeHandler myTime(config.timeServer, LOCATION_TIME_OFFSET, &rtc, &ntpSynced);

// ADE900 Object
ADE9000 ade9k(ADE_RESET_PIN, ADE_DREADY_PIN, ADE_PM1_PIN, ADE_SPI_BUS);

RingBuffer ringBuffer(PS_BUF_SIZE, true);

// counter holds # isr calls
volatile uint32_t counter = 0;
// Last micros() count of isr call
volatile long nowTs = 0;
volatile long lastTs = 0;

#define SEND_BUF_SIZE MAX_SEND_SIZE+16
static uint8_t sendbuffer[SEND_BUF_SIZE] = {0};
// Buffer read/write position
uint32_t psdReadPtr = 0;
uint32_t psdWritePtr = 0;
volatile uint32_t writePtr = 0;

// Open two TCP ports, one for commands and sampling and one for a raw data stream
WiFiServer server(STANDARD_TCP_SAMPLE_PORT);
WiFiServer streamServer(STANDARD_TCP_STREAM_PORT);

// TIMER stuff
// Calculate the number of cycles we have to wait
volatile uint32_t TIMER_CYCLES_FAST = (1000000) / DEFAULT_SR; // Cycles between HW timer inerrupts
volatile uint32_t timer_next;
volatile uint32_t timer_now;

SampleState state = SampleState::IDLE;
SampleState next_state = SampleState::IDLE;

// Define it before StreamType enum redefines it
MQTT mqtt;

struct StreamConfig {
  bool prefix = false;                      // Send data with "data:" prefix
  bool flowControl = false;                 // ifg flow ctr is used
  Measures measures = Measures::VI;         // The measures to send
  uint8_t measurementBytes = 24;            // Number of bytes for each measurement entry
  unsigned int samplingRate = DEFAULT_SR;   // The samplingrate
  StreamType stream = StreamType::USB;      // Channel over which to send
  unsigned int countdown = 0;               // Start at specific time or immidiately
  uint32_t chunkSize = 0;                   // Chunksize of one packet sent
  IPAddress ip;                             // Ip address of data sink
  uint16_t port = STANDARD_TCP_SAMPLE_PORT; // Port of data sink
  size_t numValues = 24/sizeof(float);
  Timestamp startTs;
  Timestamp stopTs;
  int slots = 0;
  int slot = 0;
};
bool rts; // ready to send

int correctSamples = 0;

char measureStr[MAX_MEASURE_STR_LENGTH] = {'\0'};
char unitStr[MAX_UNIT_STR_LENGTH] = {'\0'};

StreamConfig streamConfig;

// Internal samplingrate always either 8k or 32k other sr are derived by leavout samples...
int intSamplingRate = 8000;
uint8_t leavoutSamples = 0;

// Stuff for frequency calculation
volatile long freqCalcStart;
volatile long freqCalcNow;
volatile long freq = 0;

// TCP clients and current connected state, each client is assigned a logger
WiFiClient client[MAX_CLIENTS];
bool clientConnected[MAX_CLIENTS] = {false};
StreamLogger * streamLog[MAX_CLIENTS];

// Strean client is for ffmpeg direct streaming
WiFiClient streamClient;
// tcp stuff is send over this client 
// Init getter to point to sth, might not work otherwise
Stream * newGetter = (Stream*)&Serial;
// tcp stuff is send over this client 
Stream * sendStream = (Stream*)&Serial;
WiFiClient * sendClient;
// UDP used for streaming
WiFiUDP udpClient;

// Stream client for external stream server
WiFiClient exStreamServer;
bool exStreamServerNewConnection = true;

// Command stuff send over what ever
char command[COMMAND_MAX_SIZE] = {'\0'};
StaticJsonDocument<2*COMMAND_MAX_SIZE> docRcv;
StaticJsonDocument<2*COMMAND_MAX_SIZE> docSend;
StaticJsonDocument<COMMAND_MAX_SIZE> docSample;

String response = "";

// Information about the current sampling period
unsigned long samplingCountdown = 0;
unsigned long startSamplingMillis = 0;
unsigned long samplingDuration = 0;
unsigned long sentSamples = 0;
volatile unsigned long packetNumber = 0;
volatile unsigned long totalSamples = 0;

// Some timer stuff s.t. things are updated regularly and not at full speed
long lifenessUpdate = millis();
long mdnsUpdate = millis();
long tcpUpdate = millis();
long rtcUpdate = millis();
long mqttUpdate = millis();

// Current CPU speed
unsigned int coreFreq = 0;


// test stuff
bool criticalMsgAvailable = false;
portMUX_TYPE criticalMsgMux = portMUX_INITIALIZER_UNLOCKED;
char criticalMsg[MAX_MQTT_PUB_TOPIC_INFO] = {'\0'};
long testMillis = 0;
long testMillis2 = 0;
uint16_t testSamples = 0;

portMUX_TYPE correctionMux = portMUX_INITIALIZER_UNLOCKED;

// Mutex for 1s RTC Interrupt
portMUX_TYPE sqwMux = portMUX_INITIALIZER_UNLOCKED;
portMUX_TYPE intterruptSamplesMux = portMUX_INITIALIZER_UNLOCKED;
bool firstSqwv = true;
volatile int sqwCounter = 0;
volatile int sqwCounter2 = 0;

volatile uint32_t interruptSamples = 0;

// Must be large enough to handle maximum mnumber of floats for one measurement
// e.g. V_L1, V_L2, V_L3, I_L1, I_L2, I_L3
float values[7] = {0};

TaskHandle_t xHandle = NULL;

bool updating = false;

char mqttTopicPubSwitch[MAX_MQTT_PUB_TOPIC_SWITCH+MAX_NAME_LEN] = {'\0'};
char mqttTopicPubSample[MAX_MQTT_PUB_TOPIC_SAMPLE+MAX_NAME_LEN] = {'\0'};
char mqttTopicPubInfo[MAX_MQTT_PUB_TOPIC_INFO+MAX_NAME_LEN] = {'\0'};


// HW Timer and mutex for sapmpling ISR
hw_timer_t * timer = NULL;
portMUX_TYPE counterMux = portMUX_INITIALIZER_UNLOCKED;

void (*outputWriter)(bool) = &writeChunks;
/************************ SETUP *************************/
void setup() {
  // Setup serial communication
  Serial.begin(SERIAL_SPEED);
  pinMode(ERROR_LED, OUTPUT);
  digitalWrite(ERROR_LED, HIGH);

  // At first init the rtc module to get 
  bool successAll = true;

  bool success = rtc.init();
  
  // Init the logging module
  logger.setTimeGetter(&timeStr);
  // Add Serial logger
  logger.addLogger(&serialLog);
  // Add spiffs logger
  logger.addLogger(&spiffsLog);
  // Init all loggers
  logger.init();
  // init the stream logger array
  for (size_t i = 0; i < MAX_CLIENTS; i++) {
    StreamLogger * theStreamLog = new StreamLogger(NULL, &timeStr, &LOG_PREFIX[0], INFO);
    streamLog[i] = theStreamLog;
  }

  
  config.init();
  config.load();

  coreFreq = getCpuFrequencyMhz();
  logger.log(DEBUG, "%s @ firmware %s/%s", config.name, __DATE__, __TIME__);
  logger.log(DEBUG, "Core @ %u MHz", coreFreq);


  success = ringBuffer.init();
  if (!success) logger.log(ERROR, "PSRAM init failed");
  successAll &= success;
  // Try to use internal ram for buffering, but still indicate the missing ram
  if (!success) {
    success = ringBuffer.setSize(RAM_BUF_SIZE, false);
    if (!success) logger.log(ERROR, "RAM init failed: %i bytes", RAM_BUF_SIZE);
  }
  // NOTE: ERROR LED and ADE PM1 share the same pin.
  // For normal working condition, PM1 need to be low
  digitalWrite(ERROR_LED, LOW);

  // Setup ADE9000
  ade9k.initSPI(ADE_SCK, ADE_MISO, ADE_MOSI, ADE_CS);
  success = ade9k.init(&isr_adc_ready);
  if (!success) logger.log(ERROR, "ADE Init Failed");
  successAll &= success;
  
  if (successAll) digitalWrite(ERROR_LED, LOW);
  else digitalWrite(ERROR_LED, HIGH);
  logger.log(ALL, "Connecting Network");

  Network::init(&config, onNetworkConnect, onNetworkDisconnect, true);
  Network::initPHY(ETH_ADDR, ETH_POWER_PIN, ETH_MDC_PIN, ETH_MDIO_PIN, ETH_TYPE, ETH_CLK_MODE);
  setupOTA();

  response.reserve(2*COMMAND_MAX_SIZE);

  // Set mqtt and callbacks
  mqtt.init(config.mqttServer, config.name);
  mqtt.onConnect = &onMQTTConnect;
  mqtt.onDisconnect = &onMQTTDisconnect;
  mqtt.onMessage = &mqttCallback;

  timer_init();

  // Init send buffer
  snprintf((char *)&sendbuffer[0], SEND_BUF_SIZE, "%s", DATA_PREFIX);

  // print some info about this powermeter
  printInfoString();

  // TODO: This is only for testing purpose, if sqwv interrupt gets lost without sampling
  // if (rtc.connected) {
  //   rtc.enableInterrupt(1, sqwvTriggered2); // TODO
  //   setupSqwvInterrupt();
  // }
  logger.log(ALL, "Setup done");
}

/************************ Loop *************************/
void loop() {
  // We don't do anything else while updating
  if (updating) return;

  // Stuff done on idle
  if (state == SampleState::IDLE) {
    onIdle();
  // Stuff on sampling
  } else {
    onSampling();
  }

  onIdleOrSampling();
  
  // If we only have 200 ms before sampling should start, wait actively
  if (next_state != SampleState::IDLE) {
    if (streamConfig.countdown != 0 and (streamConfig.countdown - millis()) < 200) {
      // Disable any wifi sleep mode
      if (not Network::ethernet) esp_wifi_set_ps(WIFI_PS_NONE);
      state = next_state;
      logger.log(DEBUG, "StartSampling @ %s", myTime.timeStr());
      // Calculate time to wait
      int32_t mydelta = streamConfig.countdown - millis();
      // Waiting here is not nice, but we wait for zero crossing
      if (mydelta > 0) delay(mydelta-1);
      if (state == SampleState::SAMPLE) {
        startSampling();
      } else {
        startLatchedSampling(true);
      }
      // Reset sampling countdown
      streamConfig.countdown = 0;
    }
  }

  // if (criticalMsgAvailable) {
  //   portENTER_CRITICAL(&criticalMsgMux);
  //   criticalMsgAvailable = false;
  //   portEXIT_CRITICAL(&criticalMsgMux);
  //   if (not firstSqwv and testMillis2 > 1050) {
  //     logger.log(ERROR, "Sqwv took: %li ms", testMillis2);
  //     if (firstSqwv) firstSqwv = false;
  //   } else {
  //     logger.log(INFO, "Sqwv took: %li ms", testMillis2);
  //   }
  // }

  // Watchdog
  yield();
}

/****************************************************
 * What todo independent of sampling state
 ****************************************************/
void onIdleOrSampling() {
  // MQTT loop
  mqtt.update();


  #ifndef CMD_OVER_SERIAL_WHILE_TCP_SAMPLING
  if (streamConfig.stream == StreamType::USB or state == SampleState::IDLE) {
  #endif  
    // Handle serial requests
    if (Serial.available()) {
      logger.log(ERROR, "MESSAGE Over Serial");
      handleEvent(&Serial);
    }
  #ifndef CMD_OVER_SERIAL_WHILE_TCP_SAMPLING
  }
  #endif  

  // Handle tcp requests
  for (size_t i = 0; i < MAX_CLIENTS; i++) {
    if (client[i].available() > 0) {
      handleEvent(&client[i]);
    }
  }

  // Handle tcp clients connections

  if ((long)(millis() - tcpUpdate) >= 0) {
    tcpUpdate += TCP_UPDATE_INTERVAL;
    // Handle disconnect
    for (size_t i = 0; i < MAX_CLIENTS; i++) {
      if (clientConnected[i] and !client[i].connected()) {
        onClientDisconnect(client[i], i);
        clientConnected[i] = false;
      }
    }

    // Handle connect
    WiFiClient newClient = server.available();
    if (newClient) {
      onClientConnect(newClient);
    }
  }
}

/****************************************************
 * Things todo regularly if we are not sampling
 ****************************************************/
void onIdle() {

  // Arduino OTA
  ArduinoOTA.handle();
  
  spiffsLog.flush();

  // Re-advertise MDNS service service every 30s 
  // TODO: no clue why, but does not work properly for esp32 (maybe it is the mac side)
  if ((long)(millis() - mdnsUpdate) >= 0) {
    mdnsUpdate += MDNS_UPDATE_INTERVAL;
    if ((long)(millis() - mdnsUpdate) >= 0) mdnsUpdate = millis() + MDNS_UPDATE_INTERVAL; 
    // initMDNS();
    //MDNS.addService("_elec", "_tcp", STANDARD_TCP_STREAM_PORT);
  }

  if ((long)(millis() - rtcUpdate) >= 0) {
    rtcUpdate += RTC_UPDATE_INTERVAL;
    if ((long)(millis() - rtcUpdate) >= 0) rtcUpdate = millis() + RTC_UPDATE_INTERVAL; 
    if (rtc.connected) rtc.update();
  }
    
  // Update lifeness only on idle every second
  if ((long)(millis() - lifenessUpdate) >= 0) {
    lifenessUpdate += LIFENESS_UPDATE_INTERVAL;
    if ((long)(millis() - lifenessUpdate) >= 0) lifenessUpdate = millis() + LIFENESS_UPDATE_INTERVAL; 
    logger.log("");
  }

  // Update stuff over mqtt
  if (mqtt.connected()) {
    if ((long)(millis() - mqttUpdate) >= 0) {
      mqttUpdate += MQTT_UPDATE_INTERVAL;
      // On long time no update, avoid multiupdate
      if ((long)(millis() - mqttUpdate) >= 0) mqttUpdate = millis() + MQTT_UPDATE_INTERVAL; 
      sendStatusMQTT();
    }
  }
  
  /*
   * NOTE: The streamserver has to send start signal by itself now,
   * Lets see if this is a better idea
   * If you want to reenable automatic sending, uncomment it
   * exStreamServer is now more an external server where we announce that we are now ready
   * to send data
   */
  // Check external stream server connection
  // if (exStreamServer.connected() and exStreamServerNewConnection) {
  //   logger.log("Stream Server connected start sampling");
  //   // If streamserver sends stop, we need a way to prevent a new start of sampling
  //   // This is how we achieve it.
  //   exStreamServerNewConnection = false;
  //   // Set everything to default settings
  //   standardConfig();
  //   streamConfig.port = STANDARD_TCP_STREAM_PORT;
  //   sendClient = (WiFiClient*)&exStreamServer;
  //   sendStream = sendClient;
  //   startSampling();
  //   // Must be done after start st startTS is in data
  //   sendStreamInfo(sendClient);
  // }

  // Look for people connecting over the stream server
  // If one connected there, immidiately start streaming data
  if (!streamClient.connected()) {
    streamClient = streamServer.available();
    if (streamClient.connected()) {
      standardConfig();
      streamConfig.prefix = false;
      streamConfig.port = STANDARD_TCP_STREAM_PORT;
      sendClient = (WiFiClient*)&streamClient;
      sendStream = sendClient;
      startSampling();
    }
  }
}

/****************************************************
 * Send Status info over mqtt 
 ****************************************************/
void sendStatusMQTT() {
  JsonObject obj = docSend.to<JsonObject>();
  obj.clear();

  float value = 0.0;


  
  ade9k.readActivePower(&values[0]);
  value = values[0]+values[1]+values[2];
  docSend["power"] = round2<float>(value);

  // We want current in A
  ade9k.readCurrentRMS(&values[0]);
  value = values[0]+values[1]+values[2]+values[3];
  docSend["current"] = round2<float>(value/1000.0);

  // unit is watt hours and we want kwj
  // TODO: This needs some major reworking
  // ade9k.readActiveEnergy(&data[0], &logger);
  // docSend["energy"] = value;

  // use avg voltage here
  ade9k.readVoltageRMS(&values[0]);
  value = (values[0]+values[1]+values[2])/3.0;
  docSend["volt"] = round2<float>(value);
  
  docSend["ts"] = myTime.timestampStr(true);
  response = "";
  serializeJson(docSend, response);
  logger.log("MQTT msg: %s", response.c_str());
  mqtt.publish(mqttTopicPubSample, response.c_str());
}

/****************************************************
 * Send Stream info to 
 ****************************************************/
void sendDeviceInfo(Stream * sender) {
  JsonObject obj = docSend.to<JsonObject>();
  obj.clear();
  docSend["cmd"] = "info";
  docSend["type"] = F("smartmeter");
  docSend["version"] = VERSION;
  String compiled = __DATE__;
  compiled += " ";
  compiled += __TIME__;
  docSend["compiled"] = compiled;
  docSend["sys_time"] = myTime.timeStr();
  docSend["name"] = config.name;
  docSend["ip"] = Network::localIP().toString();
  docSend["mqtt_server"] = config.mqttServer;
  docSend["stream_server"] = config.streamServer;
  docSend["time_server"] = config.timeServer;
  docSend["sampling_rate"] = streamConfig.samplingRate;
  docSend["buffer_size"] = ringBuffer.getSize();
  docSend["psram"] = ringBuffer.inPSRAM();
  docSend["rtc"] = rtc.connected;
  docSend["state"] = state != SampleState::IDLE ? "busy" : "idle";
  String ssids = "[";
  for (size_t i = 0; i < config.numAPs; i++) {
    ssids += config.wifiSSIDs[i];
    if (i < config.numAPs-1) ssids += ", ";
  }
  ssids += "]";
  docSend["ssids"] = ssids;
  docSend["ssid"] = WiFi.SSID();
  response = "";
  serializeJson(docSend, response);
  response = LOG_PREFIX + response;
  sender->println(response);
}

/****************************************************
 * Send Stream info to 
 ****************************************************/
void sendStreamInfo(Stream * sender) {
  JsonObject obj = docSend.to<JsonObject>();
  obj.clear();
  docSend["name"] = config.name;
  docSend["measures"] = measuresToStr(streamConfig.measures);
  docSend["chunksize"] = streamConfig.chunkSize;
  docSend["samplingrate"] = streamConfig.samplingRate;
  docSend["measurements"] = streamConfig.numValues;
  docSend["prefix"] = streamConfig.prefix;
  docSend["cmd"] = CMD_SAMPLE;
  docSend["unit"] = unitToStr(streamConfig.measures);
  response = "";
  serializeJson(docSend, response);
  response = LOG_PREFIX + response;
  sender->println(response);
}

/****************************************************
 * return unit as str
 ****************************************************/
char * unitToStr(Measures measures) {
  switch (measures) {
    case Measures::VI:
      snprintf(unitStr, MAX_UNIT_STR_LENGTH, UNIT_VI);
      break;
    case Measures::VI_L1:
    case Measures::VI_L2:
    case Measures::VI_L3:
      snprintf(unitStr, MAX_UNIT_STR_LENGTH, UNIT_VI_LX);
      break;
    case Measures::PQ:
      snprintf(unitStr, MAX_UNIT_STR_LENGTH, UNIT_PQ);
      break;
    case Measures::VI_RMS:
      snprintf(unitStr, MAX_UNIT_STR_LENGTH, UNIT_VI_RMS);
      break;
    default:
      snprintf(unitStr, MAX_UNIT_STR_LENGTH, "unknown");
      break;
  }
  return &unitStr[0];
}

/****************************************************
 * Convert measure to str
 ****************************************************/
char * measuresToStr(Measures measures) {
  switch (measures) {
    case Measures::VI:
      snprintf(measureStr, MAX_MEASURE_STR_LENGTH, MEASURE_VI);
      break;
    case Measures::VI_L1:
      snprintf(measureStr, MAX_MEASURE_STR_LENGTH, MEASURE_VI_L1);
      break;
    case Measures::VI_L2:
      snprintf(measureStr, MAX_MEASURE_STR_LENGTH, MEASURE_VI_L2);
      break;
    case Measures::VI_L3:
      snprintf(measureStr, MAX_MEASURE_STR_LENGTH, MEASURE_VI_L3);
      break;
    case Measures::PQ:
      snprintf(measureStr, MAX_MEASURE_STR_LENGTH, MEASURE_PQ_LONG);
      break;
    case Measures::VI_RMS:
      snprintf(measureStr, MAX_MEASURE_STR_LENGTH, MEASURE_VI_RMS_LONG);
      break;
    default:
      snprintf(measureStr, MAX_MEASURE_STR_LENGTH, "unknown");
      break;
  }
  return &measureStr[0];
}

/****************************************************
 * Set standard configuration
 ****************************************************/
void standardConfig() {
  streamConfig.slot = 0;
  streamConfig.slots = 0;
  streamConfig.stream = StreamType::TCP;
  streamConfig.prefix = true;
  streamConfig.flowControl = false;
  streamConfig.samplingRate = DEFAULT_SR;
  streamConfig.measures = Measures::VI;
  streamConfig.ip = streamClient.remoteIP();
  streamConfig.port = STANDARD_TCP_SAMPLE_PORT;
  outputWriter = &writeChunks;
  streamConfig.measurementBytes = 8;
  streamConfig.measurementBytes = 24;
  streamConfig.numValues = streamConfig.measurementBytes/sizeof(float);
  calcChunkSize();
  rts = true;
}
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

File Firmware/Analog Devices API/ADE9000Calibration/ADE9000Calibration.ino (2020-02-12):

 /*Calibrates ADE9000*/
/*The calibration inputs are stored in the ADE9000CalibrationInputs.h file. The phase and parameter being calibrated is input through the serial console*/
/*Calbration constants are computed and stored in the EEPROM */
/*Caibration should be done with the end application settings. If any  parameters(GAIN,High pass corner,Integrator settings) are changed, the device should be recalibrated*/
/*This application assumues the PGA_GAIN among all current channels is same.Also, the PGA_GAIN among all voltage channels should be same*/

#include <SPI.h>
#include "ADE9000RegMap.h"
#include "ADE9000API.h"
#include "ADE9000CalibrationInputs.h"
#include <math.h>
#include <Wire.h>


/*Function declerations*/
void ADE9000_calibrate();
void ADE9000_iGain_calibrate(int32_t *,int32_t *,int32_t *,int32_t *, int);     //Current gain calibration function
void ADE9000_vGain_calibrate(int32_t *,int32_t *,int32_t *,int32_t *, int);     //Voltage gain calibration function
void ADE9000_pGain_calibrate(int32_t *,int32_t *,int32_t *,int32_t *, float);   //Power gain calibration function
void ADE9000_phase_calibrate(int32_t *,int32_t *,int32_t *,int32_t *, int);     //Phase calibration function
void calibrationEnergyRegisterSetup();                                          //Setup of Energy registers used in calibration. Donot Edit
void getPGA_gain();
int8_t isRegisterPositive(int32_t);
void storeCalConstToEEPROM();


#define IGAIN_CAL_REG_SIZE 4  
int32_t xIgain_registers[IGAIN_CAL_REG_SIZE];   //order [AIGAIN, BIGAIN, CIGAIN, NIGAIN]
int32_t xIgain_register_address[IGAIN_CAL_REG_SIZE]=
         {ADDR_AIGAIN, ADDR_BIGAIN, ADDR_CIGAIN, ADDR_NIGAIN};   //order [AIGAIN, BIGAIN, CIGAIN, NIGAIN]
int32_t xIrms_registers[IGAIN_CAL_REG_SIZE];
int32_t xIrms_registers_address[IGAIN_CAL_REG_SIZE]= {ADDR_AIRMS, ADDR_BIRMS, ADDR_CIRMS, ADDR_NIRMS};

#define VGAIN_CAL_REG_SIZE 3
int32_t xVgain_registers[VGAIN_CAL_REG_SIZE];   //order [AVGAIN, BVGAIN, CVGAIN]
int32_t xVgain_register_address[VGAIN_CAL_REG_SIZE]={ADDR_AVGAIN, ADDR_BVGAIN, ADDR_CVGAIN};   //order [AVGAIN, BVGAIN, CVGAIN]
int32_t xVrms_registers[VGAIN_CAL_REG_SIZE];
int32_t xVrms_registers_address[VGAIN_CAL_REG_SIZE]= {ADDR_AVRMS, ADDR_BVRMS, ADDR_CVRMS};

#define PHCAL_CAL_REG_SIZE 3
int32_t xPhcal_registers[PHCAL_CAL_REG_SIZE];   //order [APHCAL, BPHCAL, CPHCAL]
int32_t xPhcal_register_address[PHCAL_CAL_REG_SIZE]={ADDR_APHCAL0, ADDR_BPHCAL0, ADDR_CPHCAL0};   //order [APHCAL, BPHCAL, CPHCAL]
int32_t xWATTHRHI_registers[PHCAL_CAL_REG_SIZE];  //Active energy registers
int32_t xWATTHRHI_registers_address[PHCAL_CAL_REG_SIZE]= {ADDR_AWATTHR_HI, ADDR_BWATTHR_HI, ADDR_CWATTHR_HI};
int32_t xVARHRHI_registers[PHCAL_CAL_REG_SIZE];
int32_t xVARHRHI_registers_address[PHCAL_CAL_REG_SIZE]= {ADDR_AVARHR_HI, ADDR_BVARHR_HI, ADDR_CVARHR_HI};

#define PGAIN_CAL_REG_SIZE 3
int32_t xPgain_registers[PGAIN_CAL_REG_SIZE];   //order [APGAIN, BPGAIN, CPGAIN]
int32_t xPgain_register_address[PGAIN_CAL_REG_SIZE]={ADDR_APGAIN, ADDR_BPGAIN, ADDR_CPGAIN};   //order [AVGAIN, BVGAIN, CVGAIN, NVGAIN]
//The Power gain calibration reads active energy registers. The content and address arrays are defined in the PHCAL section above

//Global variables
#define EGY_REG_SIZE 3
int8_t calCurrentPGA_gain=0;
int8_t calVoltagePGA_gain=0;
int32_t accumulatedActiveEnergy_registers[EGY_REG_SIZE];
int32_t accumulatedReactiveEnergy_registers[EGY_REG_SIZE];
uint32_t calibrationDataToEEPROM[CALIBRATION_CONSTANTS_ARRAY_SIZE];

ADE9000Class ade9000;


#define SPI_SPEED 5000000     //SPI Speed
#define CS_PIN 14 //8-->Arduino Zero. 16-->ESP8266 
#define ADE9000_RESET_PIN 2 //Reset Pin on HW
#define PM_1 4              //PM1 Pin: 4-->Arduino Zero. 15-->ESP8266 
#define SCK_PIN 12
#define MISO_PIN 13
#define MOSI_PIN 15
#define IRQ0_INTERRUPT_PIN 36

#define INT_MODE FALLING
#define ACCUMULATION_TIME 5                 //accumulation time in seconds when EGY_TIME=7999, accumulation mode= sample based
#define EGY_INTERRUPT_MASK0 0x00000001      //Enable EGYRDY interrupt

enum CAL_STATE
{
  CAL_START,
  CAL_VI_CALIBRATE,
  CAL_PHASE_CALIBRATE,
  CAL_PGAIN_CALIBRATE,
  CAL_STORE,
  CAL_STOP,
  CAL_RESTART,
  CAL_COMPLETE
};


CAL_STATE CUR_STATE = CAL_START;   //current state is start

void setup() {
  Serial.begin(115200);
  
  pinMode(PM_1, OUTPUT);    //Set PM1 pin as output 
  digitalWrite(PM_1, LOW);   //Set PM1 select pin low for PSM0 mode
  pinMode(ADE9000_RESET_PIN, OUTPUT);
  digitalWrite(ADE9000_RESET_PIN, HIGH); 
  resetADE9000(); 
  delay(1000);

  ade9000.SPI_Init(SPI_SPEED,CS_PIN, SCK_PIN, MISO_PIN, MOSI_PIN); //Initialize SPI
  ade9000.SetupADE9000();       /*Setup ADE9000. The setup parameters such as 
                                GAIN should not be changed after calibration. Recalibrate if any configuration affecting the digital datapath changes.*/
  Serial.print("RUN Register: ");
  Serial.println(ade9000.SPI_Read_16(ADDR_RUN),HEX);

  calibrationEnergyRegisterSetup();
  getPGA_gain();  
  Wire.begin(); 
  ade9000.writeByteToEeprom(ADDR_EEPROM_WRITTEN_BYTE,~(EEPROM_WRITTEN)); //clear calibration done status 
}

void loop()
{
  delay(1000);
  ADE9000_calibrate();
}
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

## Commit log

2018-11-07 initial commit of current working ino file
2018-11-07 Added UDP ready Version
    [Berechnung.ods]
2019-09-06 Added Versioning and fixed \r\n buf
    [ADE9000.cpp, ADE9000_PORT.h]
2019-11-22 Subrepos added, Firmware Version 2.0 basicly running
    - Repos from smartenergy.powermeter (e.g. rinngbuffer,rtc,etc.) finally embedded into smartmeter as subrepos
    - Subrepos must be placed and cloned into each Firmware version separately in <ino Folder>/src/<subrepo name> (use git submodule add http://foo.git bar/)
    - Version 2.0 is basically running with ADE9000:
    -- will not work with old Board HW (#define pins of ADE have changed)
    -- keeping samplingrate is a bit hacky and will only work if external ADE CLK is faster than RTC
    -- samplerates can only be chosen as /2 devider of 32 kHz (16k,8k,4k,2k,1k,1.6k,0.8k,0.5k,0.4k,0.2k,0.1k)
    -- includes support for LAN7280 Ethernet PHY.
    -- SPI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
    [Version_2_0.ino, constDefine.h]
2019-12-02 Fixed sampling causing reset after second sampling attempt
    [Version_2_0.ino]
2020-01-20 added solidworks 3D parts of housing and nc files
    [DinHousing_lower.SLDPRT, DinHousing_upper.SLDPRT, MR6_C.brd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]
2020-02-05 Added MQTT to V2, added working version 1_1, added arduino pluugins
2020-02-06 added parse command ino fie
    [sample.sch]
2020-02-11 fiexed MQTT bug and added ade9000 rms and power reading
    [Version_2_0.ino, constDefine.h, parseCommand.ino]
2020-02-12 added datasheet of ade9000, added arduino files from analog devices
2020-02-19 hotfix, OTA not working due to streamserver connect
    [Version_2_0.ino]
2020-02-20 fixed issue #453 -> null on mqtt sampling and #454 -> stop command
    [Version_2_0.ino, constDefine.h, parseCommand.ino]
2020-03-12 Added PowerMeterV2 to Arduino Boards txt
2020-05-12 Fixing bug #485 hopefully, at least working on it..
    [Version_2_0.ino, constDefine.h, parseCommand.ino]
2021-03-08 reference to powermeter
2021-03-08 changed to new unified ESP32 ESP8266 libraries
2021-03-08 relative include for arduino
2021-08-12 added energy, calibration, and reset command
2021-08-12 Support for energy
    [ADE9000 _Calibration_Tool_Rev0.xlsm]
2021-11-03 fixed measurement jitter by reverting to ISR used for FIRED
    [Version_2.ino, constDefine.h]
2026-11-06 Fix sendStatus current sum, round2 rounding and known networks print
2026-11-06 Fix command handlers: reqSamples bounds, apparent power, addWifi and ntp result
2026-11-06 Stop sampling tasks on stop and pad missing samples outside the ISR

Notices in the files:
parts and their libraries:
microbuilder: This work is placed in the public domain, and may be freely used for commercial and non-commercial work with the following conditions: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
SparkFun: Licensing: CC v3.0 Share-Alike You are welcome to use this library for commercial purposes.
